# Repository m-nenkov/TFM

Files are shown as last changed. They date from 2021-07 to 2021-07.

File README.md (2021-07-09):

# TFM : Modelo y diseño de un sistema control de una estructura de dos grados de libertad

El repositorio presente corresponde al trabajo realizado para obetener el título de Máster Universitaro en Ingeniería de Sistemas Electrónicos en la UPM.

Este TFM se ha realizado en el laborratiro de Robótica y Control (Robolabo) de la ETSIT.

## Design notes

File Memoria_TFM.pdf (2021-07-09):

## UNIVERSIDAD POLITECNICA DE MADRID ´

ESCUELA TECNICA SUPERIOR ´
DE INGENIEROS DE TELECOMUNICACION´

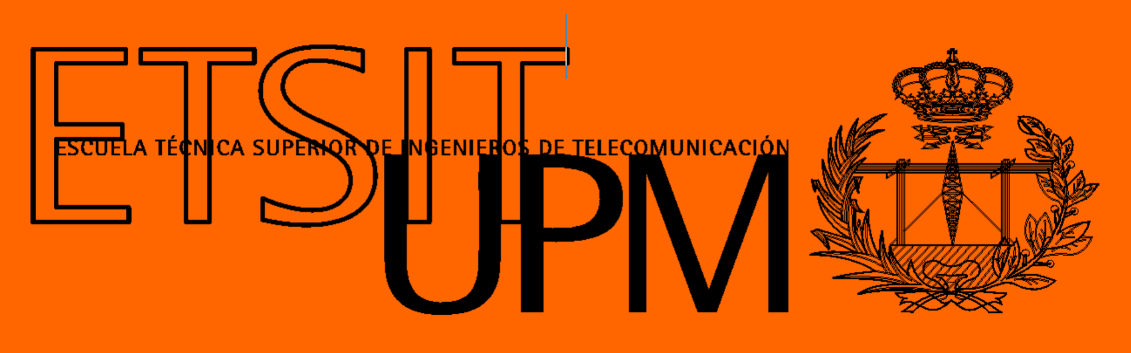
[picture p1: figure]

MASTER UNIVERSITARIO EN INGENIER ´ | ÍA DE

## SISTEMAS ELECTRONICOS ´

TRABAJO FIN DE MASTER ´

## MODELADO Y DISENO DE UN SISTEMA ˜

## CONTROL DE UNA ESTRUCTURA DE BALANCEO DE DOS GRADOS DE LIBERTAD

## MARTIN NENKOV GOROSTANOV

2021

## UNIVERSIDAD POLITECNICA DE MADRID ´

ESCUELA TECNICA SUPERIOR ´
DE INGENIEROS DE TELECOMUNICACION´

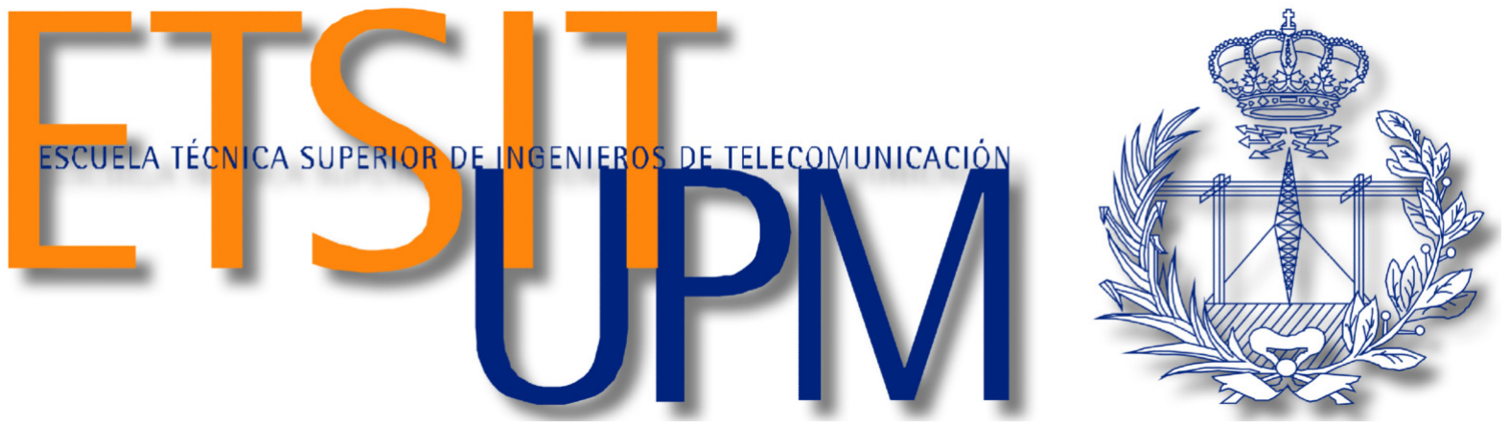
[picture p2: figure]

MASTER UNIVERSITARIO EN INGENIER ´ | ÍA DE

## SISTEMAS ELECTRONICOS ´

TRABAJO FIN DE MASTER ´

## MODELADO Y DISENO DE UN SISTEMA ˜

## CONTROL DE UNA ESTRUCTURA DE BALANCEO DE DOS GRADOS DE LIBERTAD

## Autor MARTIN NENKOV GOROSTANOV

## Tutor

ALVARO GUTI ´ | ERREZ MART ´ | ÍN

2021

Resumen

El control automatizado ha desempeñado un papel muy importante en el avance de la ingeniería en las últimas décadas. Es una parte fundamental de los sistemas robóticos, sistemas de vehículos autónomos y, en general, en cualquier proceso industrial en el que se requiera de un ajuste preciso de posición, temperatura, humedad, etc.

La ingeniería de control realiza un estudio de los sistemas físicos con el objetivo de desarrollar controladores capaces de dirigir estos sistemas hacia un estado objetivo. En la industria, la implementación de estos controladores se realiza por parte de los ingenieros electrónicos, mediante el uso de microcontroladores, que son los encargados de procesar la señal de entrada, calcular la acción de control y dar la orden a los actuadores.

Nuestra labor, como ingenieros electrónicos, está fuertemente ligada a este trabajo de implementación. Por lo tanto, es necesario conocer las distintas técnicas de control que existen, con el objetivo de realizar una implementación mas fluida e incluso para poder optimizar estos controladores o las arquitecturas en las que serán implementados.

En este Trabajo Fin de Máster se propone el control de una estructura de dos grados de libertad con el objetivo de analizar su respuesta real frente a la modelada y la viabilidad de la implementación del sistema. Para cumplir con el objetivo del proyecto, se ha decidido dividir el trabajo en varias etapas. Inicialmente, se propone realizar un análisis del modelado físico del sistema con el objetivo de conocer su respuesta temporal ante determinadas perturbaciones. A continuación, se realizará el diseño y simulación de los controladores con los que se propone realizar el control en posición de una esfera colocada en la estructura. Además, en este Trabajo Fin de Máster se propone el diseño de dos controladores, uno corresponde con la teoría de control clásica, que busca realizar un control temporal de los sistemas y un segundo controlador, basado en la teórica de control óptimo, en el que el objetivo es desarrollar un controlador que satisfaga una determinada función de coste. Por último, se realizará la implementación, ajuste y la validación del control en un microcontrolador.

vi

Abstract

Automated control has played a very important role in the advancement of engineering in recent decades. It is a fundamental part of robotics, autonomous vehicles and, in general, in any industrial process where precise control of position, temperature, humidity, etc. is required.

Control engineering studies physical systems with the aim of developing controllers capable of directing these systems towards a target state. In industry, the implementation of these controllers is carried out by electronic engineers, through the use of microcontrollers, which are responsible for processing the input signal, calculating the control signal and giving the order to the actuators.

Our work as electronic engineers is strongly related to this work. Therefore, it is necessary to know the different control techniques that exist, with the aim of making a smoother implementation and to be able to optimise these controllers or the architectures in which they will be implemented.

This Msc Thesis proposes the control of a structure with two degrees of freedom in order to analyse its real response compared to that modelled and the feasibility of the implemented solution. In order to fulfil the objective of the project, it is divided into several stages. Initially, it is proposed to carry out an analysis of the physical modelling of the system in order to determine its temporal response to certain disturbances. Next, the design and simulation of the controllers has to be done with which the control of the position of the sphere will be made. In addition, this Master’s Thesis proposes the design of two controllers, one corresponding to the classical control theory, which seeks to perform a temporal control of the systems and a second controller, based on the theory of optimal control, in which the objective is to develop a controller that satisfies a certain cost function. Finally, the control will be implemented in a microcontroller and its adjustment and validation will be carried out.

viii

´

# Indice general

Resumen | V
Abstract | VII
Índice General | IX
Índice de Figuras | XIII
Índice de Tablas | XV
Lista de Acrónimos | XVII
1. Introducción | 1
2. Modelado de un sistema Ball and Plate | 5
2.5.1.1. Sintonización del controlador mediante el LDR . . . . | 22
3. Descripción del hardware del sistema | 29

ix

x | ÍNDICE GENERAL
4. Diseño e implementación del sistema | 39
5. Resultados y validación del sistema completo | 59
6. Conclusiones | 67
Bibliografía | 72
A. Esquemáticos y circuito impreso de la tarjeta de expansión | 73
B. Diseño de las máquinas de estados finitas | 79
B.2. Cálculo de la acción de control y actuación sobre servo-motores . . . . | 80
C. Análisis del periodo de diferenciación | 83

ÍNDICE GENERAL | xi
D. Aspectos éticos, económicos, sociales y ambientales | 87
E. Presupuesto económico | 89

xii | ÍNDICE GENERAL

´

# Indice de figuras

2.1. Sistema de control en lazo cerrado | | 6
2.2. Representación de la estructura. Researchgate | | 7
2.3. Sistema realimentado en lazo cerrado. Dademuch | | 10
2.4. Representación del espacio de estados. Springer | | 12
2.5. Respuesta temporal de un sistema de segundo orden a una entrada
escalón. ELAI-UPM | | 14
2.6. Lugar de las raíces del sistema sin controlador | | 20
2.7. Sistema realimentado con controlador PID. Researchgate | | 21
2.8. Sistema realimentado con controlador LQR. Springer | | 24
3.1. Fotografía de la estructura mecánica del sistema | | 29
3.2. Relación entre ángulo del servo-motor y plataforma | | 30
3.3. Esquema del circuito resistivo de la pantalla táctil. Microchip | | 31
3.4. Fotografía de la cámara OpenMV Cam H7. OpenMV | | 32
3.5. Fotografía de un servo-motor. Bricogeek | | 34
3.6. Fotografía de la placa de desarrollo. STMicroelectronics | | 35
4.1. Diagrama de tiempos de la señal PWM para el control de los servo-
motores. PanamaHitek | | 44
4.2. Estructura del código implementado | | 45
4.3. Respuesta del sistema ante distintos periodos de muestro | | 47
4.4. Respuesta del sistema aplicando el controlador PD diseñado | | 48
4.5. Lugar de las raíces del sistema aplicando el controlador PD diseñado. . | 49
4.6. Respuesta del sistema aplicando el controlador PD diseñado | | 50
4.7. Angulo de la plataforma ante un escalón de 20 centímetros | ´ | 51
5.1. Respuesta del sistema ante el PD teórico | | 60
5.2. Acción de control del sistema ante el PD teórico | | 60
5.3. Respuesta del sistema ante el PD con ajuste de ganancia | | 61
5.4. Respuesta del sistema ante el PD con ajuste de cero | | 61
5.5. Respuesta del sistema ante el PD experimental | | 62
5.6. Respuesta del sistema formado por la cámara ante el PD teórico. . . . | 63
5.7. Respuesta del sistema formado por la cámara ante el PD experimental. 64
5.8. Respuesta del sistema con pantalla resistiva ante el LQR | | 64
5.9. Respuesta del sistema con cámara ante el LQR | | 65
A.1. Esquemático de la tarjeta de expansión | | 74

xiii

xiv | ÍNDICE DE FIGURAS

B.1. Diagrama de entradas y salidas de la máquina de toma de datos de los

B.2. Diagrama de estados de la máquina de toma de datos de los sensores. | 80
B.5. Diagrama de entradas y salidas de la máquina de envío de datos. . . . | 81

B.7. Diagrama de entradas y salidas de la máquina de recepción de comandos. 82 B.8. Diagrama de estados de la máquina de envío de recepción de comandos. 82

C.1. Señal de control del sistema ante diferentes periodos de muestreo. . . . 84 C.2. Respuesta del sistema ante el PD utilizado para el análisis del efecto

´

# Indice de tablas

4.1. Tiempos asociados a la ejecución de las tareas | | 54
4.2. Asignación de prioridades a las Tareas | | 55
4.3. Tiempos de respuesta de las Tareas | | 55
E.1. Costes de personal | | 89
E.2. Costes de recursos materiales | | 90
E.3. Costes totales | | 90

xv

xvi | ÍNDICE DE TABLAS

# Lista de Acrónimos

UPM : Universidad Politécnica de Madrid

ETSIT : Escuela Técnica Superior de Ingenieros de Telecomunicación

TFM : Trabajo Fin de Máster

LTI : Linear Time-Invariant

SISO : Single-Input Single-Output

MIMO : Multiple-Input Multiple-Output

PID : Proportional–Integral–Derivative

LQR : Linear–Quadratic Regulator

LDR : Lugar De las Raíces

I2C : Inter-Integrated Circuit

SPI : Serial Peripheral Interface

UART : Universal Asynchronous Receiver-Transmitter

USB : Universal Serial Bus

RAM : Random-Access Memory

PWM : Pulse-Width Modulation

RTOS : Real-Time Pperating System

FSM : Finite-State Machine

PCB : Printed Circuit Board

FIFO : First In First Out

HAL : Hardware Abstraction Layer

DMA : Direct Memory Access

GPIO : General Purpose Input/Output

SRAM : Static Random-Access Memory

xvii

xviii | LISTA DE ACRONIMOS ´

# Capítulo 1

# Introducción

## 1.1. Introducción a la ingeniería de control

El control automatizado ha desempeñado un papel muy importante en el avance de la ingeniería en las últimas décadas. Es una parte fundamental de los sistemas robóticos[1], sistemas de vehículos autónomos y, en general, en cualquier proceso industrial en el que se requiera de un ajuste preciso de posición, temperatura, humedad, etc.

Al comienzo del siglo pasado, se empiezan a desarrollar controladores para el guiado automático de embarcaciones[2][3], demostrando que es posible controlar de forma estable un sistema a partir de las ecuaciones diferenciales que describen su dinámica. A raíz de estos logros, surgieron teorías que analizaban la estabilidad del sistema en lazo cerrado con su respuesta en lazo abierto. Junto con esto, a mediados de siglo, se desarrollan métodos para observar y analizar la respuesta del sistema en frecuencia, dando la posibilidad de diseñar controladores lineales que satisfagan un amplio conjunto de especificaciones. Esta etapa inicial de la ingeniería de control se conoce como teoría de control clásica, en la que se hace uso de las técnicas comentadas anteriormente, junto con controladores PID realizar el control de sistemas lineales invariantes en el tiempo (LTI) con una entrada y una salida (SISO).

Con el avance de la industria, surgen máquinas más complejas, con respuesta variante en el tiempo y múltiples entradas (MIMO), que requieren de controladores más sofisticados. Debido a esto, surgen teorías de control modernas en las que se realiza un análisis en tiempo de los sistemas y se describe su comportamiento mediante variables de estado. Junto con el desarrollo de la industria, la ingeniería de control aumenta su complejidad desarrollando nuevas teorías, buscando controladores óptimos[4], intentando optimizar la respuesta según un criterio, robustos[5], con el objetivo de asegurar la respuesta del sistema real en un determinado punto de trabajo, o adaptativos[6], capaces de adaptar el controlador en función del estado del sistema.

1

2 1. Introducción

## 1.2. Motivación y objetivos del proyecto

Es fundamental que los ingenieros que realicen tareas de control estén familiariza-dos con las teorías de control que existen y los distintos tipos de controladores que se pueden implementar. Por este motivo, los alumnos de la asignatura de ingeniería de control deben disponer de sistemas reales en los que poder realizar la implementación y validación de estos controladores. La idea de diseñar e implementar un sistema en el que se puedan realizar estas laborares educativas resulta interesante desde el punto de vista pedagógico.

El sistema que se encuentra disponible en el Laboratorio de Control y Robótica de la ETSIT no dispone de información sobre los controladores que implementa o la forma en la que se realizado su ajuste. Por este motivo, para que este sistema permita su uso en el ámbito educativo es necesario realizar una documentación extensa de su diseño, implementación y validación.

En este Trabajo Fin de Máster se propone el control de una estructura de dos grados de libertad con el objetivo de analizar su respuesta real frente a la modelada y la viabilidad de la implementación del sistema. Para cumplir con los objetivo principal del proyecto, es necesario definir algunos objetivos secundarios, es necesario realizar el modelado físico del sistema, diseño y simulación de controladores, implementación del control y por último, el ajuste del sistema y la validación del mismo.

## 1.3. Estructura del documento

Este documento se divide en seis capítulos en los que se detallan todos los pasos que se han seguido, junto con los componentes necesarios para la realización de este Trabajo Fin de Máster.

En el Capítulo 1 se realiza una breve introducción al contexto del TFM y se exponen la motivación y los objetivos de este.

En el Capítulo 2 se detallan los conceptos teóricos en los que se fundamenta este TFM. En estos capítulos se realiza una introducción a las dos teorías de control aplicadas y se explican los conceptos básicos que son necesarios para comprender la implementación del sistema.

En el Capítulo 3 se exponen todos los componentes por los que se compone el proyecto, junto con las decisiones tomadas para su selección. Además, en este capítulo se detallan todos las decisiones relacionadas con el hardware diseñado.

En el Capítulo 4 se expone la metodología que se ha seguido en el proyecto, las principales líneas de trabajo y se desarrolla detalladamente cada una de las partes del sistema. En este capítulo se encuentra el diseño, modelado e implementación del

1.3. Estructura del documento | 3

sistema de control.

Por último, en los Capítulos 5 y 6 se exponen los resultados del proyecto junto con las conclusiones finales, además de incluir un apartado dedicado a posibles futuros trabajos.

4 1. Introducción

# Capítulo 2

# Modelado de un sistema Ball and Plate

Es necesario remontarse a la antigua Grecia para conocer los inicios de la ingeniaría de control. Los antiguos griegos, junto con los bizantinos y los romanos, emplearon sistemas de control para mantener los niveles de sus depósitos de agua, aceite y vino, respectivamente, estables. Para ello emplearon un sistema que, aunque antiguo, se sigue usando en la actualidad. Este sistema consistía en una esfera hueca que flotaba en el líquido y, que a su vez, controlaba el flujo de una válvula. De esta forma, cuando el líquido llegaba al nivel deseado, la válvula era cerrada de forma automática. Este sistema es idéntico al que se utiliza para el control de las cisternas de los inodoros en las casas. Desde entonces, la ingeniaría de control ha seguido desarrollando nuevos controladores, sobre todo gracias a la revolución industrial, capaces de controlar todo tipo de sistemas, desde el control de velocidad de máquinas de vapor hasta el aterrizaje autónomo de naves espaciales, pasando por sistemas de pilotaje automático, robots industriales, etc. En la actualidad existen métodos muy complejos de control capaces de predecir los cambios ambientales por medio de algoritmos de inteligencia artificial, de controlar sistemas no-lineales o, incluso, el desarrollo de los sistemas distribuidos permite un control descentralizado capaz de comunicar diferentes nodos con un objetivo único.

Como se ha comentado en el capítulo 1, existen diferentes estrategias para el control de un sistema. Este TFM se centra en la teoría de control clásica, basada en el análisis de la dinámica de los sistemas, y de control óptimo, centrada en el diseño de controladores que minimicen una determinada función de coste. Para ello se realizará el análisis del sistema siguiendo cada una de estas teorías y la implementación de un controlador de cada tipo.

5

6 2. Modelado de un sistema Ball and Plate

## 2.1. Introducción

El sistema que se pretende controlar es comúnmente conocido en la literatura anglosajona como Ball and Plate, en castellano, Bola y Plato. En este sistema, el objetivo es realizar el control en posición de una esfera maciza, normalmente de metal o de plástico, que se encuentra situada sobre un plato, o plataforma. Otra configuración similar es la que sólo dispone de un grado de libertad, llamada Ball and Beam, en castellano Bola y Viga. Ambas estructuras son comunes en el ámbito educativo, ya que permiten la implementación de una amplia variedad de controladores en una maqueta con un tamaño reducido. En la literatura se pueden encontrar diferentes métodos de adquisición de la posición de la esfera, como por ejemplo, el uso de pantallas resistivas, de cámaras con algoritmos de detección de objetos o, incluso, de sensores ultrasónicos. Por otro lado, para el control de la estructura se han desarrollado diferentes configuraciones mecánicas, como por ejemplo configuraciones en serie, en paralelo, etc.

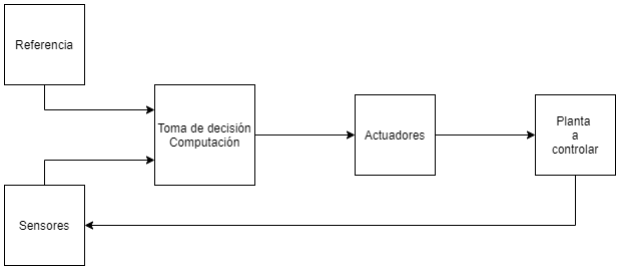
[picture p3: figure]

Figura 2.1: Sistema de control en lazo cerrado.

Generalmente los sistemas de control se componen de varios procesos. Inicialmente, es necesario la utilización de sensores que permiten conocer el estado actual del sistema. Posteriormente, se realiza un análisis de los datos tomados y, junto con la información que se dispone del sistema y del estado al que se desea llevar el sistema, se procesa la acción de control necesaria. Finalmente, ésta es comunicada al módulo encargado de controlar los actuadores, que perturban al sistema, modificando así su estado y comenzando de nuevo el ciclo. A este tipo de control se le conoce como control con realimentación en lazo cerrado ya que, como se observa en la Figura 2.1, se cierra el lazo de control gracias a los sensores, que realimentan el estado del sistema al controlador. Este tipo de configuración permite disminuir el efecto del ruido en el sistema y controlar sistemas originalmente inestables.

2.2. Modelado del sistema | 7

## 2.2. Modelado del sistema

El objetivo del modelado es describir el sistema mediante ecuaciones diferenciales que permitan conocer y controlar su comportamiento.

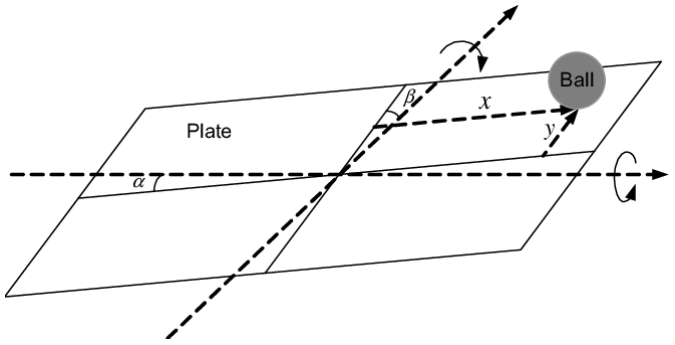
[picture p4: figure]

Figura 2.2: Representación de la estructura. Researchgate.

Antes de desarrollar las ecuaciones se necesario definir la estructura sobre la que se trabajará. Se observa en la Figura 2.2 un esquema de la plataforma con la que se desarrollará este TFM. En esta imagen se pueden observar algunas de las variables necesarias para realizar el control de la esfera. En este caso, las variables conocidas son el ángulo de la plataforma respecto al plano horizontal, definido como α, y la posición de la esfera en cada uno de los ejes, x e y.

Para realizar el análisis teórico de la estructura se aplica la primera ley de Newton, estos es, un cuerpo no puede cambiar por sí solo su estado inicial, ya sea en reposo o en movimiento rectilíneo uniforme, a menos que se aplique una fuerza o una serie de fuerzas. De forma simplificada, esta ley dice que un cuerpo se mantiene en reposo si la suma de las fuerzas que se le aplican es nula.

Para realizar un correcto análisis de la dinámica del sistema se ha realizado la suposición de que la esfera permanece en constante contacto con la plataforma sin que se produzca deslizamiento. De esta forma, toda la energía potencial que posee la esfera se transforma en energía cinética de traslación y rotación en torno al centro de masas. Es decir, las fuerzas que se ejercen sobre la esfera son aplicadas para modificar la velocidad de la esfera, sin pérdidas. Definida la estructura, los parámetros necesarios para su análisis y las leyes físicas con las que son consideradas en este caso, podemos obtener las ecuaciones que definen su mecánica:

XF = Ftras + Fin + Fg = 0 | (2.1)

Donde Ftras corresponde a la fuerza de traslación de la esfera, Fin, a la fuerza

8 2. Modelado de un sistema Ball and Plate

equivalente al momento de inercia que presenta la esfera en movimiento y Fg, la fuerza de la gravedad que es ejercida sobre la esfera.

La fuerza de traslación en un movimiento curvilíneo presenta dos componentes, una tangencial, definida por la aceleración lineal de la esfera, ẍ, y la masa de la esfera, m, y otra normal, definida por la masa de la esfera, la distancia de la esfera del centro de giro, x, y la velocidad angular de la estructura, ˙α, mediante la siguiente ecuación:

Ftras = F

t
tras + F

n
tras = m · x¨ − m · x · α˙

2
(2.2)

La fuerza de inercia queda definida mediante la siguiente ecuación por el momento de inercia de la esfera, Jb, el radio de la esfera, R, y su aceleración lineal, ẍ:

Fin =

Jb
R²
- x¨ | (2.3)

La fuerza de la gravedad, definida mediante la siguiente ecuación por la aceleración de la gravedad, g, la masa de la esfera, m, y el ángulo que forma el eje X de la estructura con la horizontal, α:

Fg = m · g · sen(α) | (2.4)

Desarrollando cada fuerza en su expresión física para uno de los ejes de la estructura y agrupando los términos, obtenemos:

m +

Jb
R²
x¨ − mxα˙
2 + mgsen(α) = 0 | (2.5)

En esta ecuación, se relaciona el ángulo de la plataforma, α, con la distancia de la esfera al centro, x, mediante su masa, m, su radio, R, su momento de inercia, Jb y la aceleración de la fuerza de la gravedad, g. Mediante la Ecuación 2.5 se puede definir completamente el comportamiento de la esfera ante las variaciones del ángulo de la plataforma. Desafortunadamente, esta ecuación no es lineal, por lo que para simplificar el modelado y su posterior control se necesario linealizar esta ecuación en un punto de trabajo. En este caso, el momento sobre el que se realiza este análisis corresponde al instante en el que la esfera se encuentra en una posición de reposo, es decir, cuando el ángulo de la plataforma es cero respecto de la horizontal.

Con este punto de trabajo, en el que sin(α) ≈ α, y ˙α = 0, se obtiene:

m +

Jb
R²
x¨ + mgα = 0 | (2.6)

2.2. Modelado del sistema | 9

Modificando el sistema de referencia, de tal forma que los ángulos positivos de la plataforma impliquen aceleraciones de la esfera hacia el exterior, se obtiene:

m +

Jb
R²
x¨ = mgα | (2.7)

Llegado a este punto se puede optar por dos caminos diferentes para la transformación de este modelo con el objetivo de prepararlo para el diseño de controladores. Por un lado, se realiza una transformación al dominio de Laplace con el objetivo de realizar un control clásico, mediante el análisis de la respuesta temporal del sistema. También es posible realizar un modelado en espacio de estados, para realizar un control enfocado a la optimización de algún factor del sistema. En las secciones posteriores se realizará el análisis en ambos métodos.

### 2.2.1. Representación en transformada de Laplace

Esta transformación forma parte de lo que se conoce como la teoría de control clásica, en la época en la que se pretendía analizar la estabilidad de los sistemas. Algunas técnicas mediante las que se conseguía este objetivo son el análisis del lazo abierto del sistema, el lugar de las raíces, el teorema de Nyquist de la estabilidad, etc.

A partir de la Ecuación 2.7 que describe el sistema mediante ecuaciones diferenciales, se realiza la transformada de Laplace con el objetivo de obtener una función con la que se pueda definir el comportamiento del sistema en el tiempo, e incluso en la frecuencia. Aplicando esta transformada se obtiene:

m +

Jb
R²
X(s)s
2 = mgA(s) | (2.8)

Reorganizando los términos con el objetivo de obtener una función de transferencia entre entrada, ángulo de la plataforma, y salida, distancia del centro a la esfera:

X(s)
A(s)

=

mg
(m +

Jb
R² )

1
s

2

(2.9)

Sabiendo que el momento de inercia de una esfera maciza se encuentra relacionada con su radio y su masa de la siguiente forma:

Jb =

2
5

mR²
(2.10)

Además, se sustituye la aceleración de la gravedad por su valor, con lo que

10 2. Modelado de un sistema Ball and Plate

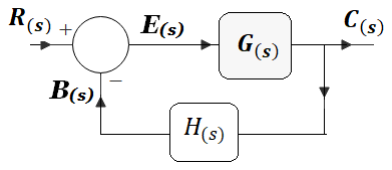
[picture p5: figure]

Figura 2.3: Sistema realimentado en lazo cerrado. Dademuch.

finalmente se obtiene:

X(s)
A(s)

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
(2.11)

Cabe resaltar el hecho de que la función de transferencia del sistema que se pretende controlar es totalmente independiente de la esfera que es colocada sobre la plataforma. Por otro lado, se observa que la función de transferencia presenta un polo doble en el origen, lo que hace al sistema críticamente estable. Dicho de otra forma, el sistema integra la señal de entrada, lo que hace imposible conseguir un control de la esfera con un control puramente proporcional.

Como se ha comentando anteriormente, la teoría clásica de control se basa en el análisis dinámico de los sistemas, por ello, una vez obtenida la función de transferencia del mismo, es necesario exponer algunas de los técnicas que se utilizan para realizar este análisis.

Antes de comenzar con este análisis es necesario definir una serie de conceptos. Como se ha visto al comienzo del capítulo, el control se realiza mediante la realimentación de la salida que, comparada con una referencia, es analizada por el controlador para obtener la acción de control. Como se puede observar en la Figura 2.3, la función de transferencia en el lazo directo es denominada G(s) y la función de transferencia del lazo de realimentación, H(s).

Siguiendo el esquema propuesto, se obtiene la función de transferencia que relaciona la salida del sistema, C(s), con la referencia, R(s):

C(s)
R(s)

=

E(s) · G(s)
E(s) + B(s)

=

E(s) · G(s)
E(s) + C(s) · H(s)

=

E(s) · G(s)
E(s) + E(s) · G(s) · H(s)

(2.12)

Y desarrollando la Ecuación 2.12 se obtiene la función final del sistema realimentado:

C(s)
R(s)

=

G(s)
1 + G(s) · H(s)

(2.13)

2.2. Modelado del sistema | 11

Por otro lado, es importante comentar que las raíces del numerador de la función de transferencia son los ceros y las raíces del denominador, los polos. Dadas las propiedades de la transformada de Laplace, los polos del sistema definen la naturaleza de la respuesta del régimen transitorio. Además, polos en el semieje positivo real suponen que el sistema presenta una respuesta inestable, es decir, ante cualquier señal de entrada, la salida del sistema crece indefinidamente. Teniendo esto en mente, es necesario realizar una análisis sobre la función 1+G(s)·H(s), ya que es el denominador de la función de transferencia y define el lugar de los polos del sistema.

### 2.2.2. Representación en modelo de variables de estado

La representación de los sistemas en el dominio de Laplace forma parte de la teoría de control clásica, en la que se pretende realizar el control de sistemas LTI y SISO. Con el avance de la industria, y sobre todo de los sector industrial, automoción, defensa y espacio, surgen máquinas con dinámicas muy complejas y que requieren del control de muchas variables para operar. Con la necesidad de controlar y analizar el comportamiento de estos sistemas surgen nuevas técnicas de representación de sistemas.

Una de las técnicas comúnmente utilizadas es el espacio de estados. Por medio de esta representación se definen variables de estado que presentan una determinada relación entre ellas y que, mediante su análisis temporal, permiten describir el comportamiento de sistemas complejos. Además, esta técnica permite el controlar y análisis de múltiples entradas y salidas en un mismo sistema.

Como el nombre de este modelo indica, es necesario definir una serie de estados. Para ello se puede observar la Ecuación 2.7 que describe el sistema. Para evitar confusiones más adelante, para este modelado se define a r como la distancia de la esfera al centro de la estructura. Desarrollando esta ecuación, se obtiene:

m +

Jb
R²
r¨(t) + 0 ṙ(t) + 0r(t) = mgα | (2.14)

Simplificando el momento de inercia a partir de la Ecuación 2.10, se obtiene:

7
5
r¨(t) + 0 ṙ(t) + 0r(t) = gα | (2.15)

A partir de la ecuación 2.15 se definen fácilmente los estados que son necesarios para este modelo, además de la relación que existe entre estos y la salida, r.

x1 = r x2 = ṙ | (2.16)

12 2. Modelado de un sistema Ball and Plate

Por lo tanto, se define la variación temporal de los estados de la siguiente forma:

x˙1 = ṙ x˙2 =

5g
7
α | (2.17)

Además, se puede representar la salida en función de los estados, de tal forma que:

y = x1 | (2.18)

Una vez definidos los estados, la relación entre ellos y su relación con la salida, se realiza una definición formal del sistema en el modelo de espacio de estados siguiendo el esquema de la Figura 2.4.

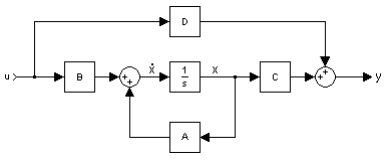
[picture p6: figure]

Figura 2.4: Representación del espacio de estados. Springer.

Por lo que las ecuaciones formales del modelo de espacio de estados son:

X˙ = AX + BU | Y = CX + DU | (2.19)

Como se puede observar en este modelo existe la posibilidad de realizar el control de un sistema con varias entradas y salidas, ya que todas las variables de este modelo son matriciales. Finalmente, se representa el sistema en el modelo de espacio de estados de la siguiente manera:
"
x˙ 1
x˙ 2
= X˙ = A · X + B · U =

"
0 1

0 0#
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
(2.20)

h
y

i
= Y = C · X + D · U =

h

1 0i
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
(2.21)

Sustituyendo los estados del modelo por las variables del sistema que son

2.3. Análisis de la respuesta de un sistema | 13

conocidas, se obtiene:
"
r˙
r¨
=

"
0 1

0 0#
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
(2.22)

h
r

i
=

h

1 0i
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
(2.23)

Cabe destacar que, por el modo en el que se ha definido el sistema en el espacio de estados, los estados son fácilmente observables. Esto es, los estados que seleccionados corresponden con la posición y la velocidad de la esfera y, por tanto, estas variables son conocidas.

## 2.3. Análisis de la respuesta de un sistema

Con carácter general los sistemas se analizan con tres tipos de respuesta temporal en función de la entrada del sistema. Son la respuesta al impulso, cuando la señal de entrada presenta la forma de la función delta de Dirac; la respuesta al escalón, cuando la señal de entrada presenta la forma de la función escalón de Heaviside, es decir, presenta un valor nulo en cualquier tiempo anterior a un instante t0 y un valor unitario para cualquier tiempo superior o igual a t0; y la respuesta a la rampa, de forma similar al escalón pero después del instante t0 la señal de entrada es creciente con pendiente constante. Estas son las señales de entrada más comunes debido a que con la primera, el impulso, se obtiene la respuesta del sistema ante una entrada puntual y muy energética y, la respuesta al escalón y a la rampa intentan representar el comportamiento del sistema ante una referencia en posición y velocidad respectivamente. Este TFM se centra en la respuesta al escalón, debido a que el objetivo es realizar un control de la esfera en posición. Por otro lado, para simplificar el desarrollo se realizará el análisis de un sistema de segundo orden, es decir, que posee dos polos. En general, la mayoría de sistema físicos permiten ser descritos mediante una función de segundo orden o inferior.

Representando un sistema de segundo orden con polos complejos conjugados con la transformada de Laplace, se obtiene la primera ecuación canónica:

G(s) = | kω² n

s

| 2 + 2ζωns + ω²
n

=

kω²
n
(s + σ)

2 + ω

2
d

(2.24)

En esta representación, los polos del sistema quedan definidos por ωn, la frecuencia natural del sistema y ζ, el coeficiente de amortiguamiento. Además, se puede observar que desarrollando esta ecuación se representan los polos por su componente real, σ, e imaginaria, ωd, en el dominio de Laplace.

14 2. Modelado de un sistema Ball and Plate

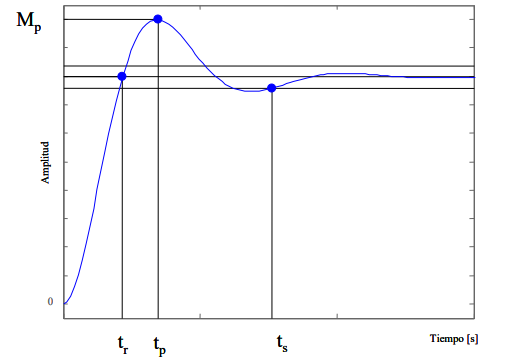
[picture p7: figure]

Figura 2.5: Respuesta temporal de un sistema de segundo orden a una entrada escalón. ELAI-UPM.

La Figura 2.5 representa la respuesta temporal de un sistema de segundo orden a una entrada escalón. Como se observa, ésta queda definida por varios parámetros. En primer lugar, el tiempo de subida, tr, correspondiente al tiempo en el que la salida del sistema alcanza por primera vez el valor final, Mp y tp, representando la sobreoscilación en tanto por ciento y el tiempo de pico en el que se alcanza respectivamente y el tiempo de establecimiento, ts, como el tiempo en el que la salida de sistema alcanza su valor final y se mantiene hasta el infinito.

Además, estos parámetros están directamente relacionados con los polos del sistema. Por lo tanto, si se consigue ajustar la posición de estos polos en el dominio de Laplace, se puede ajustar la respuesta del sistema según unas especificaciones dadas. Para obtener la relación que existe entre estos parámetros y la posición de los polos, es necesario realizar la transformada inversa de Laplace de la función de transferencia ante una entrada de tipo escalón.

La función en el dominio de Laplace que debe ser transformada se puede observar en la Ecuación 2.25.

Y (s) = G(s) · Fescalon(s) = | kω² n

s

| 2 + 2ζωns + ω²
n

·

1
s

=

kω²
n
(s + σ)

2 + ω

2
d

·

1
s

(2.25)

De esta forma, para realizar la transformada inversa de Laplace es necesario representar esta función en la suma de productos parciales de la siguiente forma:

Y (s) = A
s

+

Bs + C
(s + σ)

2 + ω

2
d

(2.26)

2.3. Análisis de la respuesta de un sistema | 15

Se obtiene el valor de A del siguiente modo:

A = Y (s) · s

s=0

=

k · ω

2
n
ω²
n
= k | (2.27)

Por otro lado, para obtener los valores de B y C, se sustituye el valor de A y se igualan las Ecuaciones 2.25 y 2.26:

Y (s) = kω² n (s + σ) 2 + ω

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
Bs + C
(s + σ)

2 + ω

2
d

(2.28)

De esta forma, igualando cada termino, se obtiene:

0 = k + B | (2.29)

en s

2
,
0 = 2kζωn + C | (2.30)

en s y

k · ω

2
n = k · ω

2
n

(2.31)

en s

0
. De las Ecuaciones 2.29 y 2.30 se obtiene los valores de B y C, respectivamente. Finalmente, en la Ecuación 2.32 se muestra la función descompuesta en una suma de productos parciales.

Y (s) = k
s

−

ks + 2kζωn
(s + σ)

2 + ω

2
d

(2.32)

Sabiendo que:

σ = ωn · ζ | (2.33)

y

ωd = ωn ·

p
1 − ζ
2 | (2.34)

16 2. Modelado de un sistema Ball and Plate

Se obtiene:

Y (s) = k
s

− k

s + 2σ
(s + σ)

2 + ω

2
d

(2.35)

Antes de realizar la transformación inversa de Laplace, es necesario modificar el segundo término de la ecuación. De esta forma, se obtiene:

Y (s) = k
s

− k

(s + σ) + √

ζ
1−ζ

2

- ωd

(s + σ)

2 + ω

2
d

= k

"
1
s

−

(s + σ) + √

ζ
1−ζ

2

- ωd

(s + σ)

2 + ω

2
d
(2.36)

Con todo esto, la función en el dominio del tiempo equivalente es:

y(t) = k

h
1 − e

−σt
·

cos(ωdt) + ζ
p
1 − ζ

2

- sen(ωdt)
i | (2.37)

Por otro lado, sabiendo que:

ζ = cos(φ) | (2.38)

y

p
1 − ζ
2 = sen(φ) | (2.39)

Se obtiene la siguiente ecuación:

y(t) = k

h
1 − e

−σt
·

cos(ωdt) + cos(φ)
sen(φ)
- sen(ωdt)
i | (2.40)

Sacando factor común sen(φ):

y(t) = k

h
1 −

e

−σt
sen(φ)

·

cos(ωdt) · sen(φ) + cos(φ) · sen(ωdt)
i | (2.41)

y sabiendo que

sen(ωdt + φ) = cos(ωdt) · sen(φ) ± cos(φ) · sen(ωdt) | (2.42)

2.3. Análisis de la respuesta de un sistema | 17

se obtiene la función en el dominio del tiempo que permite analizar la respuesta de un sistema de segundo orden:

y(t) = k

1 −

e

−σt
p
1 − ζ

2

sen(ωdt + φ)

(2.43)

Parar obtener el tiempo de establecimiento, es necesario comparar esta función con el valor en el régimen permanente. Suponiendo que se el objetivo es que la señal de salida se mantenga en un intervalo de ±5 % del valor final, se obtiene:

e

−σt
p
1 − ζ

2

≈ 0,05 = e

−π
(2.44)

Y, teniendo en cuenta que el factor de amortiguamiento, ζ, al cuadrado presenta valores muy inferiores a 1, se obtiene el valor de ts en función de la componente real del polo:

ζ

2 << 1 → ts ≈

π
σ

(2.45)

La sobreoscilación corresponde al valor máximo alcanzado en la respuesta temporal del sistema. Generalmente, se suele expresar como la relación entre el valor máximo frente al valor en el régimen permanente como un porcentaje. Por otro lado, el tiempo de pico es el instante en el que se produce este máximo. Para obtener el tiempo de pico, se debe obtener el máximo de la Ecuación 2.43 igualando su derivada a 0. Realizando el desarrollo de la derivada, reordenando, y resolviendo esta ecuación, se obtiene la relación del tiempo de pico con la parte imaginaria del polo:

dy(t)
dt = 0 → ωdtp = π → tp =

π
ωd

(2.46)

Sustituyendo este tiempo en la Ecuación 2.43 se obtiene la sobreoscilación:

Mp =

ymax − yinf

yinf

=

y(tp) − k
k

= e

−σπ
ωd = e

−π
tg(φ)
(2.47)

Cabe destacar que sólo habrá sobreoscilación si los polos del sistema son complejos conjugados sub-amortiguados. El límite en el que se produce la sobreoscilación se obtiene al comparar el tiempo en el que se produce el máximo de la respuesta(tp) con el momento en el que nuestra salida alcanza su valor en el régimen permanente(ts). Dicho de otra forma, si el tiempo de establecimiento es igual o inferior al tiempo de

18 2. Modelado de un sistema Ball and Plate

pico, no existe sobreoscilación. De esta forma, comparando la Ecuación 2.45 con la Ecuación 2.46, se obtiene:

ts < tp →

π
σ

<

π
ωd
→ ωd < σ | (2.48)

Se observa que el límite de la sobreoscilación se produce cuando la parte imaginaria del polo es igual a la real. De esta forma, se obtiene el valor del factor de amortiguamiento en el que se produce este fenómeno:

ζ = cos(φ) = σ
q
σ
| 2 + ω

2
d

=

σ
√
σ

2 + σ

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
(2.49)

Como se ha visto previamente, la sobreoscilación se produce cuando la parte imaginaria del polo presenta un valor superior a la real, es decir, sólo cuando 0 < ζ < √
2/2. De forma similar, si no hay sobreoscilación, no hay tiempo de pico.

El tiempo de subida corresponde al intervalo que tarda en pasar desde el 10 % hasta el 90 % del valor en régimen permanente del sistema. En este caso, para simplificar los cálculos, se obtiene el tiempo que se tarda en alcanzar el 100 % del régimen permanente desde la posición inicial:

e

−σt
p
1 − ζ

2

sen(ωdt + φ) = 0 → sen(ωdt + φ) = 0 | (2.50)

Por lo tanto, la relación entre el tiempo de subida y la posición del polo es:

ωdtr + φ = π → tr =

π − φ
ωd

(2.51)

## 2.4. Lugar de las raíces

El objetivo fundamental de la teoría de control clásica es analizar la estabilidad de los sistemas, por este motivo se han desarrollado métodos analíticos que permiten realizar este análisis. Una técnica muy utilizada es el lugar de las raíces (LDR). Este método permite obtener la respuesta del sistema en lazo cerrado mediante el análisis del mismo sistema en lazo abierto. Esta técnica presenta una gran ventaja frente a las demás, a parte de ser una técnica gráfica y por lo tanto tener una complejidad matemática reducida, permite observar el comportamiento del sistema cuando se produce una variación en un parámetro del mismo. Generalmente, este parámetro corresponde con una ganancia ajustable de la señal de error.

2.4. Lugar de las raíces | 19

Después de haber realizado una introducción sobre la respuesta temporal y haber obtenido el modelo del sistema, se realiza la descripción de la técnica del LDR, que permitirá colocar los polos del sistema en lazo cerrado en la posición deseada. Para realizar el LDR es necesario volver a la función de transferencia del sistema realimentado, que se puede observar en la Figura 2.3 y la Ecuación 2.13. A partir de esta ecuación, se puede observar que la respuesta temporal de este sistema queda definida por la ecuación 1 + G(s)H(s) = 0. De esta forma, se obtiene la respuesta temporal del sistema en lazo cerrado a partir de su función en lazo abierto, G(s)H(s).

Ambas funciones son complejas, por lo que se puede descomponer esta ecuación en dos, la primera correspondiente al argumento

|G(s) · H(s)| = 1 | (2.52)

y la segunda, al módulo

G(s) · H(s) = π(2n + 1) | n = 0, ±1, ±2, ±3, ... | (2.53)

Comprobando si estas dos ecuaciones se cumplen para cada uno de los puntos del plano se obtiene el lugar de las raíces del polinomio del denominador y, por lo tanto, el lugar de los polos del sistema y, posteriormente, su respuesta temporal. Realizar el cálculo para todos los puntos del plano pueden suponer un tiempo muy elevado, afortunadamente existen ciertas reglas que simplifican esta tarea significativamente:

1. Regla 1. Cada rama del LDR comienza en un polo del sistema en lazo abierto, con una ganancia nula, y termina en un cero cuando la ganancia es infinita. Por lo tanto, el número de ramas que existen en el LDR es igual al número de polos del lazo abierto, pero, además, si existen menos ceros que polos el un número de ramas es igual a la diferencia entre ceros y polo terminarán en el infinito.
2. Regla 2. Un punto del eje real pertenecerá al LDR si el número de polos y ceros a su izquierda, en el dominio de Laplace, es un número impar.
3. Regla 3. El LDR es simétrico.
4. Regla 4. La ramas del LDR que terminan en el infinito presentan un ángulo respecto del eje real

θ =

(2n + 1) · π
n − m
n = 0, ±1, ±2, ±3, ... | (2.54)

Con n el número de polos en el lazo abierto y m el número de ceros. Además, estas asíntotas cortan al eje real en el semieje negativo, en el punto:

σ =

Pparte real polos lazo abierto −

Pparte real ceros lazo abierto n − m | (2.55)

20 2. Modelado de un sistema Ball and Plate

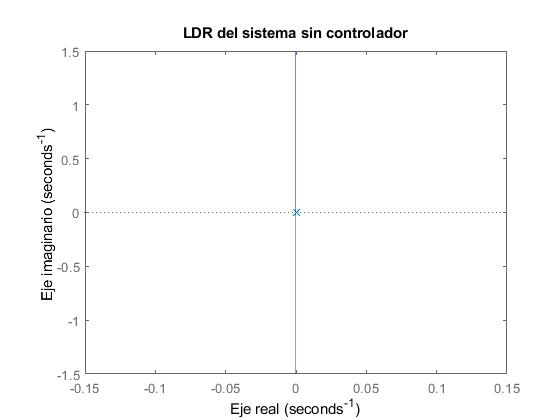
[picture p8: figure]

Figura 2.6: Lugar de las raíces del sistema sin controlador.

Finalmente, después de seguir todas las reglas y haber obtenido el lugar de las raíces de forma gráfica, se puede obtener el valor de k aplicando el criterio del módulo a un punto cualquiera:

1 + k|G(s) · H(s)| | => | k =

1
|G(s) · H(s)|

=

Q
|s + pi
Q
|s + zi

(2.56)

Una vez definida la forma en la que se realiza el LDR, se realizar el LDR del sistema a controlar, sin añadir ningún tipo de controlador externo. Para ello, siguiendo las reglas definidas anteriormente se observa el LDR obtenido en la Figura 2.6. En esta figura, se puede apreciar que el sistema es críticamente estable, es decir, que ante una entrada escalón oscilará de forma indefinida.

Teniendo en cuenta todo lo que se ha comentado sobre el LDR y su importancia para el control de los sistemas, en este sistema es necesario simplemente añadir un cero en lazo abierto de forma que se obtenga un sistema estable en lazo cerrado. Por lo tanto, el controlador más sencillo que se puede implementar deberá, al menos, tener un cero que permita realizar este ajuste.

## 2.5. Diseño de controladores

En este TFM se aplican dos teorías de control, por lo que va a ser necesario el uso de dos o más tipos de controladores. En esta sección se definirán los controladores que serán implementados en el sistema junto con las técnicas que son utilizadas para su obtención.

2.5. Diseño de controladores | 21

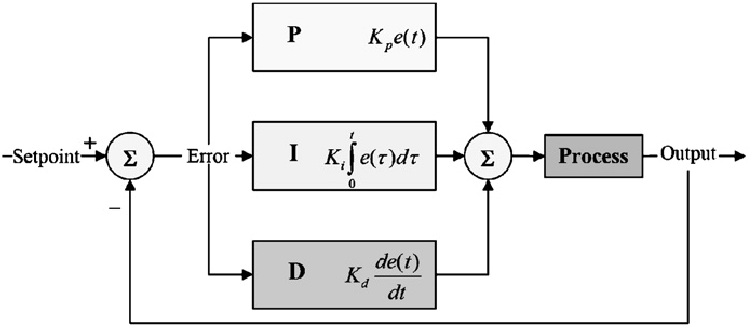
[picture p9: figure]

Figura 2.7: Sistema realimentado con controlador PID. Researchgate.

### 2.5.1. Controlador Proporcional-Derivativo-Integral

Como se comentó en el Capítulo 1 este tipo de controlador es descubierto en los inicios de la ingeniería de control, cuando el objetivo fundamental era el estudio y control de sistemas inestables LTI y SISO. Este controlador es el más utilizado en la industria, ya que existen métodos de sintonización automática sin necesidad de realizar un análisis analítico del sistema.

Un sistema controlado por PID basa su funcionamiento en la realimentación del error del sistema, esto es, la diferencia entre la salida actual del sistema y la consigna a la que se quiere llevar dicho sistema. Lo que realiza el controlador PID es proporcionar cierta ganancia a esta señal de error con el objetivo de modificar el comportamiento del sistema. Este controlador está formado por tres componentes: la componente proporcional, que es, como su nombre indica, una señal proporcional al error, la componente integral, que es proporcional a la integral del error, y la componente derivativa, que es proporcional a la derivada del error. Con la suma de estas tres componentes se obtiene la acción de control con la que se alimenta al sistema.

U(s) = [Kp + Kds + Ki

1
s
] · E(s) | (2.57)

En la Ecuación 2.58 se observa la forma que tiene este controlador en el dominio de Laplace. Desarrollando esta ecuación, se puede obtener la función con la que se realiza la sintonización analítica de este controlador por medio del LDR. En esta ecuación se observa que el controlador añade al sistema dos ceros ajustables y un polo en el origen.

Gc(s) = U(s)
E(s)

= Kp + Kds + Ki

1
s

=

Kds

2 + Kps + Ki

s

(2.58)

Este tipo de controlador proporciona dos ceros ajustables mediante las ganancias del controlador y un polo en el origen. Para realizar un ajuste exacto del controlador, habiendo definido previamente una serie de especificaciones que se desean cumplir,

22 2. Modelado de un sistema Ball and Plate

es necesario realizar un análisis extenso del LDR con el objetivo de hallar la posición en la que se deberían colocar los polos del sistema realimentado. Una vez realizada esta tarea, simplemente habría que definir la ecuación de segundo grado que satisface esas condiciones. A continuación, el paso para obtener las ganancias de los distintos componentes del controlador es inmediato. Normalmente este análisis se realiza con un programa de computación por ordenador como MATLAB, pero es importante que los ingenieros que realizan este tipo trabajos sean conscientes de como se realiza de forma analítica.

### 2.5.1.1. Sintonización del controlador mediante el LDR

Realizar un análisis del LDR y sintonizar las variables del controlador no es una tarea simple, sobre todo cuando se trabaja con un controlador PID completo. Por este motivo, para facilitar esta tarea y debido a que el sistema no requiere un controlador complejo para ser estable, se realizará la sintonización de un controlador PD, que aporta un cero ajustable. Este controlador tiene la siguiente función de transferencia:

Gc(s) = Kp + Kds = Kp(1 + Kd Kp

s) = Kd(s +

Kp
Kd
) | (2.59)

Obteniendo así un cero real, en Kp
Kd

, ajustable y una ganancia, Kd, también ajustable. En este caso, presenta dos parámetros que deben ser ajustado para conseguir las especificaciones deseadas.

Partiendo de dos de los parámetros más importantes para describir la respuesta temporal de un sistema, esto es, el tiempo de establecimiento y la sobreoscilación, se obtiene la posición del polo dominante del sistema realimentado.

ts =

π
σ

→ σ =

π
ts

(2.60)

Teniendo la posición en el eje real del polo, con la sobreoscilación se obtiene la posición del polo en el eje imaginario:

Mp = e

−σπ
ωd → ωd =

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
) · ts

(2.61)

Aplicando el criterio del ángulo, se obtiene la posición, a, en la que se debe colocar el cero para que el polo dominante se encuentre en el LDR.

X ceros−
X polos = tan⁻¹
(

ωd
σ − a

)−2tan⁻¹
(

ωd
σ
) = π(2n+1) | n = 0, ±1, ±2, ...
| (2.62)

2.5. Diseño de controladores | 23

Resolviendo, para despejar a, se obtiene:

a = [tan(π(2n + 1) + 2tan⁻¹ (

ωd
σ
)) · ωd] + σ | n = 0, ±1, ±2, ±3, ... | (2.63)

Una vez hallada la posición del polo, es necesario aplicar el criterio del módulo para obtener el valor de la ganancia necesaria:

|K| =

Q
(s + pi)
Q
(s + zj )

=

q
ω

2
d + σ

2 ·

q
ω

2
d + σ

2
q
ω

2
d + (σ − a)

2

(2.64)

Finalmente, habiendo obtenido la posición del polo, a, y la ganancia que debe tener el sistema en el lazo abierto, K, en función de la posición del polo que previamente se ha obtenido y a partir de las especificaciones deseadas, se calculan los dos parámetros del controlador:

Kd =

K
7

(2.65)

−

Kp
Kd

= a → Kp = −Kd · a = −

K · a
7

(2.66)

El factor 1
7

es a causa de la ganancia que presenta la función de transferencia del sistema. Hay que tener en cuenta que no se esta calculando la ganancia del controlador si no la ganancia del lazo abierto, que incluye las funciones de transferencia del controlador y del sistema. Por otro lado, hay que tener en cuenta que para sistemas con respuesta estable los polos se encuentran en el semieje negativo. Por este motivo, para obtener un valor de ganancia positiva se ha añadido el signo negativo en la Ecuación 2.66.

### 2.5.2. Regulador cuadrático-lineal (LQR)

A los ingenieros de control, después de controlar de forma exitosa sistemas que por su naturaleza eran inestables, les surge el deseo de optimizar estos controladores [7]. Inicialmente, la labor de investigación se centró en conseguir controladores que fuesen óptimos desde algún punto de vista, por ejemplo, el de minimizar las variaciones en la acción de control, de esta forma se puede reducir el consumo de los dispositivos o incluso abaratando su coste, ya que requerirían menor potencia para operar, por lo tanto se podrían fabricar con componentes de menor precio.

A esta rama de la ingeniería de control se le conoce como teoría de control óptimo, y el controlador más utilizado es el regulador lineal cuadrático, o linear–quadratic

24 2. Modelado de un sistema Ball and Plate

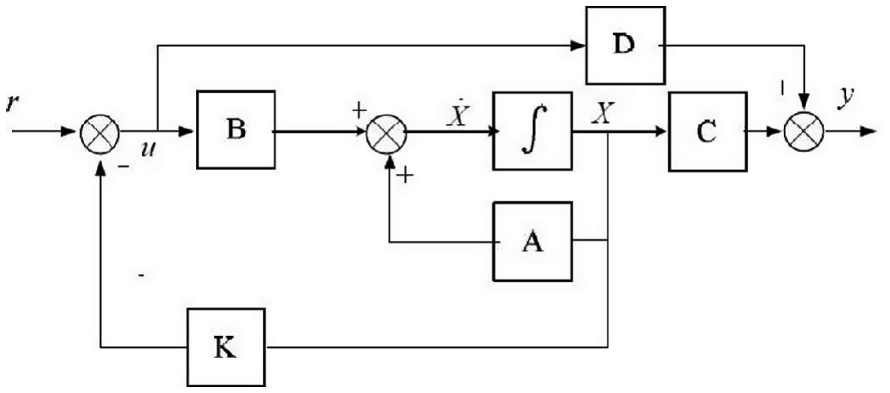
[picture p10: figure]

Figura 2.8: Sistema realimentado con controlador LQR. Springer.

regulator (LQR) en inglés. De forma similar al controlador PID, este controlador se basa en la realimentación, pero en este caso no del error, si no de las variables de estado.

Como se observa en la Figura 2.8 la realimentación se produce restando a la señal de consigna, t, el valor de las variables de estado, X, con una cierta ganancia, K. El ajuste de esta matriz de realimentación es la que permite realizar un control óptimo sobre la señal de salida, y, o la de control, u.

Como se ha comentado, esta rama de la ingeniería de control se basa en el diseño de controladores óptimos, en los que no sólo se realiza un control de la salida si no también de la entrada. Por este motivo, se define la función de coste que se desea optimizar:

J =

Z ∞

0

x

T
(t) · Q · x(t) + u(t)

T
- R · u(t) dt | (2.67)

En esta ecuación se observa que tanto la entrada, u(t), como los estados, x(t), están presentes. Las matrices R y Q corresponden con el coste de la acción de control y los estados respectivamente, de esta forma, modificando sus valores se pueden obtener diferentes comportamientos del sistema.

Para optimizar esta acción de control se realiza la realimentación de los estados. De esta forma, se obtiene la acción de control, en la que se omite la referencia(r ) del sistema. Esto es debido a que en régimen permanente éste presenta un error nulo, independiente de la señal de entrada. De no ser así, la función de coste tendería a infinito, lo cuál no sería una solución óptima.

u(t) = −Kx(t) | (2.68)

2.5. Diseño de controladores | 25

Por lo que se obtiene un nuevo modelo del sistema, definido por:

X˙ = AX − B · KX = (A − B · K)X | (2.69)

Además, sustituyendo la Ecuación 2.68 en la Ecuación 2.67, se obtiene la función de coste que se pretende optimizar:

J =

Z ∞

0

x

T
(t)Qx(t) + x

T

(t)KT RKx(t) dt =

Z ∞

0

x

T

- (Q + KT RK) · x dt (2.70)

Siendo P una matriz simétrica real o hermética definida positiva que cumple la siguiente igualdad para todos los valores de x, es decir, para cualquier estado del sistema:

J = x

TP x | (2.71)

Desarrollando esta integral, se obtiene la siguiente ecuación:

x

T

(Q + KT RK)x = −

d
dt(x
TP x) | (2.72)

Desarrollando esta ecuación, se obtiene:

x

T

(Q + KT RK)x = −x˙

TP x − x

TPx˙ = −x

T
[(A − BK)P + P(A − BK)]x (2.73)

Por tanto, se obtiene la ecuación que minimiza la función de coste:

(A − BK)

TP + P(A − BK) = −(Q + KT RK) | (2.74)

De esta forma, resolviendo la Ecuación 2.74 se obtiene un controlador que satisfaga el problema del control óptimo. Para obtener esta solución se define una matriz R simétrica real o hermética definida positiva, tal que:

R = T

T T | (2.75)

Tomando esto en cuenta, se reescribe la Ecuación 2.74 de la siguiente forma:

(A

T − KT B

T

)P + P(A − BK) + Q + KT T

T TK = 0 | (2.76)

26 2. Modelado de un sistema Ball and Plate

Desarrollando y reorganizando esta ecuación, se obtiene:

A

TP +P A+[TK−(T

T
)

−1B
TP

T
]

T
[TK−(T

T
)

−1B

TP]−P BR⁻¹B
TP +Q = 0 (2.77)

Si uno de los objetivos es la minimización de J respecto de K, es necesario realizar la minimización de

x

T
[TK − (T

T
)

−1B
TP

T
]

T
[TK − (T

T
)

−1B
TP]x | (2.78)

con respecto a K. Se observa que en esta ecuación se produce un mínimo en cero, cuando

K = T

−1
(T

T
)

−1B
TP = R

−1B
TP | (2.79)

En consecuencia, una vez obtenida la solución deseada, se sustituye en la Ecuación 2.68 para obtener la acción de control que requiere el sistema:

u(t) = −Kx(t) = −R

−1B
TP x(t) | (2.80)

Además, la matriz P debe satisfacer la Ecuación 2.76, con lo que sustituyendo en esta la Ecuación 2.79, se obtiene:

A

TP + P A − P BR⁻¹B
TP + Q = 0 | (2.81)

Esta ecuación recibe el nombre de ecuación reducida de Ricatti. Con esta ecuación, los pasos que hay que seguir para diseñar un controlador LQR son sencillos. Inicialmente es necesario resolver la ecuación de Ricatti para obtener le valor de P que satisfaga las especificaciones que se han definido a través de las matrices Q y R. Posteriormente, sustituyendo esta matriz en la Ecuación 2.80 se obtiene la matriz K con la que se realimenta el sistema para obtener la respuesta deseada.

### 2.5.2.1. Ajuste empírico del controlador LQR

En el apartado anterior se ha mencionado que las matrices Q y R son fundamenta-les para la selección de la matriz de realimentación de estados, K, que son necesarios para realizar el control del sistema. Sin embargo, no se ha definido cuales son las implicaciones de modificar estas matrices. Aunque resulta intuitivo observando la Ecuación 2.67, la función que desempeñan estas matrices es fundamental para diseñar el controlador LQR.

2.5. Diseño de controladores | 27

Estas matrices están directamente relacionadas con el peso que se le proporciona a cada uno de los estados y a la acción de control en la función de coste. Es decir, mediante un ajuste de esta matrices se modifica la acción del sistema. Por ejemplo, para reducir de forma considerable la acción de control, reduciendo así el coste energético o, incluso, dando la posibilidad de hacer uso de actuadores menos potentes.

Con este controlador se consigue adaptar la respuesta del sistema a las características físicas de éste. Por ejemplo, permite diseñar directamente un controlador que trabaje en la zona de lineal de los sistemas y, por lo tanto, que la respuesta no se vea afectada por la saturación de los actuadores o de los sensores, entre otros efectos. Esto es una gran ventaja, ya que permite modificar el controlador en función del estado de los dispositivos que conforman el sistema.

Una gran desventaja de este tipo de controladores es que no existe un método analítico con el que seleccionar las matrices Q y R. Existen técnicas comúnmente utilizadas para el ajuste de estas matrices, como por ejemplo, definir R como una matriz identidad y Q = C

T C. Pero el método más adecuado es el uso de herramientas de simulación como MATLAB, que permiten observar el comportamiento del sistema realimentado y el ajuste de estos valores de forma que la respuesta de este sea la deseada.

28 2. Modelado de un sistema Ball and Plate

# Capítulo 3

# Descripción del hardware del sistema

Este capítulo detalla los componentes por los que está formado el sistema, desde los sensores encargados de realizar la obtención de la posición de la esfera hasta el sistema encargado de realizar el movimiento de la estructura, pasando por el microcontrolador, encargado de realizar todos las operaciones asociadas al control del sistema.

## 3.1. Estructura mecánica

Como ya se ha comentado anteriormente, en este TFM se realiza el control de una estructura de dos grados de libertad.

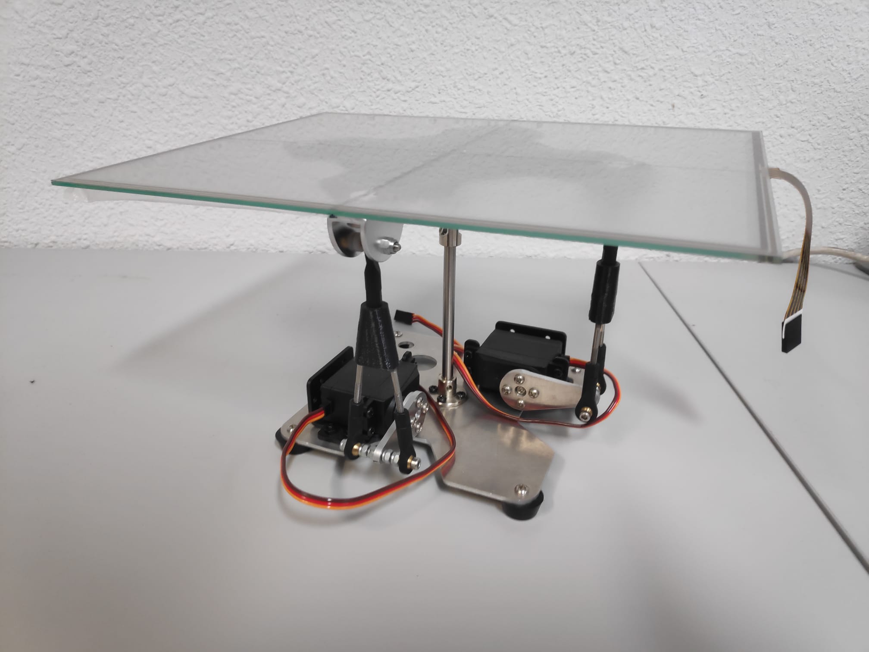
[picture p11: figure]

Figura 3.1: Fotografía de la estructura mecánica del sistema.

29

30 3. Descripción del hardware del sistema

Se observa en la Figura 3.1 que esta estructura está formada por una bandeja, en la que se posicionará la esfera, y cuyo ángulo respecto del plano horizontal es controlado por dos motores eléctricos, uno para cada eje. Como se ha visto en el Capítulo 2, el control se realiza sobre el ángulo de la plataforma, pero el ángulo sobre el que realmente se puede actuar, es el ángulo de los motores. Por este motivo, es necesario realizar un ajuste previo al control. Para analizar la relación entre estos dos ángulos se ha realizado un modelo mecánico utilizando el módulo Simscape de Simulink.

Esta herramienta permite definir la estructura del sistema en un entorno de simulación, y realizar un análisis detallado de la relación de ambos ángulos. En la Figura 3.2 se muestra la relación que existe entre estos dos ángulos, además de una estimación polinómica de esta.

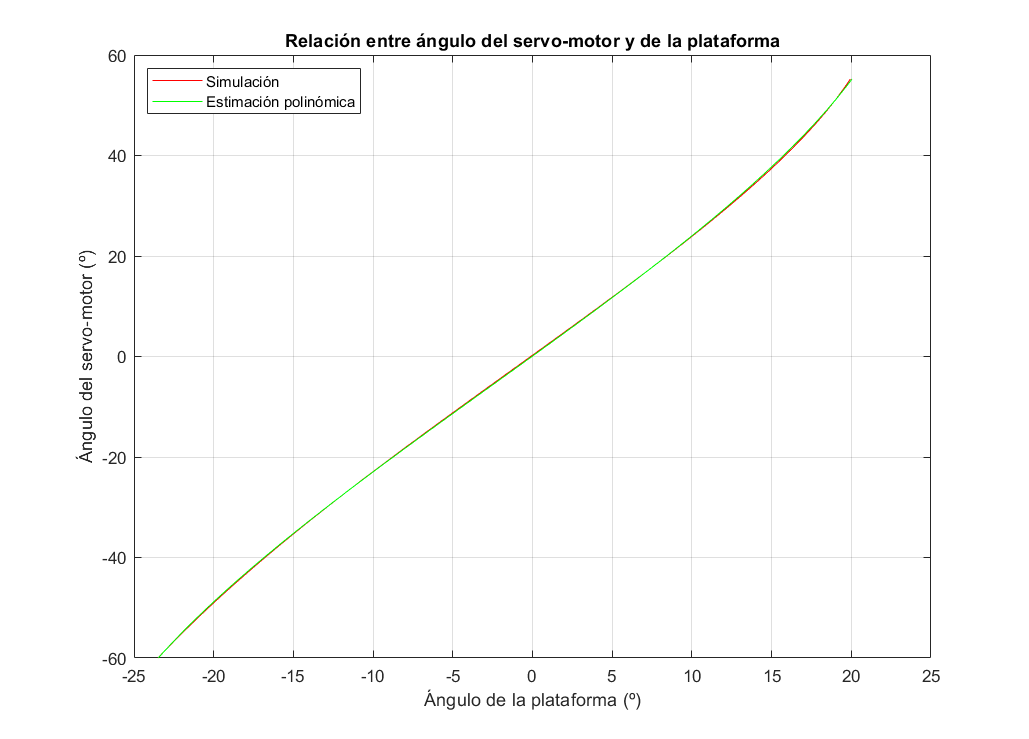
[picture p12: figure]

Figura 3.2: Relación entre ángulo del servo-motor y plataforma.

A partir de esta simulación, se ha realizado el análisis y control directamente sobre la plataforma, realizando un abstracción del mecanismo por el cuál se obtiene esta inclinación. De esta forma, permite realizar un modelado más sencillo, y por lo tanto, reducir la complejidad asociada al diseño del controlador.

## 3.2. Sensores

Una vez visto el sistema mecánico, es necesario realizar la selección de los componentes electrónicos del sistema. En este TFM es necesario realizar el control de la posición de una esfera. Por lo tanto, existe la necesidad de componentes capaces de proporcionar estos datos. Se ha decidido que para cumplir esta función se hará uso de dos sistemas, uno basado en una pantalla resistiva y otro en el uso de una cámara.

3.2. Sensores | 31

### 3.2.1. Pantalla resistiva

En este caso, este sistema de medida consiste un cristal en el que se encuentran integrados cuatro hilos conductores en los lados. Como se puede observar en la Figura 3.3, mediante la alimentación de los hilos superior e inferior se puede realizar la medida de la tensión en uno de los conductores laterales. De estado forma, obtiene la posición, en el eje vertical, del objeto que se encuentre en contacto con la pantalla. De forma análoga, se obtiene la posición en el eje horizontal, alimentando los hilos laterales y midiendo la tensión en uno de los dos hilos restantes.

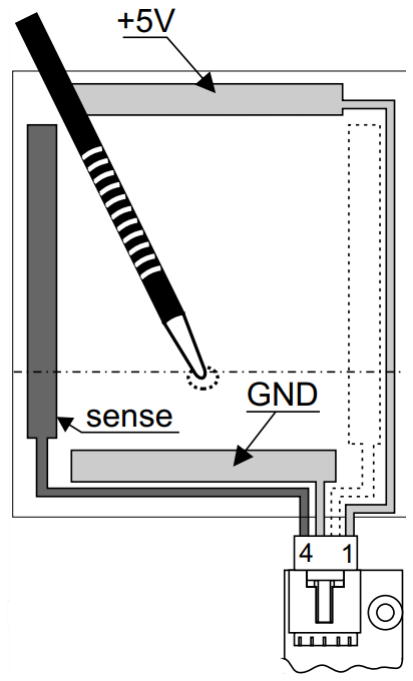
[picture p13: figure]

Figura 3.3: Esquema del circuito resistivo de la pantalla táctil. Microchip.

Este sistema presenta varias desventajas, la primera, es que es necesario disponer de un controlador que gestione la alimentación y medida en cada uno de los ejes, la segunda tiene relación con el periodo mínimo de muestro que se puede alcanzar, dependiente de las capacidades parásitas del sistema y, por último, sólo debe haber un objeto en contacto con el cristal, si no es así, la medida que se obtendría sería errónea.

En este caso, el único problema que provoca un efecto negativo es el primero, debido a que es necesario un sistema encargado de tomar las medidas del sensor. Para solucionar esto, existen dos alternativas, la primera es adquirir directamente un controlador para pantallas resistivas y la segunda consiste en realizar el circuito necesario para la alimentación del sensor y realizar el control directamente en el microcontrolador. La única ventaja que presenta la implementación propia del

32 3. Descripción del hardware del sistema

controlador, es que permitiría obtener un período de muestreo más reducido que con la primera, a costa de eliminar la comunicación entre los dos sistemas y aumentar la carga computacional del microcontrolador. Debido a la complejidad asociada a esta solución se ha decido adquirir directamente un controlador comercial para pantallas resistivas.

El sistema encargado de tomar las mediadas de la pantalla y trasmitirlas al microcontrolador será el controlador de pantallas resistivas de la serie AR1000 de Microchip. Este controlador permite el control de pantallas de hasta 8 hilos conductores con un tiempo de muestro típico de 7ms. Además, dispone de comunicación por I2C, SPI y/o UART.

### 3.2.2. Cámara

Se ha decidido implementar un segundo método para la detección de la posición de la esfera. Este método consiste en el uso de una cámara que se encuentra posicionada sobre la estructura. Para realizar la detección de la esfera, es necesario aplicar algoritmos de visión artificial. En este caso, al ser el objeto detectado una esfera, que en las imágenes obtenidas se muestra como un objeto en 2D, es necesario el uso de métodos para la detección de círculos.

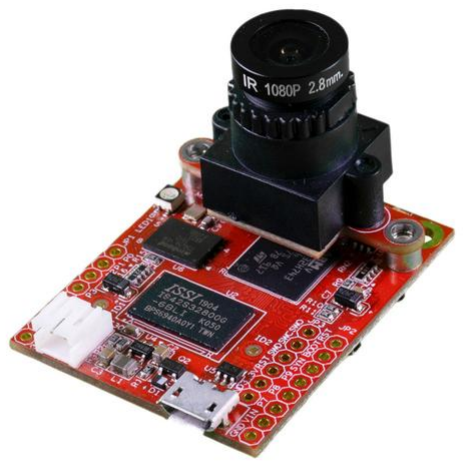
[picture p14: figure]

Figura 3.4: Fotografía de la cámara OpenMV Cam H7. OpenMV.

Este algoritmo se basa en la transformada de Hough para la detección de geometrías en imágenes. La identificación de los bordes, o de geometrías, en una imagen se puede describir como la variación de la intensidad en una orientación particular. Cuanto mayor sea esta variación, mayor será la posibilidad de que se

3.3. Actuadores | 33

corresponda con un borde de un objeto. Por lo tanto, matemáticamente, se puede definir esta variación como el gradiente de la intensidad en una dirección particular. Teniendo esto en consideración, y simplificando, se define que la transformada de Hough se basa en el análisis del gradiente de la intensidad en una dirección en particular. Por lo tanto, para facilitar la labor del algoritmo, es necesario que exista gran contraste entre los objetos a detectar y el fondo de la imagen, en este caso, entre el color de la esfera y de la plataforma.

De forma similar al caso anterior, existe dos posibles alternativas para la implementación de este sistema de medida, una en el que nuestro microcontrolador es el encargado de realizar la adquisición y procesado de la imágenes y, otra en la que un controlador auxiliar es el encargado exclusivamente de esta tarea. A diferencia del caso anterior, no cabe duda que de el método por el que se ha optado es el segundo. Esto se debe a que para realizar la implementación de la primera solución es necesario realizar un trabajo extenso que se sale de los objetivos y alcance de este TFM, que incluye el uso de controladores mucho más potentes y de algoritmos de visión artificial complejos. Con todo esto, se ha decidido que el controlador y cámara a utilizar se encuentran integrados en el sistema comercial OpenMV Cam H7.

Este sistema dispone de un microcontrolador ARM Cortex-M7 que funciona a una frecuencia de 408MHz con 1MB de RAM y 2MB de memoria flash. Este microcontrolador dispone de un bus USB, de hasta 12Mb/s, I2C, de hasta 1Mb/s, UART, de hasta 7.5Mb/s, y SPI, de hasta 80Mb/s. Este controlador es el encargado de obtener y procesar las imágenes obtenidas de un sensor óptico OV7725 capaz de proporcionar imágenes en escala de grises de hasta 640x480 píxeles con una velocidad de 75 fotogramas por segundo. Este sistema permite la ejecución de programas en el lenguaje de programación de alto nivel MicroPython, lo que facilita la implementación de algoritmos de detección de objetos.

## 3.3. Actuadores

Para realizar el control de un sistema es fundamental disponer de instrumentos de medida que permitan conocer el estado actual del sistema, pero es igual de importante el uso de dispositivos que sean capaces de alterar su estado de la forma en la que se desee en cada momento. Por este motivo, la selección de actuadores no es trivial y es necesario dedicar tanto o más tiempo que a la selección de sensores.

Por las características de este TFM, es necesario el uso de motores eléctricos, preferiblemente capaces de realizar un ajuste preciso del ángulo. Por este motivo, y como se ha podido apreciar anteriormente, para el control de la estructura se hará uso de motores de corriente continua que permiten un control directo sobre su ángulo de actuación. A este tipo de actuadores comúnmente se les conoce como servo-motores.

Este tipo de actuadores integran un controlador que permite realizar un control

34 3. Descripción del hardware del sistema

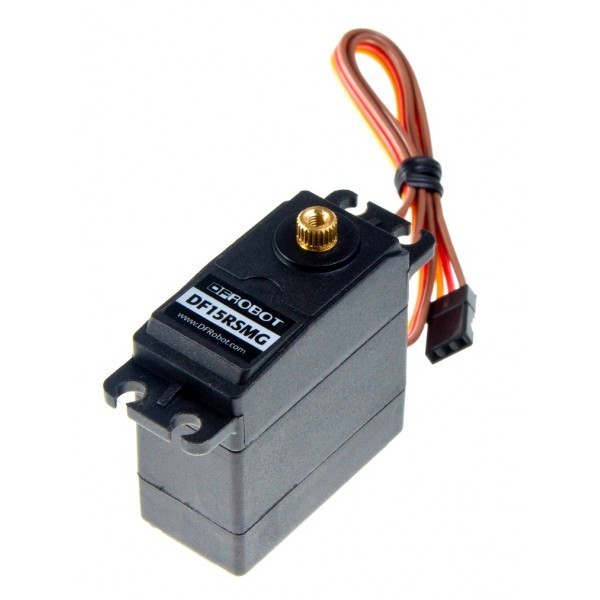
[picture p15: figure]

Figura 3.5: Fotografía de un servo-motor. Bricogeek.

preciso de su posición sin necesidad de lógica de control externa. Una característica, fundamental para este proyecto, es que presentan un par motor elevado, que, junto con un control preciso de su ángulo, los hacen especialmente útiles en tareas de control.

## 3.4. Microcontrolador

El microprocesador será el encargado de gestionar la comunicación con los sensores y actuadores, del procesado de las señales que le llegan de los sensores y del cálculo de la acción de control necesaria en cada momento. Teniendo en cuenta estas tareas, es necesario que el procesador disponga al menos de un periférico de comunicación (UART, I2C o SPI) junto dos temporizadores para la gestión de las señales de tipo PWM necesarias para el control de los actuadores. A parte de estos requisitos, es deseable que el microprocesador seleccionado disponga de unas prestaciones suficientes, de computo y de memoria, para poder ejecutar un sistema operativo en tiempo real, algo que facilita la integración de todos los componentes y permitirá la implementación de los controladores.

Por lo motivos comentados anteriormente se ha decido que el microprocesador que se utilizará en el desarrollo del proyecto es el ARM Cortex-M4, ya que proporciona una solución de bajo coste cumpliendo los requisitos del proyecto. Para ello, la implementación del sistema se realizará haciendo uso de la plataforma de desarrollo STM32L476RG que integra el microcontrolador seleccionado, y que se encuentra disponible para su uso en el Laboratorio de Robótica y Control.

Este microcontrolador funciona a una frecuencia máxima de 80MHz e incluye una unidad de coma flotante. Dispone de 128KB de RAM y 1MB de memoria flash, además, incluye periféricos de comunicación I2C, SPI, UART, junto con una interfaz de programación y depuración a través de USB.

Además de lo mencionado anteriormente, este microprocesador incluye un regula-

3.5. Desarrollo de la tarjeta electrónica | 35

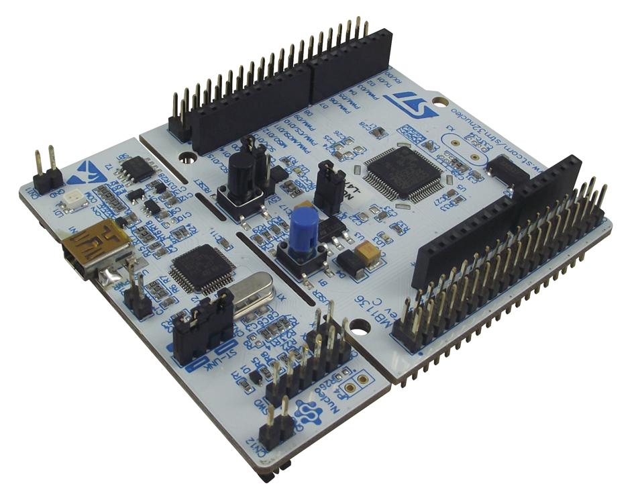
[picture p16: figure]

Figura 3.6: Fotografía de la placa de desarrollo. STMicroelectronics.

dor de voltaje que, junto con la posibilidad de regular la frecuencia de funcionamiento, permite el uso de siete modos de potencia. Esta funcionalidad lo hace idóneo para la implementación en tareas en las que el consumo es un factor clave en el diseño del sistema.

## 3.5. Desarrollo de la tarjeta electrónica

En las secciones anteriores se han descrito los componentes que se van a utilizar en la implementación del sistema. Para la integración de todos estos elementos en un sistema único se ha desarrollado una tarjeta de expansión, que además, debe ser compatible con la tarjeta de desarrollo utilizada. En esta tarjeta de expansión se encontrarán tanto los componentes electrónicos como los conectores a los dispositivos externos, como los servo-motores o la cámara.

Para el diseño de la tarjeta de expansión se ha utilizado el entorno Altium Desig-ner. Este programa permite el diseño de componentes, la captura de esquemáticos y diseño de circuitos impresos. Incorpora, en una sola aplicación, un sistema que permite la gestión del entorno de desarrollo y la comunicación del usuario con los servidores que contienen la información sobre los componentes electrónicos. Se ha decido utilizar este programa debido a que es uno de los programas más utilizados en la industria electrónica por su amplía funcionalidad y comodidad, además, se ha utilizado en una de las asignaturas del Máster con lo que se conoce el funcionamiento del programa.

### 3.5.1. Realización de esquemáticos

Antes de comenzar con el diseño del circuito impreso es necesario definir los elementos del sistema y la relación que existen entre ellos. Esto se realiza mediante el desarrollo de esquemáticos. Generalmente, se agrupan los componentes del sistema en bloques por su funcionalidad y se realiza un esquemático global en el que se definen

36 3. Descripción del hardware del sistema

las relaciones que existen entre los bloques. Este tipo de esquemáticos se les conoce como diseño jerárquico. En este caso, esto los bloque en los que se divide el sistema son tres: sensores, actuadores y controlador.

Dado que este sistema es sencillo, la utilización de esquemáticos jerárquicos no es necesaria. Por ello, se ha decidido que se todo el sistema se incluya en un sólo esquemático, con el objetivo de que se pueda observar de forma más clara y sencilla la relación entre los distintos componentes. El esquemático obtenido se muestra en el Anexo A.

A continuación, se detallan las decisiones de diseño y los motivos por los que se han tomado:

- Tamaño de los componentes pasivos: se ha decidido que el tamaño de los componentes pasivos que se van a utilizar en esta tarjeta sea de tipo 0805, equivalente a 1.3 mm x 2.1 mm. Dado que el circuito impreso que se realizará dispone de un tamaño suficiente, no es necesario el uso de componente de tamaños más reducidos. Además, este encapsulado permite la soldadura de los componentes a mano.
- Bloque de control de la pantalla resistiva: para el diseño de este bloque se ha seguido el esquema que proporciona el fabricante[8]. Este diagrama presenta todos los elementos que son necesarios para el correcto funcionamiento del componente.
- Selección de la estructura: con el objetivo de realizar una tarjeta de expansión que sea capaz de funcionar tanto con el sistema formado por la cámara como por el que dispone de la pantalla resistiva, se ha decidido incluir un conector que permite seleccionar con que sensor trabajar en cada momento.
- Configuración del modo de comunicación: dado que el controlador de la pantalla resistiva permite la comunicación por dos protocolos, I2C y SPI, se ha decidido añadir pines de configuración que permiten seleccionar el tipo de comunicación empleado.
- Control de servo-motores: para el control de los actuadores es necesario añadir un componente adicional que además de reducir el consumo, aporta seguridad al sistema. Con el objetivo de poder desactivar los servo-motores cuando no sea necesaria su actuación, se han añadido dos buffers que interrumpen la señal de control de los servo-motores.

### 3.5.2. Posicionamiento de los componentes

Una vez se han realizado los esquemáticos, es momento de posicionar los componentes en la placa de circuito impreso (Printed Circuit Board, PCB). Para ello hay que tener en cuenta varias consideraciones:

3.5. Desarrollo de la tarjeta electrónica | 37
- Longitud de las pistas: con el objetivo de reducir la impedancia de las pistas, es necesario realizar un posicionamiento de tal forma que los componentes con gran relación entre sí presenten una distancia reducida.
- Conectores externos e interfaz de usuario: hay que tener en cuenta como se produce la conexión de los conectores al realizar el posicionamiento. En este caso, esta conexión se realiza con conectores verticales, es decir, la parte superior de estos debe encontrarse en todo momento libre. Además, hay que tener en cuenta que la tarjeta de expansión diseñada debe ser compatible con el uso de tarjetas adicionales. Por lo tanto, es necesario realizar un posicionamiento de los conectores de tal forma que permita su conexión cuando se encuentran múltiples tarjetas de expansión conectadas a la placa de desarrollo . De forma similar, todos los elementos que permitan la comunicación del usuario con nuestro sistema deberán estar en un lugar de la PCB accesible.
- Condensadores en la alimentación: la función de los condensadores en la alimentación de los integrados es la de eliminar el ruido de la fuente de alimentación y de proporcional alimentación cuando se requieren pequeños picos de corriente. Por estos motivos, es importante que los condensadores se encuentren los más cerca posible de la alimentación.
- Componentes digitales y analógicos: con el objetivo de reducir el ruido en las pistas analógicas, es recomendable separar los componentes que trabajen con señales analógicas de los digitales. En este caso, estas señales analógicas provienen únicamente de la pantalla resistiva, por lo que se debe posicionar los componentes de tal forma que las pistas digitales se encuentren lo más lejos posible de estas.

### 3.5.3. Rutado del circuito impreso

Una vez realizado el posicionamiento de los competentes siguiendo las consideraciones comentadas anteriormente, es momento de realizar el rutado de las pistas de la PCB. De forma similar al posicionamiento, en esta tarea también hay que tener en cuenta varias cosas:

- Planos de masa: el uso de planos de masa permite reducir el ruido electromagnético además de un camino continuo y de baja impedancia de retorno de la corriente.
- Distribución de las pistas de potencia y separación de pistas digitales y analógicas: por los motivos comentados anteriormente, es recomendable realizar una distribución de las pistas de potencia de forma que se realice una separación entre la etapa de potencia de competentes analógicos y digitales. De forma similar, es muy recomendables realizar una separación entre las pistas de señal analógica y digital.

38 3. Descripción del hardware del sistema

- Via stitching: consiste en realizar agujeros en toda la superficie de la placa manteniendo una cierta distancia constante entre ellos. Esta técnica permite reducir el efecto de señales de alta frecuencia en los circuitos, pero, además, crea puntos de interconexión entre los planos de masa, en el caso de que la PCB disponga de varios planos distribuidos.
- Señales digitales de alta frecuencia: este tipo de señales, por su gran frecuencia de conmutación, generan mucho ruido electromagnético. Para reducir este efecto, que puede ser muy perjudicial para algunos componentes, es recomendable reducir lo máximo posible la longitud de estas pistas. Además, si es posible, existe la posibilidad de aislar estas pistas entre un plano de masa.

Después de haber realizado el posicionamiento de los componentes en la PCB y el rutado de las pistas, es necesario comprobar que el diseño cumple con todos los requisitos para la fabricación. Las especificaciones de la PCB quedan definidas por las resoluciones y tolerancias de las que disponen las máquinas de los fabricantes. Estos requisitos generalmente se encontrar en la página web de los fabricantes, por ejemplo, las tolerancias que permite la empresa JLCPB se encuentran en la sección de Capacidades de su página web[9]. En el diseño realizado, dado que se trata de un sistema sencillo, estas restricciones no suponen un problema importante, pero, en cualquier caso, hay que realizar un diseño que las satisfaga, ya que si no se arriesga a que la PCB no se pueda fabricar. Por tanto, para el diseño de esta PCB se han seguido las especificaciones del fabricante JLCPCB mencionadas anteriormente.

Con todos estos comentarios, recomendaciones y restricciones, se ha realizado el diseño del circuito impreso. Se puede apreciar la PCB obtenida en el Anexo A.

# Capítulo 4

# Diseño e implementación del sistema

En este Capítulo se describirá el software que se ha empleado en el TFM junto con las alternativas y decisiones tomadas para la implementación del sistema.

## 4.1. Descripción del software empleado

### 4.1.1. Sistema operativo en tiempo real: FreeRTOS

Un sistema operativo es un programa que permite al usuario gestionar operaciones básicas de un ordenador, además de proporcionar servicios a otros programas o aplicaciones que se encuentren ejecutando en la máquina. Estos servicios permiten la codificación de aplicaciones de forma más rápida, simple y fácil de mantener.

La mayoría de sistemas operativos permite una ejecución simultánea de tareas, a esto se le denomina multi-tarea. En realidad, un procesador sólo permite la ejecución de un hilo, pero esta idea de paralelismo es proporcionada por el planificador, que es el encargado de decir que tarea es ejecutada en cada momento. El tipo de sistema operativo queda definido por la forma en la que tiene el planificador de dividir el tiempo del microprocesador entre las tareas.

Los sistemas operativos en tiempo real (RTOS, Real Time Operative System) son los que presentan una traza de ecuación predecible, esto es, en este tipo de sistemas se puede asegurar que el programa responderá a un determinado evento en un tiempo determinado. Este tipo de sistemas operativos son comunes en los sistemas embebidos, ya que permiten realizar tareas que presenten restricciones temporales, pudiendo asegurar con certeza que se cumplen estas.

Generalmente, en estos sistemas operativos se consigue esta predictibilidad debido

39

40 4. Diseño e implementación del sistema

a que el planificador permite que el programador asigne prioridades a las tareas, con lo que la ejecución se realizará en orden de mayor a menor prioridad.

Uno de los sistemas operativos en tiempo real más usado es FreeRTOS. Este sistema operativo está especialmente diseñado para ser ejecutado en cualquier tipo de microprocesador, ya que proporciona un código fuente muy ligero, pero a su vez cumple con los requisitos necesarios de los sistemas operativos en tiempo real más sofisticados.

Algunas de las características relevantes para la realización de este TFM son: disponer de un planificador en tiempo real, siguiendo el modelo de planificación Round-Robin con prioridades, necesario para realizar un análisis de planificabilidad del sistema; permitir la comunicación entre Tareas, esto resulta muy útil debido a que permite dividir en tareas cada una de las funciones del sistema.

Realizar la implementación sobre un sistema operativo, independientemente de que sea en tiempo real o no, permite abstraer el código realizado de la arquitectura empleada, además de facilitar la escalabilidad y la portabilidad.

### 4.1.2. Entorno de desarrollo: STM32CubeIDE

Para la realización del TFM se va a utilizar una tarjeta de desarrollo de la empresa STMicroelectronics que incorpora un procesador ARM Cortex M4. Este microcontrolador fue seleccionado por sus características de velocidad, periféricos y memoria de los existentes en el Laboratorio de Robótica y Control de la ETSIT. Este fabricante proporciona un entorno de desarrollo con el que facilita la labor de los programadores en la configuración inicial del hardware.

El entorno que proporciona STMicroelectronics en una herramienta de desarrollo que integra todos los productos de la compañía y que permite la implementación de diferentes sistemas operativos. Esta herramienta permite configurar los periféricos, generar y compilar el código, junto con el depurado. En este TFM, estas herramientas permiten desarrollar un código portable a toda la familia de procesadores STM32, además de realizar un depurado avanzado con el objetivo de obtener información relevante sobre el estado del sistema y los requisitos de memoria.

## 4.2. Modelado del sistema

Antes de comenzar con la implementación es necesario realizar un diseño del sistema electrónico. En este primer paso es necesario definir todos los requisitos que debe cumplir el sistema. Posteriormente se realizará el diseño teniendo en cuenta estos requisitos y, finalmente, se analizará la solución propuesta para observar si los resultados obtenidos cumplen los requisitos definidos.

4.2. Modelado del sistema | 41

### 4.2.1. Análisis de requisitos

Inicialmente, es necesario definir las características del sistema. En este caso, gran parte de los requisitos ya están definidos en los Capítulos 2 y 3, por lo que se ha realizado una recopilación de ellos y se exponen a continuación:

1. Control de la esfera sobre la plataforma
a) Obtención de la posición de la esfera
b) Cálculo de la acción de control necesaria
c) Comunicación de la acción de control al actuador
2. Comunicación del estado del sistema al exterior

Estos requisitos no son características técnicas si no que corresponden con la funcionalidad de debe tener el mismo. Es fundamental realizar este análisis previo sin especificar tecnologías o características técnicas.

### 4.2.2. Máquinas de estado finitas

Después de haber definido los requisitos del sistema, se realiza el diseño, sin tener en cuenta la arquitectura del mismo, el lenguaje de programación u otros aspectos relacionados con la implementación. Esta metodología de trabajo permite realizar un análisis previo del comportamiento del sistema con el objetivo de facilitar la corrección de los errores que puedan surgir más adelante.

Una forma de realizar este modelado es mediante la división de las maquinas de estados en diferentes tareas del sistema operativo. El modelo de maquinas de estados es una forma de modelar el comportamiento de un sistema de forma discreta y determinista, es decir, que un sistema sólo puede responder de una única forma ante cada combinación posible de entradas. De esta forma, se modela un sistema que es totalmente predecible. Por otro lado, este tipo de modelados permite realizar una implementación semi-automática, además de una verificación formal del sistema para poder asegurar con certeza que se cumplen las especificaciones definidas.

La descripción en este tipo de modelos se realiza mediante la definición de una lista de estados, y de las posibles transiciones que se producen entre ellos. Con el objetivo de facilitar la implementación, se va a realizar una implementación mediante máquinas de Mealy, es decir, las acciones que realiza la máquina de estados se producen en las transiciones entre estados. Además, estas máquinas pueden ser activadas por eventos, es decir, se evalúan las posibles transiciones cuando se produce una variación en algunas de las entradas del sistema, o bien, por tiempo, es decir, existe un reloj virtual que indica el instante en el que se evalúan las transiciones.

42 4. Diseño e implementación del sistema

Teniendo en cuenta las especificaciones que debe cumplir el sistema diseñado, reflejadas en la Sección 4.2.1, se ha decidido que será necesario el diseño de cuatro máquinas de estados: una para la toma de datos de los sensores, una para el cálculo de la acción de control y la actuación sobre los servo-motores y, adicionalmente, dos máquinas de estados para la comunicación con el exterior. Si se desea profundizar en el diseño de las máquinas de estados implementadas y las decisiones tomadas a la hora de realizarlo, se aconseja revisar el Anexo B en el que se trata en mayor profundidad.

## 4.3. Desarrollo del firmware

### 4.3.1. Implementación del firmware de la cámara

Como se ha comentado en el Capítulo 3, la programación del sistema de posicionamiento de la esfera se realiza mediante el lenguaje MicroPython. El fabricante de la cámara, OpenMV, proporciona un entorno de desarrollo sencillo, que es el que se ha empleado para el desarrollo del firmware.

En este caso, se ha decidido que la comunicación que se realice con el microcontrolador sea a través del protocolo de comunicación UART. Este protocolo serie y asíncrono permite la comunicación entre dos dispositivos de forma sencilla, sin necesidad de transmitir la señal del reloj. Por otro lado, dado que el sistema de medida sólo tiene una función, se ha creído oportuno que esta comunicación sean unidireccional, es decir, que el sistema de medida transmita la información al microcontrolador sin necesidad de que éste dé ninguna orden.

Este entorno de desarrollo, junto con las herramientas disponibles en MicroPython, ha facilitado la implementación de los algoritmos de detección de círculos y los protocolos de comunicación necesarios para transmitir la posición de la esfera al microcontrolador.

### 4.3.2. Implementación del firmware del microcontrolador

Como se ha comentado en las secciones anteriores, para la implementación de las máquinas de estados se ha hecho uso de las Task(Tarea) que permite implementar FreeRTOS. Estas tareas son ejecutadas de forma pseudo-simultánea en el microcontrolador. Es el planificador el encargado de gestionar el orden de ejecución de las mismas. Por otro lado, estás tareas trabajan de forma conjunta para conseguir un único objetivo, el control de la esfera sobre la plataforma, con lo que va a ser necesario el uso de recursos compartidos.

Cuando dos tareas intentan acceder a una variable que se encuentra en memoria se pueden producir lo que se conoce como condiciones de carrera, por ejemplo, cuando dos o más tareas acceden a un registro de memoria sin ningún control. A

4.3. Desarrollo del firmware | 43

las zonas de código en las que se dan condiciones de carrera se les conoce como secciones críticas. Como es lógico, la existencia de secciones criticas en el código puede dar lugar a problemas indeseados que pueden ocasionar el fallo del sistema. Para conseguir neutralizar este problema, FreeRTOS permite el uso de Colas(Queue) y mutex (Mutual Exclution). Las colas son espacios de memoria de tipo FIFO, First In, First Out, es decir, que los elementos que hayan entrado primero son los que primero salen. De esta forma, una tarea puede colocar en la cola mensajes, que son recibidos por otra tareas manteniendo el orden de entrada. Por otro lado, los mutex equivalen a poseer la llave que abre un determinado espacio de memoria, si un tarea solicita un mutex se le entrega la llave, si esta está libre, y, después de realizar todas las modificaciones sobre esa variable, la tarea libera el mutex, dejándolo disponible para las demás. Si una tarea solicita un mutex y este no se encuentra disponible, generalmente queda bloqueada hasta que lo obtiene. Se suelen usar colas cuando el tamaño de la variable es relativamente bajo y mutex cuando se quieren compartir recursos hardware o variables de tamaños elevados. Estos son los métodos que están disponibles en FreeRTOS para la implementación de una comunicación segura entre tareas.

### 4.3.2.1. Comunicación con los sensores

Para realizar la comunicación con los sensores se van a emplear dos protocolos de comunicación. Para la pantalla resistiva se va utilizar le protocolo I2C y para la comunicación con la cámara, UART. Como se ha visto en el Capitulo 3, el microcontrolador seleccionado dispone de periféricos encargados de gestionar esta comunicación. Por medio de la capa de abstracción hardware (HAL) que proporciona STMicroelectronics en los archivos stm32l4xx hal i2c.c y stm32l4xx hal uart.c se realiza la implementación de esta comunicación de forma sencilla.

Con el objetivo de reducir el tiempo que el microprocesador se encuentra ejecutando instrucciones, se va a intentar aprovechar al máximo los periféricos que dispone el microcontrolador. Especialmente cuando se realiza la comunicación, existen periféricos que permiten optimizar estos procesos. Son varias las formas de utilizar los periféricos de conectividad. En el método más sencillo, denominado polling, el microcontrolador da la instrucción al periférico y espera hasta que este la haya completado. Por otro lado, se puede realizar la misma función por medio de interrupciones o por acceso directo a memoria (DMA), esto es, se da la instrucción al periférico y el procesador continúa ejecutando sin esperar a que el periférico termine. En el caso de las interrupciones, el procesador no espera a que termine el periférico, pero interviene en la configuración de este. En el acceso directo a memoria, es el propio controlador DMA el que se encarga de configurar al periférico sin necesidad de intervención del microprocesador. Por este motivo, en la implementación de este sistema, siempre que sea posible se ha evitado el método de polling y se utilizará DMA.

Por último, es necesario comentar el protocolo de comunicación que se ha definido

44 4. Diseño e implementación del sistema

para distinguir si la esfera se encuentra en la plataforma o no. En el sistema formado por la cámara, si no se ha detectado una esfera en la imagen, los valores que se transmiten al microcontrolador superan los límites de la imagen. Esto indica al microcontrolador que no se ha detectado una esfera en la plataforma, por lo que no es necesario realizar un control sobre la estructura. Por otro lado, en el sistema de la pantalla resistiva, el controlador seleccionado presenta una función de Pen-Up and Pen-Down, esto es, puede identificar si hay un objeto tocando la pantalla o no. De esta forma, en la trama que es enviada se encuentra esta información, que es recogida por el microcontrolador para saber si hay o no esfera sobre la plataforma.

### 4.3.2.2. Comunicación con los servo-motores

En el Capítulo 3 se ha mencionado el método que se va a utilizar para trasmitir el ángulo objetivo a los servo-motores, esto es, mediante el uso de señales PWM. Este tipo de señal corresponde a una modulación de ancho de pulso, es decir, se modula el ancho del pulso de una señal cuadrada con el objetivo de modificar el ángulo del servo-motor.

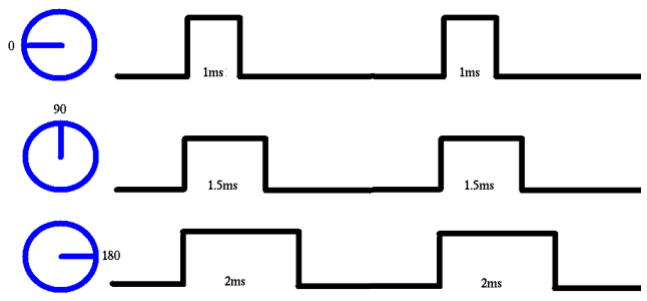
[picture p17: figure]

Figura 4.1: Diagrama de tiempos de la señal PWM para el control de los servo-motores. PanamaHitek.

Los servo-motores integran un controlador que permite un control preciso en posición. La comunicación del ángulo objetivo se consigue mediante la generación de una señal PWM con periodo de 20 milisegundos. Como se puede observar en la Figura 4.1, para que el servo se posicione en un ángulo de 0◦
se debe mantener la
señal a nivel alto durante 1 milisegundo y el resto del periodo a nivel bajo, lo que equivale a un 5 % del periodo a nivel alto. Por otro lado, para obtener un ángulo en el servo-motor de 180◦
, se debe mantener a nivel alto la señal durante 2 milisegundos, o lo que es lo mismo, un 10 % del periodo. Por lo tanto, el tiempo que se debe mantener

4.3. Desarrollo del firmware | 45

la señal a nivel alto para un determinado ángulo se muestra en la Ecuación 4.1.

talto(ms) = 1 + Angulo(

◦
)
180

= 1 +

Angulo(rad)
2π

(4.1)

Para la generación de esta señal el microcontrolador dispone de temporizadores, que pueden ser configurados en el modo Output Compare con un periodo de 20 milisegundos. En este modo, el contador del temporizador es comparado con un valor umbral y, si el contador es mayor que el umbral, la salida se encuentra a nivel alto, en cambio, si es inferior, la salida se encuentra a nivel bajo. Variando este umbral, se modifica el ancho del pulso y, por lo tanto, se puede modificar el ángulo objetivo del servo-motor.

### 4.3.2.3. Estructura del software del sistema

En el Figura 4.2 se muestra la estructura del código implementando en el microcontrolador. Se puede observar que el código de usuario, definido por el paquete Application, hace uso de las librerías HAL que proporciona el fabricante STMicroelectronics para el control de los periféricos del microprocesador, en este caso, estos son UART, I2C y temporizadores. También, este paquete utiliza la interfaz que proporciona FreeRTOS y que permite la gestión de las tareas y su comunicación. Además, dispone de las funciones encargadas de gestionar el controlador, PID o LQR, junto con el procesado de los datos de los sensores. Todas estas funciones se encuentran agrupadas en un mismo paquete denominado Drivers.

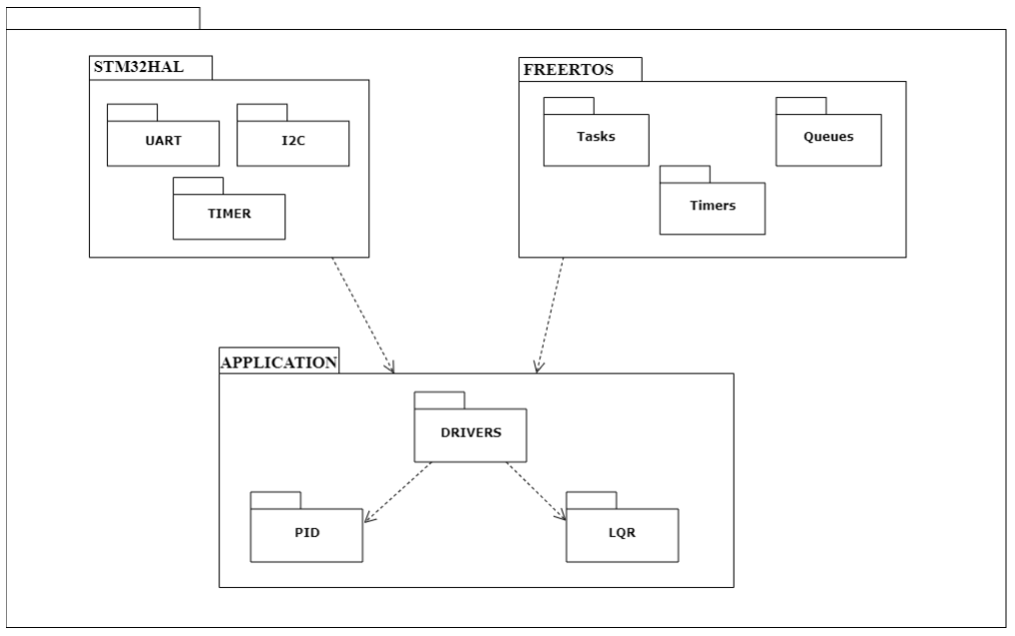
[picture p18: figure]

Figura 4.2: Estructura del código implementado.

46 4. Diseño e implementación del sistema

## 4.4. Desarrollo de controladores

Como se ha comentado en el Capítulo 2, en este TFM se va a realizar la implementación de dos tipos de controladores: PID y LQR. Al igual que en desarrollo del firmware, en este apartado también es necesario definir los requisitos de nuestro sistema. En este caso, se ha de definir la respuesta temporal que se desea obtener.

En capítulos anteriores se ha visto que la respuesta temporal de un sistema viene definida por varios parámetros. Entre todos ellos, los que son comúnmente usados son el tiempo de establecimiento y la sobreoscilación. Dado que en este caso estas restricciones no quedan definidas de antemano, queda a cargo del usuario definir estos dos parámetros.

Se ha decidido que el tiempo de establecimiento deberá ser aproximadamente unos 3 segundos, con una sobreoscilación de menos de un 20 %. Se han escogido estos valores, debido a qué se considera que tiempos de establecimiento menores requieren un control más agresivo y preciso del ángulo de inclinación de la plataforma del que se dispone. Por otro lado, una sobreoscilación del 20 % es un valor comúnmente utilizado para sistemas en los que este efecto no suponga un gran problema. Valores inferiores requerirían acciones de control más agresivas, o lo que es lo mismo, actuadores más potentes y valores superiores pueden causar efectos indeseados en el sistema.

Cuando se realiza la implementación de estos controladores en un dispositivos digital se produce una discretización. Esto se debe a que las señales de un microcontrolador no son continuas, por lo que el desarrollo teórico que se ha realizado con anterioridad no es completamente correcto. Dependiendo del periodo de muestreo de las señales, este efecto de descretización puede afectar significativamente la respuesta del sistema.

En la Figura 4.3 se observa el efecto de modificar el periodo de muestro de la señal en un sistema con un tiempo de establecimiento de 4 segundos y una sobreoscilación de 20 %. Se puede observar que si el sistema presenta un tiempo de muestreo suficientemente bajo comparado con el tiempo de establecimiento, la respuesta no se ve afectada por la discretización. Por otro lado, un periodo de muestro del mismo orden al tiempo de establecimiento puede causar inestabilidad en el sistema. Comparando las respuestas ante diferentes periodos de muestro, se observa que con un periodo de muestro dos ordenes de magnitud inferior al tiempo de establecimiento la respuesta que se obtiene no difiere significativamente del sistema continuo, por lo que siempre que se pueda se utilizará un tiempo de muestro de estas magnitudes.

### 4.4.1. Controlador PID

Una vez definidos los requisitos temporales de la respuesta del sistema, es momento de realizar el diseño de los controladores acorde a estos. En el Capítulo 2 se ha visto

4.4. Desarrollo de controladores | 47

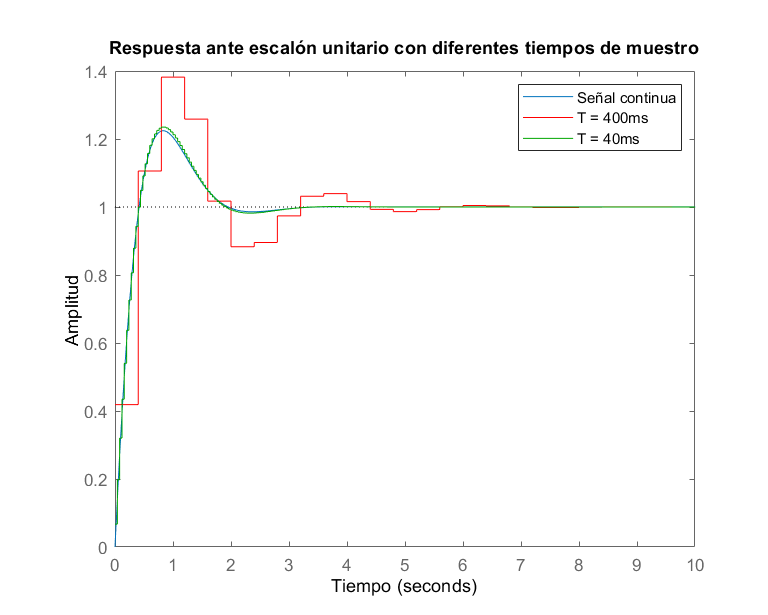
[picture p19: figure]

Figura 4.3: Respuesta del sistema ante distintos periodos de muestro.

que el sistema mecánico no requiere un controlador PID completo. Por este motivo, para realizar este control se implementará un controlador PD, es decir, formado por una parte proporcional y derivativa. A partir de las Ecuaciones 2.63 y 2.64 se obtiene la ganancia y la posición del cero que debe ser añadidos al sistema en lazo abierto. A partir de estos valores, con las Ecuaciones 2.65 y 2.66, se obtienen las ganancias necesarias para implementar el controlador PD.

A partir de los requisitos planteados y de las Ecuaciones 2.60 y 2.61 se obtiene la posición en la que se debe colocar el polo:

σ =

π
ts

=

π
3
= 1,0472 | (4.2)

ωd =

π

2

ln(

1
M p ) · ts
= 2,0441 | (4.3)

Con esto valores, aplicando la Ecuación 2.63, se obtiene la posición del cero que debe ser introducido en lazo abierto para que el polo se encuentre en el LDR:

a = tan(π + 2 · (tan⁻¹
(

ωd
σ
))) · ωd + σ = −1,7925 | (4.4)

Por otro lado, aplicando la Ecuación 2.64, se obtiene la ganancia del sistema en

48 4. Diseño e implementación del sistema

lazo abierto:

K =

q
ω

2
d + σ

2 ·

q
ω

2
d + σ

2
q
ω

2
d + (σ − a)

2

= 1,5076 | (4.5)

Por lo tanto, aplicando las Ecuaciones 2.65 y 2.66, se obtienen las ganancias de las componentes proporcional y derivativa del controlador:

KD =

K
7
= 0,2154 | (4.6)

KP = −KD · a = −

K
7
- a = 0,3860 | (4.7)

Una vez diseñado el controlador, es necesario realizar una simulación en MATLAB para observar si la respuesta del sistema cumple los requisitos propuestos.

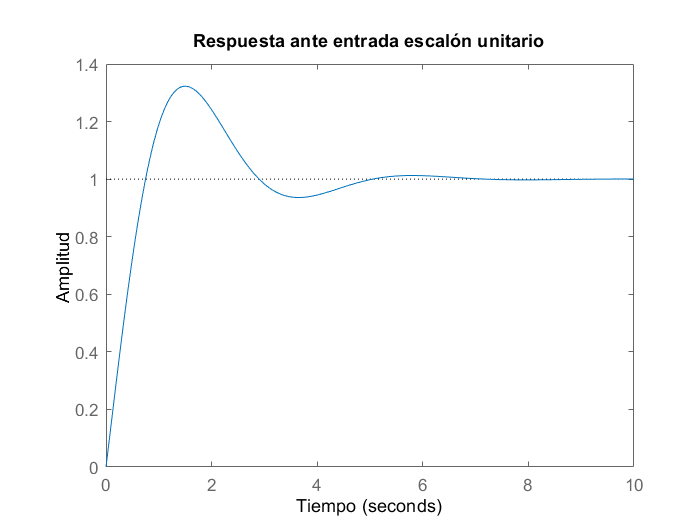
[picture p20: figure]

Figura 4.4: Respuesta del sistema aplicando el controlador PD diseñado.

Además, se puede observar la posición del polo y el LDR en la Figura 4.5.

Se observa claramente en la Figura 4.4 que la respuesta del sistema no satisface los requisitos que se han propuesto. Esto se debe a que las suposiciones que se han realizado para el cálculo de la posición del polo dominante no son correctas en este caso. Dado que en este sistema el factor de amortiguamiento es comparable a 1, la Ecuación 2.60 no es del todo correcta, lo que provoca que el comportamiento

4.4. Desarrollo de controladores | 49

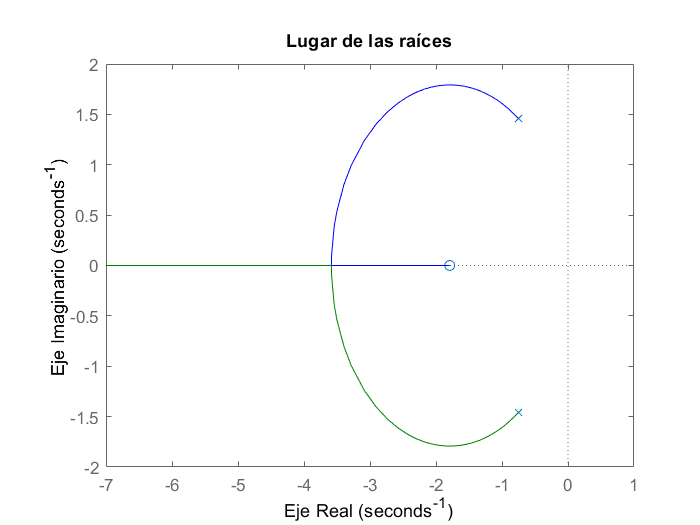
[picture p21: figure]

Figura 4.5: Lugar de las raíces del sistema aplicando el controlador PD diseñado.

del sistema no sea el deseado. Aunque este diseño no satisfaga los requisitos, esto no significa que sea inútil. Es un punto de partida a la hora de realizar el ajuste experimental del controlador, ya que proporciona una respuesta similar a la que se desea obtener.

Finalmente, para la implementación de este controlador es necesario calcular el error, y su derivada, de la posición de la esfera respecto de una determinada referencia y multiplicar estos valores por las ganancias obtenidas anteriormente.
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

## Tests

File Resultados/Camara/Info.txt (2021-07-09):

Tiempo de muestreo: 5 ms
PID derivativo: 8
LQR derivativo: 10

PID_1: P=0.4, D=0.2;
PID_2: P=0.8, D=0.4;
PID_3: P=1.6, D=0.6;
PID_4: P=2.6, D=0.4;

LQR_1: K = 1.0000    0.5345;
LQR_2: K = 1.0000    0.5345;
LQR_3: K = 1.0000    0.5345;
LQR_4: K = 1.0000    0.5345;

Finalmente, se ha dejado el PID con P=1.6 y D=0.6

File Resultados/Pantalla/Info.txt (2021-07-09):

Tiempo de muestreo: 5 ms
PID derivativo: 8
LQR derivativo: 10

PID_1: P=0.4, D=0.2;
PID_2: P=0.8, D=0.2;
PID_3: P=0.8, D=0.4;
PID_4: P=1.6, D=0.6;
PID_5: P=1.5, D=0.5;
PID_6: P=2.6, D=0.8;
PID_7: P=2.6, D=0.4;
PID_8: P=2.6, D=0.6;

LQR_1: K = 1.0000    0.5345;
LQR_2: K = 1.0000    0.5345;
LQR_3: K = 1.0000    0.5345;

PID_prueba: PID:2.0,0.6; TD=9; Cuadrado. Eje Y
PID_prueba2: PID:2.0,0.6; TD=9; Pseudo-Círculo. Eje Y
PID_prueba3: PID:2.0,0.6; TD=9; Pseudo-Círculo. Ejes XY

Finalmete el controlador que se ha dejado es PID con P=2.2 y D=0.6

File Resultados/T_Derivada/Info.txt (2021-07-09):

PID: P=2.6, D=0.8

TD_1: TD = 15;
TD_2: TD = 1;
TD_3: TD = 5;
TD_4: TD = 10;
TD_5: TD = 8;
TD_6: TD = 12;
TD_7: TD = 15;

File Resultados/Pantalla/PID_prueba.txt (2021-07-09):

E25A040BF05A010BF05A010BFD5AFF0AFD5AFF0AB35A0C0B985A110BCF5C110BAA5C170BAA5C170B8A5C1D0B8A5C1D0B925C1B0B825C1E0B825C1E0BA25C180B535D180B485D1A0B485D1A0B3E5D1C0B385D1D0B385D1D0B035D260B035D260BFB5C280BE05B280BDD5B280BDD5B280BDD5B280BDD5B280BED5B250BED5B250BED5B250BE85B260B665E260B605E270B605E270B605E270B385E2E0B385E2E0B605E270B605E270B7B5E230BD45E230BD45E230BFB5E1C0BCC5E240BCC5E240BB65E280BB65E280BB65E280BC15E260BB75D260BC75D230BCA5D230BCA5D230BDF5D1F0BE45D1E0BE45D1E0BF25D1C0BFF5D190B5960190B54601A0B5960190B5960190B6460170B7F60130B7F60130B5F60180B7C60130B845F130B7E5F140B6F5F170B6F5F170B995F100BA15F0E0BA15F0E0BA65F0D0BB45F0B0B0C600B0B1F60080B0C600B0B0C600B0B1760090B1760090B1760090B1760090B12600A0BF65E0A0BDB5E0F0B015F080B015F080B1E5F030B2E5F000B2E5F000B5B5FF80A1E5F030B0460030B0460030B1A60FF0A2260FE0A2260FE0A2260FE0A2260FE0A2260FE0A2260FE0A1860FD0A1860FD0AB05F0F0BB05F0F0BDD5F070BF35F030BF35F030B0A60FF0A2560FA0A865FFA0A935FF80A935FF80AA35FF50AA35FF50A705FFE0A985FF70A985FF70AED5FE80AE261EA0AE261EA0A1C62E00AD461ED0AD461ED0A9761F70AB261F30AB261F30AAF61F30A1660E70A1660E70A1660E70A1660E70A1660E70A1660E70A1660E70A3660E20A3660E20AAE5FE70AAE5FE70A315FFD0A315FFD0A315FFD0A315FFD0AAC5FE70AAC5FE70AAC5FE70ABC5EEC0AB55EED0AB55EED0AB55EED0AB55EED0AB55EED0AD25EE80AD25EE80A9A5EF20A9F5EF10A9F5EF10AB25EEE0AB25EEE0ACC5EE90ACC5EE90A495FD30A495FD30A495FD30A7A64D30A0D64E60A5264DA0A5264DA0A6264D70A8D64D00A8D64D00AE264C10AF464BE0AB663BE0AB663BE0AB663BE0AB663BE0AB663BE0AB663BE0AA663C10A8063C70A8063C70A035FC70A235FC10A235FC10A3E5FBD0A405FBC0A405FBC0A3E5FBD0A3E5FBD0A3E5FBD0A1462BD0A21638E0A5462B10A5462B10A4162B50A2A62B90A2A62B90AB261CE0AB261CE0ADA5DCC0ADA5DCC0ADA5DCC0ADA5DCC0AEC5DC90AEC5DC90AC75DD00AA25DD60AA25DD60A7D5FD00A875FCF0A875FCF0A875FCF0A875FCF0A875FCF0A875FCF0A975FCC0AF45FBC0AB163BC0AA163BE0A8C63C20A8C63C20A8C63C20A8163C40A8163C40A7963C50A7963C50AE85EC50AE85EC50AE85EC50AE05EC70ADB5EC80ADB5EC80ADB5EC80ADB5EC80ADB5EC80AF65FC80ABC5FD20AAE5FD40AAE5FD40AC15FD10AE65FCA0AE65FCA0AF35FC80AF35FC80AB560C50AB760C50AB760C50AA260C90A0461B70A0461B70A0C61B60A0C61B60A2C61B00AB463B20AB463B20AB463B20AB463B20AB463B20A9163B80A9163B80A3763C80A4463C50A745DC50A745DC50A285CFF0AAA5CE90AAA5CE90ADC5CE00ADC5CE00A5F5DC90A5F5DC90AB95FC90AB45FCA0AB45FCA0AC65FC70AB65FCA0AB65FCA0AA45FCD0A615FD80A615FD80AFA5BE20AC55BEB0AC55BEB0AA55BF10AA55BF10AA55BF10A555CD20A575CD20A575CD20A8062D20A2662E20A2662E20A2B62E10A2B62E10A2B62E10A2B62E10A2B62E10A2B62E10ADC5BEA0A8A5BF90A8A5BF90A8F5BF80A8F5BF80A8F5BF80A8F5BF80A8F5BF80A8F5BF80A3766C40AE765D10AE765D10AC765D70AC765D70AB265DB0A8D65E10A8D65E10A8565E30A115BE30A115BE30A115BE30A115BE30A115BE30A215BE00A215BE00AA25AF60AA25AF60AD45EE80ADC5EE60ADC5EE60AE45EE50AEF5EE30AEF5EE30AEA5EE40AFF5EE00AFF5EE00A8061DD0AAB61D50AAB61D50ABB61D20AC361D10AC361D10AD861CD0AD861CD0A9E61D70A715FDF0A715FDF0A4C5FE50A145FEF0A145FEF0A0F5FF00A075FF10A075FF10A075FF10A9B5CF10A9B5CF10A955CF20A955CF20A6E5CF90A535CFE0A535CFE0A285C050B0B5C0A0B135B0A0B015B0E0BF65A100BF65A100BEE5A110BD65A150BD65A150BCB5A170BC65A180B815C180B745C1A0B5F5C1E0B5F5C1E0B3F5C240B2F5C260B2F5C260B2F5C260B195C2A0B685B2A0B505B2E0B405B310B405B310B235B360B265B360B265B360B265B360B265B360B1E5C360B115C380B115C380BFE5B3B0BF35B3D0BD35B430BD35B430BE65B3F0BE65B3F0BF05B410BF05B410BF05B410BF05B410BEA5B420BEA5B420B005C3E0BD35B460BD35B460B875B4D0B925B4B0B925B4B0B7F5B4E0B975B4A0B975B4A0BBC5B440BBC5B440BE75B3C0B5A603B0B5A603B0B5A603B0B5A603B0B5A603B0B5A603B0B5A603B0B6560390B6560390B0A5E390B185E370B185E370B1D5E360B1D5E360B8B6B360B8B6B360B8B6B360B8B6B360BB46C310B8F6C370B8F6C370B956C360B9D6C350B9D6C350BAA6C320BAA6C320BAA6C320B9B68410B9D68400B9D68400BC868390B00692F0B00692F0B3F69240B8F69160B8F69160B5972160B5972160B5972160B5972160B5972160B5472170B5772170B5772170B2C721E0B076B1C0B076B1C0B216B170B216B170B2C6B150B2C6B150B2C6B150B566B0E0B246B170BBC6C170BB16C180BAC6C190BAC6C190BAC6C190BAC6C190BAC6C190BAC6C190B946C1D0BBE69240BBE69240B8E692C0B5969350B5969350B39693B0BE4684A0BE4684A0BDF684A0BFF644A0BFF644A0BFF644A0BFF644A0BDF64500B6A64640B6A64640B9C645C0B6264660B1D66660BCD65740BB265780BB265780B3B658D0B3B658D0B3B658D0B3B658D0B2164BE0BFE5ABE0BBC5ACA0B9F5ACF0B9F5ACF0B7C5AD50B3C5AE00B3C5AE00B025AEB0BC259F60BBE5EF60B835E000C835E000C245E110CD45D1E0CD45D1E0C875D2C0C875D2C0C875D2C0C5D526E0C8A52660C8A52660C8A52660C8A52660C6F526B0C5052700C5052700C08527D0CBE617D0C7B61880C2661970C2661970CAF60AC0C4F60BD0C4F60BD0CDA5FD10C7A5FE20C9B52E20C5652EE0C5652EE0CF351FF0CF351FF0C96510F0D39511F0D39511F0D39511F0D1B571F0D10557B0D10557B0D2D55760D2D55760D2255780D2255780D10557B0DCB54870D904E870D404E950DEE4DA30DEE4DA30D9E4DB10D864DB50D864DB50D414DC10D414DC10D9D52C90D6052D40D6052D40D1B52E00DE951E90DE951E90DA151F50DA151F50DA151F50DF354F50DF354F50D4F54120E4F54120E4954130E3954160E3954160E2C54180E07541F0E71541F0E4154270E4154270E17542E0EE453370EE453370EC7533C0EC7533C0EA753420E2854440E2854440E1A54460E0A54490E0A54490EFB534C0EDB53520EDB53520EB853580E25555F0E1255620E1255620E1255620E1255620E1255620E0555650EFB54660EFB54660E2B576B0E2B576B0E21576D0E21576D0E21576D0E21576D0E21576D0E21576D0E26576C0EE6586B0EE6586B0EF958670EFE58660EFE58660E0459660E0459660E0E59640E0E59640EA75A600EA75A600EF15A530EF15A530EEE5A540EF95A520EF95A520E015B510E015B510ED65B510ED65B510ED65B510EE65B4E0EE65B4E0E185C450E435C3E0E435C3E0E435C3E0E225F300E225F300E375F2C0E3F5F2B0E3F5F2B0E4C5F280E5C5F260E5C5F260E6F5F220EA45D1C0EA45D1C0EC95D150EC95D150EE95D100E145E080E145E080E2E5E040E435E000E715F000E915FFA0D915FFA0DA65FF70DC05FF20DC05FF20DC05FF20D0E60E50D0E60E50D6260E20D5F60E30D6460E20D6460E20D6F60E00D6F60E00D6F60E00D6F60E00D6F60E00D5A5CE00D5A5CE00D045DC20D045DC20D045DC20D095DC10D095DC10D095DC10D095DC10D4261C10D4461C10D4461C10D5F61BC0D5F61BC0D6F61B90D8A61B50D8A61B50D8A61B50DD75EB50DD75EB50D535F9F0D535F9F0D5B5F9E0D5B5F9E0D5B5F9E0D5B5F9E0D5B5F9E0DCA609F0DCA609F0DDA609C0DDA609C0DE5609A0DE5609A0DE5609A0D1561920D27618E0D41608E0D41608E0D5B608A0D6360880D6360880D7660850D9E607E0D9E607E0D9B607F0D8A607F0D8A607F0D8A607F0D8A607F0D8A607F0D8C607E0DA1607A0DA1607A0D8F607E0D585E7E0D855E760D9A5E720D9A5E720DA25E710DA25E710DA25E710DA25E710DA25E710D7A5F760D7A5F760D7A5F760D925F720D925F720D985F710DA05F700DA05F700DB25F6C0D0B606C0D00606E0D00606E0D00606E0D00606E0D00606E0D00606E0D00606E0DF05F710DCB5D710DDE5D6E0DD65D6F0DD65D6F0DD85D6F0DD85D6F0DD35D700DD35D700DF05D6B0D995F6B0DA15F690DA45F690DA45F690DA45F690DA45F690DA45F690D915F6C0D915F6C0DDF5E690DD45E6B0DD45E6B0DC95E6D0DC95E6D0DC95E6D0DC95E6D0DC95E6D0DC95E6D0D065E6D0D065E6D0D3E5E630D295E670D295E670D245E680D245E680D245E680D245E680D745F680D745F680D7A5F670D6C5F690D6C5F690D675F6A0D675F6A0D625F6B0D625F6B0DD15D6D0DCC5D6E0DCC5D6E0DCC5D6E0DCC5D6E0DCC5D6E0DCC5D6E0DD15D6D0DD15D6D0D945E6D0D945E6D0D945E6D0D945E6D0D945E6D0D8C5E6E0D7F5E710D7F5E710D775E720DB45D720DBF5D700DC15D700DC15D700DC45D6F0DB75D720DB75D720DB75D720D915D780D6E5D780D695D790D695D790D635D7A0D635D7A0D635D7A0D635D7A0D635D7A0D595D7C0D4B5D7E0D4B5D7E0D3E5D800D3E5D800D3B5D810D3E5D800D3E5D800D535D7D0D535D7D0D6F5E7D0D6F5E7D0D6F5E7D0D6F5E7D0D6F5E7D0D675E7E0D575E810D575E810D3A5E860DA25C860D985C880D885C8B0D885C8B0D805C8C0D805C8C0D805C8C0D805C8C0D805C8C0DFC5C8C0DE95C8F0DE95C8F0DE95C8F0DE95C8F0DEC5C8F0DEC5C8F0DEC5C8F0DEC5C8F0D685D8F0D685D8F0D3B5D970D405D960D405D960D3B5D970D3B5D970D3B5D970D3B5D970D785C970D755C970D755C970D755C970D755C970D755C970D725C980D725C980D725C980D7C5D980D7C5D980D7C5D980D7C5D980D7C5D980D7C5D980D7C5D980D795D980D795D980D8B5D980D8B5D980D8B5D980D895D990D895D990D895D990D895D990D865D990D865D990D235D9B0D235D9B0D235D9B0D205D9B0D255D9A0D255D9A0D235D9B0D235D9B0D235D9B0D8D5D9B0D8D5D9B0D8D5D9B0D8D5D9B0D8D5D9B0D8D5D9B0D8D5D9B0D8D5D9B0D8D5D9B0D8D5D9B0D8D5D9B0D8D5D9B0D8D5D9B0D8D5D9B0D8D5D9B0D8D5D9B0D8D5D9B0D8D5D9B0DA15D9A0DA15D9A0DA75D990DA95D990DA95D990DAF5D980DAF5D980DAF5D980DB45D970D1E5E970D215E970D245E960D245E960D2C5E950D2C5E950D295E950D295E950D295E950DF45D950DF45D950DF95D940DF95D940D015E930D065E920D065E920D045E920D045E920D275E920D2A5E920D2A5E920D2C5E920D375E900D375E900D225E930D225E930D225E930D945D930DEE5D840DDE5D860DDE5D860DDC5D870DCC5D8A0DCC5D8A0DC75D8B0DC95D8A0D4F5F8A0D4F5F8A0D4F5F8A0D5F5F870D5F5F870D5F5F870D5F5F870D5F5F870D5F5F870D7B5E870D7B5E870D835E860D865E850D865E850D995E820D995E820D9E5E810DA65E7F0D455F7F0D4D5F7E0D4D5F7E0D505F7E0D505F7E0D6A5F790D705F780D705F780D755F770D995F770D9E5F760D9E5F760D8E5F790D8E5F790D965F780D9E5F760D9E5F760DA15F760D975E760D9F5E740D9F5E740D9F5E740D9F5E740D945E760D895E780D895E780D8C5E780D105E780D1B5E760D1B5E760D2B5E730D2B5E730D455E6E0D455E6E0D455E6E0D455E6E0DDA5F6F0DDD5F6E0DDD5F6E0DCF5F710DCF5F710DDA5F6F0DDA5F6F0DE25F6D0DE25F6D0DEF5E6C0DEF5E6C0D025F690D025F690DFF5E6A0DFF5E6A0DE75E6E0DE75E6E0DF25E6C0DAB5E6C0DA85E6C0DA85E6C0DAE5E6C0DAE5E6C0DB85E6A0DB85E6A0DB05E6B0DB05E6B0DAE5E6C0DAE5E6C0DB05E6B0DB05E6B0DB85E6A0DB85E6A0DB65E6A0DB65E6A0DB85E6A0DEE5E6A0DEB5E6A0DEB5E6A0DEB5E6A0DEB5E6A0DF05E690DF05E690DE65E6B0DE65E6B0D7E5E6B0D7E5E6B0D7E5E6B0D715E6D0D715E6D0D735E6C0D735E6C0D735E6C0D735E6C0D505E6C0D505E6C0D505E6C0D4D5E6D0D4D5E6D0D4D5E6D0D4D5E6D0D4D5E6D0D4D5E6D0D825E6D0D825E6D0D655E720D655E720D5B5E740D5B5E740D5B5E740D4D5E760D4D5E760DD45C770DD45C770DD45C770DD45C770DD45C770DD45C770DC45C7A0DC45C7A0DBF5C7B0DB75D7B0DA15D7F0DA15D7F0D995D800D995D800D8C5D820D8C5D820D745D860D745D860D0A5C880D0A5C880DF25B8C0DF25B8C0DEF5B8C0DEF5B8C0DF55B8C0DF55B8C0DE75B8E0DF15C8E0DE65C900DE65C900DD15C930DD15C930DB95C980DB95C980DA95C9A0DA95C9A0D375B9D0D375B9D0D2F5B9F0D2F5B9F0D2A5B9F0D2A5B9F0D2F5B9F0D2F5B9F0D225BA10DDD5CA10DDA5CA10DDA5CA10DD25CA30DD25CA30DC25CA60DC25CA60DBF5CA60DBF5CA60D105CA90D105CA90D055CAB0D055CAB0DFD5BAC0DFD5BAC0DF85BAD0DF85BAD0DF55BAD0D715CAD0D6F5CAE0D6F5CAE0D675CAF0D675CAF0D625CB00D625CB00D645CB00D645CB00DBD5CB00DBD5CB00DBF5CAF0DBF5CAF0DBF5CAF0DBF5CAF0DBA5CB00DBA5CB00DB55CB10DD85CB10DD85CB10DD85CB10DDB5CB10DDB5CB10DDE5CB00DDE5CB00DE05CB00DE05CB00D4B5DB00D485DB00D485DB00D485DB00D485DB00D485DB00D485DB00D485DB00D485DB00D015DB00D015DB00D045DB00D045DB00D0C5DAE0D0C5DAE0D145DAD0D145DAD0D195DAC0DCA5DAC0DD75DAA0DD75DAA0DDF5DA80DDF5DA80DDD5DA90DDD5DA90DDD5DA90DDD5DA90DB95DA90DB95DA90DBC5DA80DBC5DA80DBC5DA80DBC5DA80DBC5DA80DBC5DA80DC45DA70D8F5DA70D8F5DA70D8F5DA70D8F5DA70D8F5DA70D975DA60D975DA60D975DA60D975DA60D855DA60D855DA60D925DA30D925DA30DCF5D990DCF5D990DE55D950DE55D950DF55D920DA860920DB060910DB060910DB060910DB060910DB060910DB060910DB260900DB260900D115E900D115E900D115E900D115E900D115E900D1E5E8E0D1E5E8E0D265E8C0D265E8C0D6D5E8C0D6D5E8C0D6D5E8C0D6D5E8C0D785E8B0D785E8B0D785E8B0D985E850D985E850D635F840D635F840D635F840D635F840D635F840D635F840D6D5F820D6D5F820D6D5F820D635E820D635E820D635E820D635E820D6B5E800D6B5E800D6B5E800D6B5E800D6B5E800D5A5E800D5F5E7F0D5F5E7F0D5F5E7F0D5F5E7F0D5F5E7F0D5F5E7F0D5F5E7F0D645E7F0D765E7F0D765E7F0D765E7F0D765E7F0D765E7F0D8B5E7B0D8B5E7B0DA35E770DA35E770D245F790D245F790D215F790D215F790D345F760D345F760D215F790D215F790D045F7F0D5A5D7F0D7A5D790D7A5D790D685D7C0D685D7C0D685D7C0D685D7C0D725D7A0D725D7A0DE65E7A0DE65E7A0DE65E7A0DE65E7A0DE65E7A0DE65E7A0DE65E7A0DE65E7A0DE65E7A0D475E7A0D3F5E7C0D3F5E7C0D245E800D245E800D1F5E810D1F5E810D0F5E840D0F5E840D5E5C860D5E5C860D595C860D595C860D595C860D595C860D595C860D595C860D595C860DDE5D860DB15D8E0DB15D8E0DA15D910DA15D910DA15D910DA15D910DA95D900DA95D900D6A5C900D6A5C900D6A5C900D6A5C900D685C900D685C900D685C900D685C900D685C900DB85D900DB35D910DB35D910DB35D910DB35D910DB35D910DB35D910DAB5D920DAB5D920D645D920D645D920D645D920D645D920D5F5D930D5F5D930D5F5D930D5F5D930D5F5D930D945D930D945D930D8C5D950D6C5D9A0D6C5D9A0D6C5D9A0D6C5D9A0D6C5D9A0D6C5D9A0D865C9A0D865C9A0D865C9A0D865C9A0D865C9A0D865C9A0D865C9A0D865C9A0D835C9B0D7B5D9B0D0E509B0D0E509B0D0E509B0D0E509B0D0E509B0D0B509B0D0B509B0D0B509B0D0B509B0D0B509B0D0B509B0D08509C0D08509C0D08509C0D08509C0D08509C0D08509C0DA24F9E0DA24F9E0D6D4FA70D6D4FA70D434FAF0D434FAF0D204FB50D204FB50D0B4FB90D834BB90D764BBB0D764BBB0D714BBC0D714BBC0D714BBC0D714BBC0D714BBC0D714BBC0DE74EBC0DE74EBC0DE94EBB0DE94EBB0DE94EBB0DE94EBB0DE94EBB0DE94EBB0DE94EBB0DF14FB90DF14FB90D2650AF0D6950A40D6950A40DB350970DB350970DF0508C0DF0508C0D7458840D7458840D9E587D0D9E587D0DCB58750DCB58750D08596A0D08596A0D60595B0DB7575B0D01584E0D01584E0D69583C0D69583C0DD358290DD358290D3B59170D3B59170D9960030D9960030D0361F10C0361F10C5661E20C5661E20CB061D20CB061D20C0D62C20CC461B00CC461B00C39629C0C39629C0CA662890CA662890C1863750C1863750C8063630CAB62630C1563500C1563500C7A633E0CE2632C0CE2632C0C4C641A0C4C641A0CC164050C1C67050C8867F20B8867F20BDE67E40BDE67E40B4368D20B4368D20BA068C20BF768B20B7167B20BD667A10BD667A10B2668930B2668930B7168860B7168860BCE68760BCE68760B4468650B4468650B9C68560B9C68560BE968490B3B693A0B3B693A0B8B692C0B8B692C0BB768200BB768200B0269130B0269130B4769070B8769FC0A8769FC0AC169F10AC169F10AF767E80AF767E80A1F68E10A1F68E10A4C68D90A4C68D90A7C68D00AB968C60AB968C60AFE66BD0AFE66BD0A3167B40A3167B40A6967AA0A6967AA0A8867A40A8867A40ABB679C0A3E67960A3E67960A5967910A5967910A81678A0A81678A0A9867860AB067820AB067820A91657D0A91657D0AA1657B0AA1657B0AAC65790AAC65790ACC65730AE4656F0AE4656F0A50656A0A50656A0A6865660A6865660A7265640A7265640A7265640A7265640A7265640A7063640A7063640A7063640A7063640A7063640A7063640A7063640A7063640A7063640A8A62640A8A62640A8A62640A8A62640A8762640A8762640A8762640A8762640A8762640A7662640A7662640A7662640A7662640A7662640A7662640A7662640A7062650A7062650A56616B0A3E61700A3E61700A1661770A1661770A0B61780A0B61780AEE607D0AEE607D0A8E5E820A885E830A885E830A885E830A885E830A885E830A885E830A865E830A865E830AA361830AA361830AA361830AA361830A9361860A9361860A60618F0A60618F0A5661900A895F900A395F9E0A395F9E0A1F5FA30A0A5FA70A0A5FA70ADC5EAF0ADC5EAF0A1A5FA40A335EA40A2B5EA50A2B5EA50A2E5EA50A2E5EA50A2E5EA50A2E5EA50A2E5EA50A2E5EA50A7860A80A7860A80A3660B30A2360B70A2360B70A1960B80A1960B80A1960B80A1960B80A295EB80A295EB80A165EBC0AF35DC20AF35DC20ACE5DC80ACE5DC80A9E5DD00A9E5DD00AF45BD40AF45BD40AE45BD70AE45BD70ADC5BD80ADC5BD80ADC5BD80ADC5BD80ADC5BD80A295FD90A295FD90A295FD90A295FD90A295FD90A295FD90A295FD90A175FDC0AD45EE80A605DE80A2E5DF10A2E5DF10A0B5DF70A0B5DF70AFB5CF90AFB5CF90A015DF80A015DF80A915CF90A915CF90A915CF90A915CF90A915CF90A895CFB0A895CFB0A895CFB0A895CFB0AF55EFB0AF55EFB0AED5EFC0AED5EFC0AED5EFC0AED5EFC0AED5EFC0AED5EFC0AE35EFE0A9C5EFE0A9C5EFE0A9C5EFE0A9C5EFE0A9C5EFE0A915E000B915E000B915E000B915E000BC65E000BC65E000BB45E030BB45E030B715E0F0B715E0F0B5F5E120B5F5E120B575E130BB55B130BB55B130BB55B130BB55B130BB35B140BB35B140BB35B140BB35B140BB35B140B895E140B945E120B945E120B945E120B945E120B945E120B945E120B995E110B995E110BB85F0D0BB85F0D0BB35F0E0BB35F0E0BA05F110BA05F110B8B5F150B835F170B835F170B295D170B295D170B295D170B295D170B2E5D160B2E5D160B2E5D160B2E5D160B2E5D160BB45E160BB95E150BB95E150BB95E150BB95E150BB95E150BB95E150BB95E150BBE5E140B855F100B855F100B8D5F0F0B8D5F0F0B9D5F0C0B9D5F0C0BAA5F0A0BAA5F0A0BAA5F0A0BCD5F0A0BCD5F0A0BCD5F0A0BCD5F0A0BCD5F0A0BD55F080BD55F080BD55F080BD55F080B125F080B185F070B185F070B185F070B185F070B185F070B185F070B225F050B225F050BC660FD0AC660FD0ACE60FC0ACE60FC0ACE60FC0ACE60FC0ACE60FC0ACE60FC0AD160FB0A6F5FFB0A6F5FFB0A6F5FFB0A6F5FFB0A6F5FFB0A775FFA0A775FFA0A775FFA0A775FFA0A655FFA0A725FF70A725FF70A9D5FF00A9D5FF00ABD5FEA0ABD5FEA0AD25FE70AD25FE70A9C62E60A9C62E60A9C62E60A9C62E60A9C62E60AA462E40AA462E40AA462E40AA462E40ADF5FE40ADF5FE40AE45FE40AE45FE40AE45FE40AE45FE40AE45FE40AE45FE40AEA5FE30AFB5FE30AFB5FE30AFB5FE30AFB5FE30AFB5FE30A0360E10A0360E10A0360E10A0360E10AF25FE10AF25FE10A0260DE0A0260DE0A1260DC0A1260DC0A0460DE0AF75FE00AF75FE00A6060DD0A6060DD0A6760DC0A6760DC0A6760DC0A6760DC0A6760DC0A6760DC0A5A60DE0AA95FDE0AC65FD90AC65FD90AAC5FDE0AAC5FDE0AAE5FDD0AAE5FDD0ABC5FDB0AB15FDD0A0A60DD0A0260DE0A0260DE0A0460DE0A0460DE0A0460DE0A0460DE0A0460DE0A0460DE0A975FDE0A975FDE0A975FDE0A975FDE0A975FDE0A975FDE0A955FDF0A955FDF0A955FDF0AB85FDF0AB85FDF0AB85FDF0AB55FDF0AB55FDF0AB55FDF0AB55FDF0AB55FDF0AB35FE00AA15FE00AA15FE00AA15FE00AA15FE00AA15FE00A9C5FE10A9C5FE10A8E5FE30A8E5FE30A365FE30A365FE30A335FE40A335FE40A335FE40A295FE50A295FE50A265FE60A265FE60A0F5FE70AFF5EEA0AFF5EEA0A075FE80A075FE80A075FE80A075FE80A075FE80A075FE80A5F5FE80A5F5FE80A5F5FE80A5F5FE80A5F5FE80A5F5FE80A5F5FE80A655FE70A655FE70A805FE90A805FE90A565FF00A565FF00A405FF40A235FF90A235FF90A315FF70A315FF70A465B020B465B020B485B010B485B010B405B030B405B030B305B050B4B5B010B4B5B010B025F020B025F020B025F020B025F020BE05E080BE05E080B125FFF0A055F010B055F010B9D5E040B9D5E040B955E050B955E050B6F5E0C0B6F5E0C0B5F5E0F0B525E110B525E110BE35C100BE35C100BE15C110BE15C110BDB5C110BD15C130BD15C130BD35C130BD35C130B365E130B365E130B435E110B4B5E0F0B4B5E0F0B465E100B465E100B485E100B385E120BB55E120BB55E120BB55E120BB75E120BAF5E130BAF5E130BB25E130BB25E130BB75E120BB75E120BB75E120BB55E120B6F5E1E0B6F5E1E0B425E260B425E260B225E2C0B305E2A0B965A2A0BE35A1C0B165B130B165B130B335B0E0B305B0F0B305B0F0B385B0D0B385B0D0B0264070BEA630B0BEA630B0BE5630C0BD7630F0BD7630F0BCD63110BF2630A0BF2630A0B345F050B3F5F040B3F5F040B295F070B295F070B2C5F070B2C5F070B2C5F070B2C5F070BCA5A1D0BCA5A1D0BCF5A1D0BCF5A1D0BCF5A1D0BDA5A1B0BDA5A1B0BF25A170B195B100BC660100BE9600A0B1161030B1161030B3161FD0A3361FD0A3361FD0A3E61FB0A4161FA0A5C62FA0A5962FB0A8962F20A8962F20AA662ED0AEE62E10AEE62E10AE662E20AE662E20A5163E20A5163E20A9063D70AAE63D20AAE63D20ABB63D00ACD63CC0ACD63CC0AF363C60A4A65C20A4A65C20A5265C00A5265C00A5265C00AF465A40AF465A40A0166A20A0166A20A1866A10A1566A10A1566A10A1566A10A1566A10A1566A10A20669F0A20669F0A28669E0A37629B0A37629B0A37629B0A8264340A1E63720A1E63720A7F628E0A7F628E0AE9627C0AE862910AE862910A2563870A2563870A2563870A1C645C0A1C645C0AFF63610AFF63610A0F66770AEA657D0AEA657D0AAD65880A95658C0A95658C0AD765810AD765810AD265820A4860820A4660820A3B60840A3B60840A2960870A3360850A3360850A3360850A3360850AC55E940A005F8A0A005F8A0AF05E8C0AFD5E8A0AFD5E8A0A055F890A055F890AF85E8B0A24638A0A24638A0A27638A0A27638A0A1F638B0A14638D0A14638D0AB7629D0A6862AB0A095CAB0AEF5BB00AEF5BB00ACF5BB50AF45BAF0AF45BAF0A015CAC0AD25BB50AD25BB50AD65FB10AD65FB10A2E60A20A2E60A20AFE5FAA0AFE5FAA0AFE5FAA0AC65FB40AB95FB70AEE5FB70AE35FB80AE35FB80AE35FB80AE35FB80AE35FB80AE35FB80AE35FB80A0360B30ADA60B60ADA60B60ADC60B50ADC60B50ADC60B50ADC60B50ADC60B50AD760B60AD760B60AA260B60AA260B60A9760B80A9760B80A9D60B70A9D60B70A9D60B70A9D60B70A9D60B70A4E60B80A4360BA0A4360BA0A4860B90A4860B90A4860B90A4860B90A3E60BB0A3E60BB0A385FC10A405FBF0A405FBF0A2D5FC30A455FBE0A455FBE0A355FC10A105FC80A105FC80A455FC80A455FC80A455FC80A455FC80A455FC80A455FC80A455FC80A455FC80A455FC80A1260C90A1260C90A1260C90A1260C90A1260C90A0A60CA0A0A60CA0A0A60CA0A0A60CA0AE15FCB0AE15FCB0AE15FCB0AE15FCB0AE15FCB0AC95FD00AC95FD00AB95FD20AB65FD30AF35ED30AEE5ED40AEE5ED40AEE5ED40AEE5ED40AEB5ED40AEB5ED40AEB5ED40AEB5ED40AD25FD40AC75FD60AC75FD60AC75FD60AC75FD60AC75FD60AC25FD70AA25FDD0AA25FDD0A325EDF0A2D5EE00A2D5EE00A255EE10A255EE10A255EE10A255EE10A255EE10A1A5EE30A125FE30A125FE30A125FE30A125FE30A0A5FE40A0A5FE40A0A5FE40A0A5FE40A025FE60A385FE60A085FEE0AFD5EF00AFD5EF00AED5EF30AE35EF50AE35EF50ADD5EF60ADD5EF60AED5CF60AED5CF60AED5CF60AED5CF60AED5CF60AED5CF60AED5CF60ADD5CF80ADD5CF80AE25EF80AE25EF80AE25EF80AE25EF80AE25EF80ACF5EFB0A975E050B975E050B975E050BBC59180BD259140BD259140BDA59130BF7590E0BF7590E0BF7590E0BF7590E0BEF590F0B06600F0B06600F0B23600A0B2B60090B2B60090B2B60090B2B60090B2B60090B3160080BFB5F080BFB5F080BFB5F080BFB5F080BF15F0A0BF15F0A0BE15F0C0BA95F160BA95F160BE35C130BF55C100BF55C100B185D0A0B485D020B485D020B1D5D090B1D5D090B155D0A0B8760080B8760080B8760080B8760080B8760080B8760080B8760080B8760080B8760080B835D100B835D100B005EFA0A485EEE0A485EEE0A555EEB0A955EE00A955EE00A975EE00A7D66E30A7D66E30A8866E10A8866E10A8266E20A8266E20A9266DF0AB266D90AB266D90A0362D50A1962D10A1962D10A4362CA0A4362CA0A5662C70A6062C50A6062C50A5B62C60A0863C40A0863C40AF362C70AF362C70A0563C40AC563A30AC563A30AC563A30AC563A30A0D66A30A8865BA0AAE65B30AAE65B30A0866A30A6066940A6066940A6266940A88668D0A3A728D0A2A72900A2A72900ADB719E0A0D72950A0D72950A2A72900A42728C0A42728C0AB770830ADF707D0ADF707D0AFC70770A0C71750A0C71750A2F716F0A2971700A2971700A7B736B0AA373640AA373640AA373640AF373560AF373560AE073590ADD735A0ADD735A0AF473530AD173590AD173590ACC735A0ACC735A0ACC735A0ACC735A0ACC735A0AC4735B0AF76D610AF76D610AEF6D620AE26D640AE26D640ACC6D680ABA6D6B0ABA6D6B0A5A6D7C0A6D6B7C0A6D6B7C0A6D6B7C0A6D6B7C0A6D6B7C0A4A6B820A4A6B820AB56A9C0A8B6AA30AAC68A30A2268BB0ABD67CD0ABD67CD0A8867D60A8867D60A4067E30AC366F80A6E66070B5D5D070BF55C190BF55C190B965C2A0B965C2A0B965C2A0B965C2A0B965C2A0B5F5B600B085D600BBE5C6D0B815C780B815C780B495C820BD45B960BD45B960B695BA90B2C5BB30B135CB30B0B5CB50B0B5CB50BA35BC70B465BD70B465BD70BB95AF00BE559150CE559150CA554270CA554270C4254380CF053460CF053460C8353590C3353670C3353670CC9527A0CEC548A0CEC548A0CBA54920C5554A40C5554A40C0D54B10C0D54B10CB053C10CB053C10C9157D00C3C57DF0C3C57DF0CD756F10C7556020D7556020D1356130DC355210DC355210DC5512F0DC5512F0D88513A0D4351460D4351460D0951500DB9505E0DB9505E0D8650670D22556E0D22556E0DD5547C0DD5547C0DB354820DB354820DDA52D40DDA52D40D4453C20D3850C20D3850C20D3850C20D3850C20D3850C20D0350CB0DD94FD30DD94FD30DAC4FDA0DBE57DF0DBE57DF0D9957E50D9957E50D7957EB0D4C57F30D4C57F30D3257F70DFF56000E4E56000E1E56080E1B56090E1B56090EF155100EE655120EE655120EE655120E0B560C0ED2580E0ED2580E0EBF58120EAD58150EAD58150E85581C0E85581C0E85581C0E6558210E7757230E7757230E6957250E6957250E37572E0E37572E0E37572E0E37572E0E3A572D0E0B58310E0B58310EFD57330EFD57330EF057360EDB57390EDB57390ECB573C0EE557380E1359380E3259320E3859310E3859310E3559320E3559320E3559320E3559320E3559320E145B320ED15A3D0ED15A3D0EBF5A400EBF5A400EB45A420EB45A420EB15A430EB15A430E8456470E8C56460E8C56460E9456440E9456440E9456440E9456440E9456440E9956430E565A430E6B5A400E6B5A400E6B5A400E6B5A400E6B5A400E6B5A400E6B5A400E6B5A400EEC5D2B0EEC5D2B0EC75D320EC75D320ECF5D300ECF5D300ECF5D300ECC5D310EE15D2D0E015A2D0E215A270E3E5A220E3E5A220E595A1E0E5E5A1D0E5E5A1D0E4B5A200E4B5A200EBF5C1F0ECF5C1C0ECF5C1C0EF55C150EF55C150E0A5D120E425D080E425D080E5A5D040EB25F010EB25F010ED75FFA0DC55FFE0DC55FFE0DD75FFA0DD75FFA0DE25FF90DE25FF90DB35CF90DCB5CF40DE85CEF0DE85CEF0D155DE70D155DE70D455DDF0D655DD90D655DD90D2F61D70D3561D60D3561D60D3A61D50D4A61D30D4A61D30D6461CE0D8261C90D8261C90D8B5FC40DA35FBF0DA35FBF0DB85FBC0DD05FB80DD05FB80DEE5FB30D0060AF0D0060AF0DC760AC0DB960AE0DB960AE0DBF60AD0DBF60AD0DBF60AD0DBF60AD0DBF60AD0DCF60AA0D365EA60D365EA60D635E9E0D835E980D835E980DA65E920DB05E900DB05E900DBB5E8E0D88618D0D88618D0D88618D0D88618D0D88618D0D88618D0DD261800DD261800DEA617C0D5D61790D5D61790D5D61790D6561770D6561770D6361780D6861770D6861770D6D61760DCC5E760DCC5E760DCC5E760DCC5E760DD45E740DD45E740DD45E740DD45E740DD45E740DC75E730DC75E730DC75E730DC75E730DC75E730DD55E710DF75E6B0DF75E6B0D055F690DE760650DE760650DEC60640DEC60640DEC60640DEC60640DEC60640DF160630DF160630D645F610D6A5F600D6A5F600D6A5F600D6A5F600D6A5F600D6A5F600D6A5F600D6A5F600DFF5E600DFF5E600DFD5E610DFD5E610DFD5E610DFD5E610DFD5E610DFD5E610DFD5E610DC75E610DC75E610DC75E610DC75E610DC75E610DC75E610DC75E610DC75E610DC75E610DB05E620DB05E620DAE5E620DAE5E620DAE5E620DAE5E620DAE5E620DAE5E620DAE5E620DC05E620DC05E620DC05E620DBD5E630DBD5E630DBD5E630DBD5E630DBD5E630DB85E640D945E640D945E640D945E640D945E640D915E640D915E640D915E640D915E640D915E640D8C5E650D8C5E650D8C5E650D8C5E650D8C5E650D815E670D815E670D815E670D815E670D705E670D655E690D655E690D655E690D655E690D655E690D585E6B0D585E6B0D285E730D905C730D835C760D735C790D735C790D695C7A0D535C7E0D535C7E0D515C7F0D515C7F0D9A5C7E0D905C800D905C800D925C7F0D805C830D805C830D6A5C860D655C870D655C870D715C880D715C880D6C5C890D675C8A0D675C8A0D545C8D0D525C8E0D525C8E0D4A5C8F0DC65C8F0DC65C8F0DC65C8F0DC65C8F0DC35C900DC35C900DC35C900DC35C900DC35C900D7E5D910D7E5D910D7E5D910D7E5D910D7E5D910D795D920D795D920D795D920D795D920D9C5D920D975D930D975D930D975D930D975D930D975D930D8C5D950D8C5D950D6A5D9B0DFF5B9C0DFF5B9C0DFF5B9C0DFF5B9C0DFF5B9C0DFA5B9D0DFA5B9D0DFA5B9D0DFA5B9D0D5C5D9D0D5A5D9E0D5A5D9E0D5A5D9E0D5A5D9E0D5A5D9E0D545D9F0D325DA50D325DA50DFD5BA60DF55BA70DF55BA70DF55BA70DF55BA70DF55BA70DF55BA70DF55BA70DF55BA70D105DA70D155DA60D155DA60D1D5DA50D1B5DA60D1B5DA60D1B5DA60D1B5DA60D1B5DA60D975DA60D975DA60D975DA60D975DA60D975DA60D975DA60D995DA50D995DA50D995DA50D645DA50D645DA50D6A5DA40D7C5DA10D7C5DA10D875D9F0D875D9F0D995D9C0D9F5D9B0D135F9B0D185F9A0D185F9A0D185F9A0D185F9A0D185F9A0D185F9A0D205F990D205F990DF35D990DF35D990DF35D990DF35D990DF85D980D105E930D105E930D185E920D185E920D8F5E930D995E910D995E910D9F5E900DAF5E8D0DAF5E8D0DA95E8E0DA95E8E0DA95E8E0D4462790DF461860DF461860DF761860DF761860DEC61880DD7618C0DD7618C0DEC61880DB15B880DB15B880DC15B850DC15B850DC45B850D
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

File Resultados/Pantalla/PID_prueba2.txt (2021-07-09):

475CF10D475CF10D395CF30D6F5CF30D675CF40D5C5CF60D5C5CF60D4F5CF90D4F5CF90D495CF90D495CF90D3C5CFC0D4E5CFC0D415CFE0D395C000E395C000E335C000E335C000E2E5C010E2E5C010E295C020E815C020E7C5C030E745C050E745C050E715C050E715C050E6F5C060E6F5C060E6C5C060ED65C060ED45C060ECC5C080ECC5C080EC15C0A0ECD530A0EC8530B0EC8530B0EC3530C0E7C530C0E71530D0E71530D0E66530F0E6C530E0E6C530E0E66530F0E66530F0E6453100E9953100E9E530F0E9E530F0E8953130E8953130E6E53170E6E53170E54531C0E54531C0E1E51220E1E51220E0E51250E0E51250E0051270E0051270EFE50270EFE50270E0051270EF152270EF652260EF652260EFE52250EFE52250EFE52250EFE52250E5053160E5053160E6856170E6856170E6856170E6E56160E6E56160E7856140E7856140E7856140E7856140E8854140E8854140E8854140E8854140E8854140E8255E90D8255E90D8255E90D8255E90D995BE90DA65BE60DA65BE60DEE5BDA0DEE5BDA0DE65BDB0DE65BDB0D195CD30D195CD30DC75BC20DC75BC20DFA5BB90DFA5BB90D375CAE0D375CAE0D375CAE0D365D820D365D820DAA617E0DAA617E0DCD61780DCD61780DF561710DF561710D4C62610D4C62610D9462550D7F5E550DC65E480DC65E480DF45E400DF45E400D195F3A0D195F3A0D5B5F2E0D5B5F2E0DE0611E0D38620E0D38620E0D8562010D8562010DDF62F10CDF62F10C1463E80C1463E80CDD64DC0CDD64DC0C1A65D20C1A65D20C4465CA0C7765C10C7765C10CB465B70CB465B70C0564A80C0564A80C3F649E0C3F649E0C7A64940C7A64940CA9648B0CA9648B0CC764860C1462860C49627D0C49627D0C7E62740CB6626A0CB6626A0CB6626A0CB6626A0C1B63580CE764580CED64580C0765530C0765530C1F654F0C1F654F0C4465480C4465480C7F653E0C97623E0CC762360CC762360CE662300C09632A0C09632A0C3463230C3463230C63631A0CC6641A0CE864140CE864140C06650F0C06650F0C0D650E0C0D650E0C0B650E0C0B650E0CA062080CA062080CC362020CC362020CEB62FB0BEB62FB0BEB62FB0B0B63F50B0B63F50B9963F20B9963F20BA463F00BA463F00BD463E80BD463E80BD163E80BD163E80BD463E80B1962E80B2462E60B2962E50B2962E50B2962E50B2962E50B3B62E20B3B62E20B3962E20B8861E20B8561E30B8561E30B8A61E20B8A61E20B8061E40B8061E40B8861E20B8861E20BC760E20BC760E20BBD60E40BBD60E40BBD60E40BBD60E40BBF60E30BBF60E30BC260E30B8D60E30B8D60E30B8D60E30B8A60E30B8A60E30B7A60E60B7A60E60B6860E90B6860E90B565FEB0B565FEB0B315FF10B315FF10B165FF60B165FF60B495FED0B495FED0B3B5FEF0BB75FEF0BBF5FEE0BBF5FEE0BB75FEF0BB75FEF0B655FFE0B655FFE0B4D5F020C4D5F020CE85C040CE85C040CFB5C000CFB5C000CF05C020CF05C020CB85C0C0CB85C0C0C865C150C025D150CE75C190CE75C190CD75C1C0CD75C1C0CEF5C180CEF5C180CF45C170CF45C170CFA5D1E0CFA5D1E0CEC5D200CEC5D200C075E1C0C075E1C0C0F5E1A0C0F5E1A0C0C5E1B0CEB5F1B0CDD5F1D0CDD5F1D0CB05F250CB05F250C8E5F2B0C8E5F2B0C765F2F0C765F2F0C4B5B330C4B5B330C4B5B330C415B350C415B350C415B350C465B340C465B340C495B330CD05E330CCE5E340CCE5E340CCE5E340CC65E350CC65E350CB35E380CB35E380CA05E3C0CE45C3F0CE45C3F0CDF5C400CDF5C400CD25C420CEC5C3E0CEC5C3E0CDF5C400CDF5C400C255E420C205E430C205E430C035E480C035E480C0D5E460C155E450C155E450C2155450CD955400CD955400CB955460CB955460CA655490C9E554B0C9E554B0C9E554B0C99554B0CBB534B0C8053560C8053560C8053560C8053560C8053560C8053560C7053580C50535E0C35525E0C2F525F0C1A52630C1A52630C4D525A0C4D525A0C35525E0C3F525C0C3F525C0C5F555C0C5F555C0C5F555C0C5F555C0C5F555C0C5F555C0C57555D0C57555D0C57555D0CCA545D0CCA545D0CC2545E0CC4545E0CC4545E0CDF54590CF754550CF754550C4455480CA858480CC058440CE5583D0CE5583D0C1A59340C1859340C1859340C1059360C1059360C545A2B0C6C5A270C6C5A270CA45A1E0CEE5A110CEE5A110C065B0C0C065B0C0C415B020CB45EF90BB45EF90BE65EF10B1E5FE70B1E5FE70B4E5FDE0B4E5FDE0BB65FCC0BB65FCC0BFC5FC60B3960BC0B3960BC0B7960B10B7960B10B8360AF0BC360A40BC360A40B8160AF0B975CAE0B975CAE0BC95CA50B2B5D940B2B5D940BF85D700BF85D700B5A5E5F0BAA5E510BD768510B0969480B1C69450B1C69450B51693C0B51693C0B6169390B9B692F0B9B692F0B3265230B7465170B7465170BC965080BC965080BFC65FF0A3E66F40A3E66F40A7166EB0A8167ED0A8167ED0AB167E40AB167E40AE667DB0A3968CD0A3968CD0A9868BC0AE668AF0A246AAF0A5A6AA50A8C6A9D0A8C6A9D0AC96A920AC96A920AC96A920ADF6A8E0ADF6A8E0A71668E0A7867600A4A67680A4A67680A1367720A1367720A6D67620A92675C0A92675C0ACB695E0A156A510A156A510AE6695A0AD6695D0AD6695D0A056A540A056A540A686A430A5C67430A5C67430A8F673A0AB767330AB767330AA967360AC767300AC767300AE9672A0ABC67290ABC67290AF167200AF167200AF167200AF167200A9F672E0A9F672E0AD167250AA764240AA764240A88642A0A7D642C0A7D642C0A5864320A5864320A3D64370A5064340A5661340A70612F0A86612B0A86612B0A8B612A0A76612E0A76612E0A8B612A0A8B612A0A36652A0A36652A0AD1643C0AD1643C0AC1643F0A9764460A9764460A9764460A81644A0A6A5E4A0A105E5A0A1A5E580A1A5E580A2A5E550A2A5E550A305E540A7A5E470A7A5E470A1F634A0ABE694E0ABE694E0A9669550A9669550A5E695F0A5169610A5169610A2969680A4F63700A4F63700A2F63760A2F63760A15637A0A15637A0A1F63780A17637A0A17637A0A84667E0A84667E0A6A66830A44668A0A44668A0A5266870A5266870A5266870AD2659D0A54639D0A57639D0A57639D0A3C63A20A3A63A20A3A63A20A1A63A80A1A63A80A1A63A80A3766A80A2F66A90A2F66A90A1F66AC0A2766AA0A2766AA0A2766AA0A2766AA0A2766AA0A4367AA0A4367AA0A4367AA0A1B67B10A1B67B10A3867AC0A2367B00A2367B00A1867B20A6766B20A8C66AB0A9466AA0A9466AA0AC966A10AC966A10A1167940A1167940A1167940A4F7F270A857E4A0A857E4A0A857E4A0A037E610ACE7D6A0ACE7D6A0A437D830A437D830AFB59880A355A7E0A355A7E0A455A7B0A455A7B0A505A790A505A790A5A5A770A5A5A770A4F6B770A4F6B770A4F6B770A476B790A476B790A476B790A476B790A476B790A476B790A57687A0A57687A0A3A687F0A3A687F0A0F68870AEF678C0AEF678C0AD867900AD867900A9E64920A9E64920A0D6B9F0AD86AA80AD86AA80A8D6AB50A8D6AB50A2B6AC60A2B6AC60A6165CA0A1965D70A1965D70AC964E40AC964E40AAF64E90AAF64E90A1D64030B1D64030BDF60150BDF60150B54602D0B54602D0B755F540B755F540BF65E6A0BF65E6A0B395E8B0BB7578B0B0D57A90B0D57A90B5B56C80B5B56C80BA655E70BA655E70BFC54050CFC54050C394E290C394E290C7A4D4B0C7A4D4B0CBD4C6B0CBD4C6B0CFE4B8D0CFE4B8D0C594BAA0CC74FAA0C254FC60C254FC60C754EE50C754EE50C754EE50CC04B5E0DC04B5E0DB84B5F0DD4435F0DA443670DA443670D6F43710D6F43710D1D42AC0D1D42AC0DD841B80DD841B80DC74DC30D944DCC0D944DCC0D944DCC0D184DE10D184DE10D9B4CF70D3B4C080E3B4C080E894D1B0E894D1B0E244D2D0ECC4C3C0ECC4C3C0E5D4C4F0E5D4C4F0E004C600E004C600E994C6D0E994C6D0E4C4C7A0E0C4C860E0C4C860EDF4B8D0EDF4B8D0E9C4B990E574BA50E384FA50EF84EB00EF84EB00EA34EBF0E704EC80E704EC80E504ECD0E504ECD0E304ED30E994EDA0E994EDA0E6E4EE10EAB50E10E7650EA0E4150F40E4150F40E2650F80E2650F80E5E52FE0E4152030F4152030F2752080F2752080F07520D0F07520D0F07520D0F07520D0F36550D0F36550D0F36550D0F36550D0F36550D0F36550D0F3B550D0F3B550D0F33550E0F6A570E0F6A570E0F6A570E0F6A570E0F6F570D0F6F570D0F6F570D0F6F570D0F6F570D0FA4570D0FAF570B0FD457050FD457050FF257000FF257000F0C58FB0E0C58FB0E2958F60E5C5CF10E5C5CF10E795CEC0E795CEC0E945CE70EAC5CE30EAC5CE30EBC5CE00EBC5CE00E7B5BDD0E7B5BDD0E905BDA0EB35BD30EB35BD30EDB5BCD0EDB5BCD0E035CC60E2A5CBF0ED45DBF0EF45DB90EF45DB90E115EB40E365EAD0E365EAD0E565EA80E565EA80E7B5EA10E465EA10E565E9F0E735E9A0E735E9A0E9B5E930E9B5E930EC55E8B0EC55E8B0EF85E820E5C607C0E5C607C0E7960770E7960770E8F60730E8F60730EC1606A0EF160620EF160620EB960590EB960590EEC60500EEC60500E1461490E1461490E3B61420E3B61420E61613C0E9561360E9561360EAF61310EAF61310ED6582D0ED6582D0EF158280EF158280E0B59230E8D56230EA8561F0EC0561A0EC0561A0EE356140EE356140E02570F0E02570F0E15570C0ED8570C0EEB57080EEB57080EE857090EE857090EE857090EE857090E1A58000E1A58000ED355030ED355030EEE55FE0DEE55FE0DF155FE0DF155FE0DF955FC0DF955FC0D1156F80D5756F80D5F56F70D5F56F70D7556F30D7556F30D7556F30D9756ED0D9756ED0DC756E50D1858E50D3058E00D3058E00D5058DB0D5058DB0D6D58D60D6D58D60D6D58D60D8A58D10D9C58D10DCE58C80DCE58C80D0959BE0D0959BE0D4659B30D4659B30D7659AB0D7659AB0D125E9F0D125E9F0D3A5E990D3A5E990D795E8D0D795E8D0DC95E7F0DC95E7F0DFE5E760DD15D760D195E6A0D565E5F0D565E5F0D885E560D885E560DB85E4E0DB85E4E0DE05E470DC65F470D0C603B0D0C603B0D51602F0D51602F0DB0601E0D1B610C0D1B610C0D6061FF0CF964FF0C3465F50C3465F50C7965E90C7965E90CA965E10CA965E10CE065D70CE065D70C8C63CA0C8C63CA0CC963BF0CC963BF0C0164B50C0164B50C4664A90C4664A90C91649C0C52639C0C9163910CDE63840CDE63840C1E64780C1E64780C4364720C4364720C7B64680C7365680C9965620C9965620CC0655B0CC0655B0CEE65530CEE65530C13664C0C13664C0C1164430C1164430C36643D0C36643D0C5664370C5664370C96642C0CB864260CB864260CE6641E0CE6641E0C0665180C0665180C1B65150C1B65150C3365110C3365110C4D650C0C5763070C5763070C5C63060C5C63060C7963010C7963010C8163FF0B8163FF0BB163F70B9662F70BA662F40BA662F40BC862EE0BC862EE0BD862EB0BD862EB0BC662EF0BC862EE0BBF61EE0BA961F20BA961F20BB461F00BB461F00BAF61F10BAF61F10BAF61F10BAF61F10B6E60EE0B6E60EE0B7160EE0B7160EE0B7B60EC0B8060EB0B8060EB0B7E60EB0B7E60EB0BBF60EC0BBF60EC0BC560EB0BC560EB0BCA60EB0BCA60EB0BB760EE0BB760EE0BB260EF0B1360EF0B0560F10B0560F10B0B60F00B0B60F00B0860F10B0860F10B1360EF0B1360EF0B4260F00B4260F00B2B60F40B2B60F40B2B60F40B1860F70B1860F70BF35FFE0BF35FFE0B605D010C605D010C4D5D050C4D5D050C525D040C525D040C625D010C625D010C555D030CAF5F030CA55F050CA55F050CA75F050CA75F050C7D5F0C0C7D5F0C0C585F120C585F120C765C180C765C180C6B5C190C6E5C190C6E5C190C735C180C735C180C605C1B0C605C1B0C845D230C845D230C775D250C775D250C6F5D270C6F5D270C6C5D270C6C5D270C595D2B0CF95D2B0CE45D2E0CE45D2E0CD65D310CD65D310CDE5D2F0CDE5D2F0CCE5D320CCE5D320C685D340C685D340C665D350C735D320C735D320C735D320C6E5D330C495D3A0C495D3A0CCB5C400CCB5C400CA85C460CA85C460CB35C450CB35C450CC05C420CC05C420CD85C3E0CFD5E3E0CED5E410CD35E450CD35E450CD05E460CD05E460C085F3C0C085F3C0CFD5E3E0CA55E3E0C9F5E3F0C9F5E3F0C9F5E3F0C605E4A0C605E4A0C655E490C655E490C655E490CBC5C490CBC5C490CB45C4B0CB45C4B0CB15C4B0CB45C4B0CB45C4B0CCE5C460CC45C480CA25E480CB75E440CB75E440CBF5E430C9A5E490C9A5E490CA25E480CAE55480C99554B0C33544F0C33544F0C3054500C2654520C2654520C1654540C1654540CF953590CFB53590CA353590CA353590C98535B0C98535B0CA053590C8B535D0C8B535D0C7853600C6653640C4253640C4253640C3753650C2253690C2253690C10536C0CFD52700CFD52700C1A536B0CBC536A0CBC536A0CA7536E0CC253690CC253690CA4536E0CA4536E0CD253660CD253660C18575C0C18575C0C18575C0C3A57560C4557540C4557540C5257520C5257520C3057580CB056520CB056520CC5564F0CC5564F0CE0564A0C38573B0C38573B0C5857350C87572D0CAE5B2D0CDE5B250CDE5B250CFC5B1F0C295C180C295C180C515C110C965C050C965C050CE95EF90BE95EF90B195FF10B565FE60B565FE60B795FE00B9E5FDA0B9E5FDA0BD65FD00B505ED00B7D5EC80BB55EBE0BB55EBE0BF25EB40BF25EB40B045FB10B045FB10B4F5FA40B0562970B0562970B3D628D0B3D628D0BCF62730B1763670B1763670B07636A0B1D63660BCC61660BDE61630B1462590B1462590BA8623F0BFB62310BFB62310B2863290B6565290B8C68210BB1681B0BB1681B0BEE68100B3969030B3969030B6B69FA0AC369EB0AC369EB0A7567EC0ABA67E00ABA67E00AF767D50AF767D50A1A68CF0A5468C50A5468C50A7468BF0A8769B10A2D6B680A2D6B680AC06A7B0AC66A7A0AC66A7A0AE36A750AE36A750A0B6B6E0A9C6F5B0A9C6F5B0AC96F530AC96F530AF46F4C0A0970480A0970480A44703E0A7670350A4369350A5169330A6369300A6369300A5B69310A5B69310A5B69310A5B69310A5B69310A2B67200A2667210A2667210A1167250AF1662A0AF1662A0AF1662A0AEE662B0AEE662B0A5961300A8961280A8961280AA161230A9161260A9161260A9661250A7F612A0A7F612A0AD1642A0ACF63560A6F643B0A6F643B0A8F64350A8F64350AB6642E0AD464290AD464290A4D61380A45613A0A45613A0A1261430A1261430A0361450A1D61410A1D61410AFB60470A0C61470A0461480A0C61470A0C61470A0A61470A0A61470A0261490AEA604D0AEA604D0AC3614F0A9661570A9661570A9361570A4A68570A4468580A32685C0A32685C0A37685B0ABB675B0A9667610AA6675E0AA6675E0A9B67600A9B67600AB1675D0A4C676E0A4C676E0AED64750AED64750ADA64780ADA64780AA864810AD2647A0AD2647A0AEA64760AEA64760A47677E0A47677E0A2D67830A2767840A2767840A2767840A2767840ADE65BD0ADE65BD0AB460AD0AB460AD0AC460AA0AAC60AE0AAC60AE0ABF60AB0ABF60AB0A8760B50A8760B50A2865BB0A0B65C00A0B65C00AD364CA0AD364CA0AA864D10AA864D10A7E64D90A5E64DE0A4161DE0A1E61E40A1E61E40AF160EC0AF160EC0AD160F20A9460FD0A9460FD0A7760020B7760020B3C600C0B3C600C0BD25F1E0BD25F1E0B8D5F2A0B8D5F2A0B505F350B505F350BC65B3C0BC65B3C0B9C5B430B9C5B430B495B510B495B510BD45A660BD45A660BD45A660B2F5D660BC55C780BC55C780B505C8D0B505C8D0B105C980B105C980BDD5BA10BDD5BA10BDF55B50BDF55B50B8755C40B8755C40B5255CE0B5255CE0BE854E00BE854E00BB854E90BDF58E90BAD58F10BAD58F10B6558FE0B6558FE0BD95E0A0CD95E0A0C7A5E1A0C7A5E1A0C715C280C715C280C245C350C245C350CD55B430CD55B430C985B4E0C985B4E0C585B590C6B5D590C3E5D610C3E5D610C565D5D0C565D5D0C415D600C415D600C1C5D670C1C5D670CB260710CB260710C7A607A0C7A607A0C5060820C5060820C3360870C3360870C2860890C1660890CEC5F900CEC5F900CCC5F960CCC5F960CB75F990CB75F990C915FA00C915FA00CFE5EA40CFE5EA40CE05EA90CE05EA90CB35EB10CB35EB10C8B5EB80C8B5EB80C665EBF0C895EBF0C645EC50C645EC50C4A5ECA0C4A5ECA0C175ED20CF55DD80CF55DD80CF55DD80C325CE30C325CE30C025CEC0C025CEC0CDA5BF20CDA5BF20CA25BFC0CA25BFC0C855B010D0E5B0A0D0E5B0A0DE15A120DE15A120DB95A190DB95A190D8C5A200D8C5A200D615A280DA05B280D715B300D715B300D435B380D145B400D145B400DE65A480DE65A480DC15A4F0D71594F0D4B59550D4B59550D23595C0DFE58630DFE58630DE158680DE158680DBE586E0DEC596E0DC659740DA7597A0DA7597A0D7959820D7959820D965B870D965B870D775B8D0D775B8D0D575B920D3C5B970D3C5B970D3C5B970D1F5B9C0D075BA00D075BA00DE25AA70DA55BA70D925BAA0D925BAA0D775BAF0D775BAF0D5A5BB40D585BB40D585BB40D325BBB0D195CBB0D095CBE0D095CBE0D0B5CBD0DF65BC10DF65BC10DF15BC20DF15BC20DF15BC20DE15DC20DE15DC20DE15DC20DD15DC50DD15DC50DA95DCC0DA95DCC0D945DCF0D815DD30D0D5CD30DF85BD60DF85BD60DEB5BD90DD85BDC0DD85BDC0DCD5BDE0DCD5BDE0DD05BDD0DB65CDD0DB45CDE0DA65CE00DA65CE00DA95CE00DA95CE00D945CE30D945CE30D7F5CE70D285CEA0D285CEA0D155CED0D155CED0D085CEF0DFD5BF10DFD5BF10DF85BF20DF85BF20D465CF40D465CF40D435CF40D435CF40D2E5CF80D215CFA0D215CFA0D165CFC0D165CFC0DE35BFF0DE35BFF0DE55BFF0DE55BFF0DEB5BFE0DEB5BFE0DEB5BFE0DEB5BFE0DE85BFE0D635D000E635D000E495D050E495D050E3B5D070E3B5D070E395D070E395D070E395D070E415C070E3E5C080E3E5C080E365C090E2B5C0B0E2B5C0B0E215C0D0E2D530D0E22530F0E22530F0E1553110E1553110E1553110E1553110E1253120E1053120E1053120E25530E0E52540E0E3A54130E3A54130E2D54150E2D54150E1554190E1554190EF2531F0EF2531F0E63511F0E63511F0E63511F0EDB50370EDB50370EEE50330EEE50330EFB50310EFE50310EDA50310EDA50310EDA50310EDA50310EDA50310EDA50310EDA50310EDA50310EDA50310EA453300EA453300EBA532C0EBA532C0EBA532C0ECF53280ECF53280EF453220EF453220EED561C0EED561C0EED561C0EF2561B0EF2561B0E0A57170E0A57170E0A57170E2557120E9F55120ED755080ED755080ED755080E1F56FC0D1F56FC0D6956EF0D6956EF0DA456E50DF85BE50D2D5CDB0D2D5CDB0D625CD20D625CD20D625CD20D975CC90D975CC90DC25CC10D3C5BC10D895BB40D895BB40DD65BA60DD65BA60D1E5C9A0D1E5C9A0D785C8A0D785C8A0D3361800D7061750D7061750DB761690DB761690DF2615F0DF2615F0D2F62540D2F62540D1261480D1261480D5A613B0D5A613B0DAF612C0DAF612C0D0C621C0D0C621C0D63620D0DCE620D0D2563FE0C2563FE0C7563F00C7563F00CB863E40CB863E40CF263DA0CF263DA0C9964CF0CD764C50CD764C50C1465BA0C1465BA0C4B65B00C4B65B00C6E65AA0C6E65AA0C6F63A00C6F63A00CA963960CA963960CF463890CF463890C3E647C0C3E647C0C7E64710C2766680C2766680C4A66620C4A66620C72665B0C72665B0C8A66570C8A66570CA966510C9C61510CD461470CD461470C06623E0C06623E0C3662360C5962300C5962300C5B62300CF363300C15642A0C15642A0C3564240C3564240C2864260C2864260C5B641E0C60641D0C3B621D0C3B621D0C5862180C5862180CB062080CB062080CC762040CEA62FE0BEA62FE0BCE64FD0BCE64FD0BCB64FE0BCB64FE0BDB64FB0BDB64FB0BEE64F80BEE64F80BEE64F80BF662EC0BF662EC0B3663E10B3663E10B2463E40B2463E40B3963E10B3963E10B4163DF0BB362DF0B9062E50B9062E50BA062E30BA062E30B9B62E40B9B62E40BA662E20BA662E20BA65FE60BA65FE60BA05FE70BA05FE70BA35FE60BA35FE60BA05FE70BA05FE70BCB5FDF0BBB61DF0BB061E10BB061E10BAE61E20BAE61E20BA661E30BA661E30BC861DD0BC861DD0B7A61DB0B7A61DB0B6561DF0B6561DF0B5A61E10B5A61E10B3D61E60B3D61E60B3061E80BA05EE80BB05EE50BB05EE50BD55EDF0BD55EDF0BE85EDC0BE85EDC0B0B5FD60B0B5FD60B8263D70B8263D70B5D63DE0B5D63DE0B0363ED0B0363ED0BF062F10BF062F10BBB62FA0BFB5AFA0BEB5AFD0BEB5AFD0B0D5BF70B0D5BF70BEB5AFD0BEB5AFD0BEB5AFD0BEB5AFD0BAB5C0E0CAB5C
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

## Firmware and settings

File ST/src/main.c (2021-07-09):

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
/* Includes ------------------------------------------------------------------*/
#include "main.h"
#include "cmsis_os.h"

/* USER CODE BEGIN Includes */
#include "aplicacion.h"
/* USER CODE END Includes */

I2C_HandleTypeDef hi2c1;

TIM_HandleTypeDef htim1;
TIM_HandleTypeDef htim2;
TIM_HandleTypeDef htim4;
TIM_HandleTypeDef htim5;
TIM_HandleTypeDef htim8;

UART_HandleTypeDef huart4;
UART_HandleTypeDef huart2;
DMA_HandleTypeDef hdma_uart4_rx;
DMA_HandleTypeDef hdma_usart2_tx;

/* Definitions for led_estadoTask */
osThreadId_t led_estadoTaskHandle;
const osThreadAttr_t led_estadoTask_attributes = {
  .name = "led_estadoTask",
  .priority = (osPriority_t) osPriorityLow,
  .stack_size = 128 * 4
};
/* Definitions for controlTask */
osThreadId_t controlTaskHandle;
const osThreadAttr_t controlTask_attributes = {
  .name = "controlTask",
  .priority = (osPriority_t) osPriorityRealtime,
  .stack_size = 512 * 4
};
/* Definitions for toma_datosTask */
osThreadId_t toma_datosTaskHandle;
const osThreadAttr_t toma_datosTask_attributes = {
  .name = "toma_datosTask",
  .priority = (osPriority_t) osPriorityHigh,
  .stack_size = 128 * 4
};
/* Definitions for envio_datosTask */
osThreadId_t envio_datosTaskHandle;
const osThreadAttr_t envio_datosTask_attributes = {
  .name = "envio_datosTask",
  .priority = (osPriority_t) osPriorityLow1,
  .stack_size = 128 * 4
};
/* Definitions for recpecion_datos */
osThreadId_t recpecion_datosHandle;
const osThreadAttr_t recpecion_datos_attributes = {
  .name = "recpecion_datos",
  .priority = (osPriority_t) osPriorityLow1,
  .stack_size = 128 * 4
};
/* Definitions for accion_controlXQueue */
osMessageQueueId_t accion_controlXQueueHandle;
const osMessageQueueAttr_t accion_controlXQueue_attributes = {
  .name = "accion_controlXQueue"
};
/* Definitions for distXQueue */
osMessageQueueId_t distXQueueHandle;
const osMessageQueueAttr_t distXQueue_attributes = {
  .name = "distXQueue"
};
/* Definitions for TimerLedEstado */
osTimerId_t TimerLedEstadoHandle;
const osTimerAttr_t TimerLedEstado_attributes = {
  .name = "TimerLedEstado"
};
/* Definitions for TimerControl */
osTimerId_t TimerControlHandle;
const osTimerAttr_t TimerControl_attributes = {
  .name = "TimerControl"
};
/* Definitions for TimerTomaDatos */
osTimerId_t TimerTomaDatosHandle;
const osTimerAttr_t TimerTomaDatos_attributes = {
  .name = "TimerTomaDatos"
};
/* Definitions for TimerEnvioDatos */
osTimerId_t TimerEnvioDatosHandle;
const osTimerAttr_t TimerEnvioDatos_attributes = {
  .name = "TimerEnvioDatos"
};
/* Definitions for TimerRecepcionDatos */
osTimerId_t TimerRecepcionDatosHandle;
const osTimerAttr_t TimerRecepcionDatos_attributes = {
  .name = "TimerRecepcionDatos"
};
/* Definitions for salidaMutex */
osMutexId_t salidaMutexHandle;
const osMutexAttr_t salidaMutex_attributes = {
  .name = "salidaMutex"
};
/* Definitions for estado_controlMutex */
osMutexId_t estado_controlMutexHandle;
const osMutexAttr_t estado_controlMutex_attributes = {
  .name = "estado_controlMutex"
};
/* Definitions for consignaMutex */
osMutexId_t consignaMutexHandle;
const osMutexAttr_t consignaMutex_attributes = {
  .name = "consignaMutex"
};
void SystemClock_Config(void);
static void MX_GPIO_Init(void);
static void MX_DMA_Init(void);
static void MX_TIM1_Init(void);
static void MX_TIM2_Init(void);
static void MX_TIM4_Init(void);
static void MX_I2C1_Init(void);
static void MX_TIM5_Init(void);
static void MX_USART2_UART_Init(void);
static void MX_UART4_Init(void);
static void MX_TIM8_Init(void);
void Led_EstadoTask(void *argument);
void ControlTask(void *argument);
void Toma_DatosTask(void *argument);
void Envio_DatosTask(void *argument);
void Recepcion_DatosTask(void *argument);
void CallbackTimerLedEstado(void *argument);
void CallbackTimerControl(void *argument);
void CallbackTimerTomaDatos(void *argument);
void CallbackTimerEnvioDatos(void *argument);
void TimerRecepcionDatosCallback(void *argument);

/**
  * @brief  The application entry point.
  * @retval int
  */
int main(void)
{
  /* MCU Configuration--------------------------------------------------------*/

  /* Reset of all peripherals, Initializes the Flash interface and the Systick. */
  HAL_Init();

  /* Configure the system clock */
  SystemClock_Config();

  /* Initialize all configured peripherals */
  MX_GPIO_Init();
  MX_DMA_Init();
  MX_TIM1_Init();
  MX_TIM2_Init();
  MX_TIM4_Init();
  MX_I2C1_Init();
  MX_TIM5_Init();
  MX_USART2_UART_Init();
  MX_UART4_Init();
  MX_TIM8_Init();
  /* USER CODE BEGIN 2 */

  // Inicialización de periféricos
  HAL_I2C_Init(&hi2c1);
  HAL_TIM_PWM_Start(&htim1, TIM_CHANNEL_1);
  HAL_TIM_PWM_Start(&htim2, TIM_CHANNEL_1);
  HAL_TIM_OC_Start_IT(&htim4, TIM_CHANNEL_1);
  HAL_UART_Init(&huart2);
  HAL_UART_Init(&huart4);

  /* USER CODE END 2 */

  /* Init scheduler */
  osKernelInitialize();
  /* Create the mutex(es) */
  /* creation of salidaMutex */
  salidaMutexHandle = osMutexNew(&salidaMutex_attributes);

  /* creation of estado_controlMutex */
  estado_controlMutexHandle = osMutexNew(&estado_controlMutex_attributes);

  /* creation of consignaMutex */
  consignaMutexHandle = osMutexNew(&consignaMutex_attributes);

  /* USER CODE BEGIN RTOS_MUTEX */
  /* add mutexes, ... */
  /* USER CODE END RTOS_MUTEX */

  /* USER CODE BEGIN RTOS_SEMAPHORES */
  /* add semaphores, ... */
  /* USER CODE END RTOS_SEMAPHORES */

  /* Create the timer(s) */
  /* creation of TimerLedEstado */
  TimerLedEstadoHandle = osTimerNew(CallbackTimerLedEstado, osTimerPeriodic, NULL, &TimerLedEstado_attributes);

  /* creation of TimerControl */
  TimerControlHandle = osTimerNew(CallbackTimerControl, osTimerPeriodic, NULL, &TimerControl_attributes);

  /* creation of TimerTomaDatos */
  TimerTomaDatosHandle = osTimerNew(CallbackTimerTomaDatos, osTimerPeriodic, NULL, &TimerTomaDatos_attributes);

  /* creation of TimerEnvioDatos */
  TimerEnvioDatosHandle = osTimerNew(CallbackTimerEnvioDatos, osTimerPeriodic, NULL, &TimerEnvioDatos_attributes);

  /* creation of TimerRecepcionDatos */
  TimerRecepcionDatosHandle = osTimerNew(TimerRecepcionDatosCallback, osTimerPeriodic, NULL, &TimerRecepcionDatos_attributes);

  /* USER CODE BEGIN RTOS_TIMERS */
  // osTimerStart(TimerLedEstadoHandle, TICKS_TAREA_LED);
  osTimerStart(TimerControlHandle, TICKS_TAREA_CONTROL);
  osTimerStart(TimerTomaDatosHandle, TICKS_TAREA_TOMA_DATOS);
#ifdef ENVIO_DATOS
  osTimerStart(TimerEnvioDatosHandle, TICKS_TAREA_ENVIO_DATOS);
#endif
#ifndef RECEPCION_DATOS
  osTimerStart(TimerRecepcionDatosHandle, TICKS_TAREA_RECEPCION_DATOS);
#endif
  /* USER CODE END RTOS_TIMERS */

  /* Create the queue(s) */
  /* creation of accion_controlXQueue */
  accion_controlXQueueHandle = osMessageQueueNew (5, sizeof(float), &accion_controlXQueue_attributes);

  /* creation of distXQueue */
  distXQueueHandle = osMessageQueueNew (5, sizeof(float), &distXQueue_attributes);

  /* USER CODE BEGIN RTOS_QUEUES */
  /* add queues, ... */
  /* USER CODE END RTOS_QUEUES */

  /* Create the thread(s) */
  /* creation of led_estadoTask */
  led_estadoTaskHandle = osThreadNew(Led_EstadoTask, NULL, &led_estadoTask_attributes);

  /* creation of controlTask */
  controlTaskHandle = osThreadNew(ControlTask, NULL, &controlTask_attributes);

  /* creation of toma_datosTask */
  toma_datosTaskHandle = osThreadNew(Toma_DatosTask, NULL, &toma_datosTask_attributes);

  /* creation of envio_datosTask */
  envio_datosTaskHandle = osThreadNew(Envio_DatosTask, NULL, &envio_datosTask_attributes);

  /* creation of recpecion_datos */
  recpecion_datosHandle = osThreadNew(Recepcion_DatosTask, NULL, &recpecion_datos_attributes);

  /* USER CODE BEGIN RTOS_THREADS */
  /* add threads, ... */
  /* USER CODE END RTOS_THREADS */

  /* USER CODE BEGIN RTOS_EVENTS */
  /* add events, ... */
  /* USER CODE END RTOS_EVENTS */

  /* Start scheduler */
  osKernelStart();

  /* We should never get here as control is now taken by the scheduler */
  /* Infinite loop */
  /* USER CODE BEGIN WHILE */
  while (1)
  {
    /* USER CODE END WHILE */

    /* USER CODE BEGIN 3 */
  }
  /* USER CODE END 3 */
}

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
/* USER CODE BEGIN Header_Led_EstadoTask */
/**
  * @brief  Function implementing the led_estadoTask thread.
  * @param  argument: Not used
  * @retval None
  */
/* USER CODE END Header_Led_EstadoTask */
__weak void Led_EstadoTask(void *argument)
{
  /* USER CODE BEGIN 5 */
  /* Infinite loop */
  for(;;)
  {}
  /* USER CODE END 5 */
}

/* USER CODE BEGIN Header_ControlTask */
/**
* @brief Function implementing the controlTask thread.
* @param argument: Not used
* @retval None
*/
/* USER CODE END Header_ControlTask */
__weak void ControlTask(void *argument)
{
  /* USER CODE BEGIN ControlTask */
  /* Infinite loop */
  for(;;)
  {
  }
  /* USER CODE END ControlTask */
}

/* USER CODE BEGIN Header_Toma_DatosTask */
/**
* @brief Function implementing the toma_datosTask thread.
* @param argument: Not used
* @retval None
*/
/* USER CODE END Header_Toma_DatosTask */
__weak void Toma_DatosTask(void *argument)
{
  /* USER CODE BEGIN Toma_DatosTask */
  /* Infinite loop */
  for(;;)
  {}
  /* USER CODE END Toma_DatosTask */
}

/* USER CODE BEGIN Header_Envio_DatosTask */
/**
* @brief Function implementing the envio_datosTask thread.
* @param argument: Not used
* @retval None
*/
/* USER CODE END Header_Envio_DatosTask */
__weak void Envio_DatosTask(void *argument)
{
  /* USER CODE BEGIN Envio_DatosTask */
  /* Infinite loop */
  for(;;)
  {}
  /* USER CODE END Envio_DatosTask */
}

/* USER CODE BEGIN Header_Recepcion_DatosTask */
/**
* @brief Function implementing the recpecion_datos thread.
* @param argument: Not used
* @retval None
*/
/* USER CODE END Header_Recepcion_DatosTask */
__weak void Recepcion_DatosTask(void *argument)
{
  /* USER CODE BEGIN Recepcion_DatosTask */
  /* Infinite loop */
  for(;;)
  {}
  /* USER CODE END Recepcion_DatosTask */
}

/* CallbackTimerLedEstado function */
void CallbackTimerLedEstado(void *argument)
{
  /* USER CODE BEGIN CallbackTimerLedEstado */
	osThreadFlagsSet(led_estadoTaskHandle, FLAG_ID);
  /* USER CODE END CallbackTimerLedEstado */
}

/* CallbackTimerControl function */
void CallbackTimerControl(void *argument)
{
  /* USER CODE BEGIN CallbackTimerControl */
	osThreadFlagsSet(controlTaskHandle, FLAG_ID);
  /* USER CODE END CallbackTimerControl */
}

/* CallbackTimerTomaDatos function */
void CallbackTimerTomaDatos(void *argument)
{
  /* USER CODE BEGIN CallbackTimerTomaDatos */
	osThreadFlagsSet(toma_datosTaskHandle, FLAG_ID);
  /* USER CODE END CallbackTimerTomaDatos */
}

/* CallbackTimerEnvioDatos function */
void CallbackTimerEnvioDatos(void *argument)
{
  /* USER CODE BEGIN CallbackTimerEnvioDatos */
	osThreadFlagsSet(envio_datosTaskHandle, FLAG_ID);
  /* USER CODE END CallbackTimerEnvioDatos */
}

/* TimerRecepcionDatosCallback function */
void TimerRecepcionDatosCallback(void *argument)
{
  /* USER CODE BEGIN TimerRecepcionDatosCallback */
#ifndef RECEPCION_DATOS
	osThreadFlagsSet(recpecion_datosHandle, FLAG_ID);
#endif
  /* USER CODE END TimerRecepcionDatosCallback */
}

 /**
  * @brief  Period elapsed callback in non blocking mode
  * @note   This function is called  when TIM3 interrupt took place, inside
  * HAL_TIM_IRQHandler(). It makes a direct call to HAL_IncTick() to increment
  * a global variable "uwTick" used as application time base.
  * @param  htim : TIM handle
  * @retval None
  */
void HAL_TIM_PeriodElapsedCallback(TIM_HandleTypeDef *htim)
{
  if (htim->Instance == TIM3) {
    HAL_IncTick();
  }
}

/**
  * @brief  This function is executed in case of error occurrence.
  * @retval None
  */
void Error_Handler(void)
{
  /* USER CODE BEGIN Error_Handler_Debug */
  /* User can add his own implementation to report the HAL error return state */

  /* USER CODE END Error_Handler_Debug */
}

#ifdef  USE_FULL_ASSERT
/**
  * @brief  Reports the name of the source file and the source line number
  *         where the assert_param error has occurred.
  * @param  file: pointer to the source file name
  * @param  line: assert_param error line source number
  * @retval None
  */
void assert_failed(uint8_t *file, uint32_t line)
{
  /* USER CODE BEGIN 6 */
  /* User can add his own implementation to report the file name and line number,
     tex: printf("Wrong parameters value: file %s on line %d\r\n", file, line) */
  /* USER CODE END 6 */
}
#endif /* USE_FULL_ASSERT */

/************************ (C) COPYRIGHT STMicroelectronics *****END OF FILE****/

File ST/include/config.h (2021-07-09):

#ifndef CONFIG_H
#define CONFIG_H

// CONFIGURACIÓN DE PROGRAMA

// Selección de sensor
// #define DATOS_TFT
#define DATOS_CAM

// Selección de controlador
#define CONTROL_PID
// #define CONTROL_LQR

// Configuración del envío y recepción de datos
// #define RECEPCION_DATOS

#define ENVIO_DATOS
#ifdef ENVIO_DATOS
	#define ENVIO_UART
	
	#define ENVIO_X
	// #define ENVIO_Y
	// #define ENVIO_XY
#endif


// Modo de calibración de los ángulos de la estructura
// #define CALIBRACION_ESTRUCTURA

// Unidades angulares
#define VC_DEG 360.0
#define VC_RAD (2.0*3.1415926)
#define VUELTA_COMPLETA VC_RAD // VC_DEG

// Controlador TFT
#define ADDR_READ_TFT 0x9B
#define ADDR_WRITE_TFT 0x9A
#define GPIO_RTS_TFT GPIOC
#define PIN_RTS_TFT GPIO_PIN_0

// Controlador Cámara
#define GPIO_RTS_CAM GPIOC
#define PIN_RTS_CAM GPIO_PIN_0

// Tiempo de muestreo
#define SAMPLE_TIME_S (float)(5.0/1000.0) // Periodo de ejecución de la tarea de control (y de muestreo de la cámara)

// PID 
#define PID_LIM_MAX (float) VUELTA_COMPLETA/12 // VUELTA_COMPLETA/12 // Aprox. 20º - 30º
#define PID_LIM_MIN (float) -PID_LIM_MAX
#define PID_LIM_MIN_INT PID_LIM_MIN/2
#define PID_LIM_MAX_INT PID_LIM_MAX/2

// Parámetros PID
#define PID_KP (float)(1.6)  // PID4-8: (138.0) 8-12: (250.0663) 12-17: (193) 18:(270.0663) 21-22: (0.64) Para cam: 160.0663 0.4
#define PID_KI (float)(0.0)
#define PID_KD (float) (0.6)// (58.0)  // PID4-8: (40.0) 8-12: (57.9335) 12-17: (41) 18:(57.9335) 21-22:(0.15) Para cam: 57.0 2.2
#define PID_TAU (float)(0.0) // (0.00159) 		// Cte de tiempo del filto paso bajo de la componente derivativa

// LQR
#define DIM_C1 2
#define DIM_C2 4
#define DIM_C {DIM_C1, DIM_C2}
#define MAT_C {0.0,7.0,0.0,0.0, 0.0,0.0,0.0,7.0}

#define DIM_X1 4
#define DIM_X2 1
#define DIM_X {DIM_X1, DIM_X2}
#define MAT_X {0,0,0,0}

#define DIM_K1 2
#define DIM_K2 4
#define DIM_K {DIM_K1, DIM_K2}
#define MAT_K {1,0.5354,0.0,0.0, 0.0,0.0,1,0.5345}

#define DIM_R1 2
#define DIM_R2 1
#define DIM_R {DIM_R1, DIM_R2}
#define MAT_R {1,1}

#define Kr 1

// Servo-motores
#define MAX_ANG PID_LIM_MAX // VUELTA_COMPLETA/12
#define MIN_ANG -MAX_ANG
#define SERVO_TIMER_PERIOD (uint16_t)(16000 - 1)

// Otros parámetros
#define ADC_RES 12 // bits
#define MAX_ADC_VAL_TFT 4096.0

// Tamaó de la imágen de la cámara
#define PIXELS_Y 120.0 //  160.0 También puede ser superior pero la velocidad del muestro disminuye
#define PIXELS_X 80.0 //  120.0


// Tamaño de la estructura
// Para TFT
#ifdef DATOS_TFT
#define LONG_Y  (19.0 / 100.0)
#define LONG_X  (25.0 / 100.0)
#endif
// Para cámara
#ifdef DATOS_CAM
#define LONG_Y  (21.0 / 100.0)
#define LONG_X  (16.0 / 100.0)
#endif

// Correcciones del ángulo de la estructura
//Para TFT
#ifdef DATOS_TFT
#define ERROR_ANG_X -VUELTA_COMPLETA/142
#define ERROR_ANG_Y VUELTA_COMPLETA/70
#endif
// Para cámara
#ifdef DATOS_CAM
#define ERROR_ANG_X VUELTA_COMPLETA/393
#define ERROR_ANG_Y VUELTA_COMPLETA/50
#endif

// Tamaño del buffer para envio de datos
#define SIZE_SEND_DATA 10

// Relación ang servo con estrcutura
#define GRADO_TF_ANG_PLATF_SERVO 3
#define TF_ANG_PLATF_SERVO {0.0009, 0.0072, 2.2486, -0.0953}; // En rad: {-0.0588, -0.0184, 0.4360, -0.0006}; 

//  Señal de consigna
#ifdef RECEPCION_DATOS
	#define TIME_SETPOINT_S 1
#else
	#define MAX_SIZE_BUFFER_SETPOINT 8
    #define MAX_SETPOINT_MODES 3

	#define TIME_SETPOINT_ZERO_S 3 // segundos
	#define SIZE_BUFFER_ZERO_SETPOINT 1

	#define TIME_SETPOINT_INFINITO_S 0.5 // segundos
	#define SIZE_BUFFER_INFINITO_SETPOINT 8

#define TIME_SETPOINT_RECTANGULO_S 2.5 // segundos
	#define SIZE_BUFFER_RECTANGULO_SETPOINT 4
#endif

// Recorido de la de la esfera en los modos de demostración
#ifdef DATOS_TFT
	#define MAX_DISTX 5.0 // (cm) La máxima distancia a la que se lleva la bola al hacer las figuras
	#define MAX_DISTY 3.5
#else 
	#ifdef DATOS_CAM // Para la cámara es más pequeña debido al tamaño de su plataforma
		#define MAX_DISTX 3.0
		#define MAX_DISTY 3.0
	#endif
#endif

#define BUFFER_ZERO {{0.0,0.0}}
#define BUFFER_INFINITO {{0,0}, {-MAX_DISTX,0}, {-MAX_DISTX*1.3,-MAX_DISTY*1.3}, {0,-MAX_DISTY}, {0,0}, {0,MAX_DISTY}, {MAX_DISTX*1.3, MAX_DISTY*1.3}, {MAX_DISTX,0}}
#define BUFFER_RECTANGULO {{MAX_DISTX,MAX_DISTY},{MAX_DISTX,-MAX_DISTY},{-MAX_DISTX,-MAX_DISTY},{-MAX_DISTX,MAX_DISTY}}


// SISTEMA OPERATIVO
#define SYS_FREQ_HZ configTICK_RATE_HZ

// Definición de los tiempo de ejecución de las tareas
#define MS_TAREA_LED 200 // ms
#define MS_TAREA_CONTROL SAMPLE_TIME_S*1000 // ms = s * 1000
#define MS_TAREA_TOMA_DATOS MS_TAREA_CONTROL // ms
#define MS_TAREA_ENVIO_DATOS MS_TAREA_CONTROL*3 // ms

#define TICKS_TAREA_LED (uint32_t)( MS_TAREA_LED * SYS_FREQ_HZ / 1000 )
#define TICKS_TAREA_CONTROL (uint32_t)( MS_TAREA_CONTROL * SYS_FREQ_HZ / 1000 )
#define TICKS_TAREA_TOMA_DATOS (uint32_t)( MS_TAREA_TOMA_DATOS * SYS_FREQ_HZ / 1000 )
#define TICKS_TAREA_ENVIO_DATOS (uint32_t)( MS_TAREA_ENVIO_DATOS * SYS_FREQ_HZ / 1000 )
#define TICKS_TAREA_RECEPCION_DATOS (uint32_t)( TIME_SETPOINT_ZERO_S * SYS_FREQ_HZ )
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

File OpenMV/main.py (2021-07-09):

# Open_MV_CAM - By: Martin - feb. 10 2021

# Valores para la detección de la esfera
RADIO_MAX = 7
RADIO_MIN = 2

import sensor, image, time
from pyb import Pin, SPI, UART, I2C
import utime

# cs  = Pin("P3", Pin.OUT_OD)
# rst = Pin("P7", Pin.OUT_PP)
# rs  = Pin("P8", Pin.OUT_PP)


# Variable circulo "falso"
class circulo_falso_t:
    def __init__(self, posX, posY):
        self.posx = posX
        self.posy = posY
    def x(self):
        return self.posx
    def y(self):
        return self.posy

circulo_falso = circulo_falso_t(180,150)

# Inicialización de la cámara
sensor.reset()
sensor.set_pixformat(sensor.RGB565)
sensor.set_framesize(sensor.HQQVGA)
sensor.skip_frames(time = 2000)

# Inicialización de la comunicación
# spi = SPI(2, SPI.SLAVE,  polarity=0, phase=0)
# i2c = I2C(2, I2C.SLAVE, addr=0x42)
uart = UART(1, 115200);
# rs = Pin("P8", Pin.OUT_PP)
# rs.high()

def send_data(c):
    # Se envía la posción del círculo
    bytx = c.x().to_bytes(1,'little')
    byty = c.y().to_bytes(1,'little')
    # print(c.x())
    byt = bytearray(2)
    byt = byty + bytx
    # Se activa (a nivel bajo) la señal ReadyToSend
    # rs.low()
    try:
        # print(byt)
        # spi.send(byt, timeout=10)
        # i2c.send(byt, timeout=10)
        uart.write(byt);
    except:
        utime.sleep_us(500)
        # print("com fallida")
    # Se desactiva la señal ReadyToSend
    # rs.high()

def en_rango(radio):
    if ((radio>=RADIO_MIN) and (radio<=RADIO_MAX)):
        return True
    return False


while(True):
    # Se toma una imagen
    img = sensor.snapshot().lens_corr(1.8)

    # Se obtienen los círculos
    list_c = img.find_circles(threshold = 2000, x_margin = 10, y_margin = 10, r_margin = 10,    # Se ajustan los parámetros para que sólo detecte el cículo
                                         r_min = 1, r_max = 20, r_step = 2)                     # correspondiente a la esfera
    # Si no se han detectado círculos
    if not list_c:
        send_data(circulo_falso)
    else:
        for c in list_c:
            img.draw_circle(c.x(), c.y(), c.r(), color = (255, 0, 0))
            # Se comprueba que el tamaño del círculo es el deseado
            if(en_rango(c.r())):
                img.draw_circle(c.x(), c.y(), c.r(), color = (0, 255, 0))
                # Se envía el círculo detectado, o no, al microncontrolador
                send_data(c)
                break
            else:
                send_data(circulo_falso)

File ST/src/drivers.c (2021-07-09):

#include "drivers.h"
#include "math.h"

// Variables globales
float tf_ang_platf_serv[GRADO_TF_ANG_PLATF_SERVO + 1] = TF_ANG_PLATF_SERVO;

// Controlador del PWM
void PWM_controller_init(PWM_Controller_t *this, TIM_HandleTypeDef *tim, uint32_t tim_channel, uint32_t timer_period, float ang_max, float ang_min){
	// Inicialización de  varibales
	this->timer = tim;
	this->timer_channel = tim_channel;
	this->servo_timer_period = timer_period;
	this->max_ang = ang_max;
	this->min_ang = ang_min;
}

// Función que modifica la señal PWM en función del ángulo obtjetivo de un servo-motor  
void set_PWM(PWM_Controller_t *this, float ang){
	// Normalización del ángulo a menos de una revolución
	while (ang > VUELTA_COMPLETA){
		ang = ang - VUELTA_COMPLETA;
	}
	while (ang < 0){
		ang = ang + VUELTA_COMPLETA;
	}

	// Normalizar el ángulo a +- 90º
	if ((ang > VUELTA_COMPLETA/4) && (ang < VUELTA_COMPLETA*(3.0/4.0))){ // Ángulo en el segundo o tercer cuadrante cuadrante
		ang = ang - VUELTA_COMPLETA/2;
	}
	else if (ang > VUELTA_COMPLETA/4){ // Ángulo en el cuarto cuadrante
		ang = ang - VUELTA_COMPLETA;
	}

	// Se limita al ángulo que permite girar el servomotor
	if (ang > this->max_ang){
		ang = this->max_ang;
	}
	else if (ang <  this->min_ang){
		ang = this->min_ang;
	}

	// Cálculo del ciclo de trabajo
	float ang_norm_ms = (((ang > VUELTA_COMPLETA/2)? ang - VUELTA_COMPLETA:ang) / (VUELTA_COMPLETA/3));
	float DutyCicle =  (1.5 + ang_norm_ms) / 20 * 100;

	// Setup del timer que gestiona el PWM
	float PulseValue = ((float)(this->servo_timer_period + 1) * DutyCicle) / 100 - 1;
	__HAL_TIM_SET_COMPARE(this->timer, this->timer_channel, PulseValue);
}

// Controlador del ADC
void ADC_Conv_init(ADC_Converter_t *this, uint32_t adc_max_val, float max_range){
	// Inicialización de la escrutura
	this->ADC_MAX_Val = adc_max_val;
	this->range = max_range;
}

// Función que trasnforma el valor obtenido de un ADC a un rango determinado
void convADC2dist(ADC_Converter_t *this, float *dist, uint16_t adc_value){
	// Distancia al eje X
	float norm_dist = ((float)adc_value / this->ADC_MAX_Val) * this->range;
	*dist = norm_dist - (float)(this->range/2); // Distancia al eje X

}

// Función que obtiene el ángulo del servo-motor necesario para una determinada inclinación de la plataforma
void calculo_ang_servo(const float *ang_platf, float *ang_servo){
	int i;
	
	// Se obtiene el ángulo en grados sexagesimales
	float ang_aux = *ang_platf * ((VUELTA_COMPLETA == VC_DEG)? 1: VC_DEG/VC_RAD);
	
	// Realizamos la operación de trasnformación
	*ang_servo = tf_ang_platf_serv[GRADO_TF_ANG_PLATF_SERVO];
	for (i=0; i<GRADO_TF_ANG_PLATF_SERVO; i++){
		*ang_servo += tf_ang_platf_serv[i] * pow(ang_aux, GRADO_TF_ANG_PLATF_SERVO-i);
	}
	
	// Transformamos el ángulo obtenido al sistema en el que estemos trabajando
	*ang_servo *= ((VUELTA_COMPLETA == VC_DEG)? 1: VC_RAD/VC_DEG);
}

// Función que corrige la posición de la esfera en función del ángulo de inclinación de la plataforma (Sólo usado en la cámara)
void ajuste_pos_bola(const float *ang, float *dist){
	
	float ang_aux;
	
	ang_aux = (VUELTA_COMPLETA == VC_RAD)? *ang:(*ang / VC_DEG * VC_RAD);
	*dist /= cos(ang_aux); // se ha cambiado

}

// Función que transfroma la trama obtenida por el controlador de la platalla resistiva a un valor ADC de 12 bits 
void procesado_datos_TFT(uint16_t *DatosX, uint16_t *DatosY, const uint8_t* pData){
	// Los datos se reciben en paquetes de 1 byte
	// Parma más información leer datasheet de AR1000 Series Resistive Touch Screen Controller
	// Datos en eje X
	uint16_t Datos_High =  pData[2] << 7;	// Primer byte de datos
	uint16_t Datos_Low = pData[1];			// Segundo byte de datos
	*DatosX = Datos_High | Datos_Low;		// Unión de ambos datos

	// Datos en eje X
	Datos_High =  pData[4] << 7;
	Datos_Low = pData[3];
	*DatosY = Datos_High | Datos_Low;
}

// Función que transfroma la trama obtenida por la cámara a un valor entero
void procesado_datos_CAM(uint8_t *DatosX, uint8_t *DatosY, const uint8_t *pData){
	// Se reciben dos bytes, el primer byte es el pixel Y
	// Para más información observar el protocolo de comunicación del fichero main de la cámara
	//	y el segundo es el pixel X
	// Datos de X
	*DatosX = pData[1]; // DatosX corresponde con el segundo byte de la trama(2 bytes)
	// Datos de Y
	*DatosY = pData[0]; // DatosY corresponde con el primer byte de la trama(2 bytes)
}

// Función privada para gestión de la incicialización Hardware del LED_Controller_t
void _init_LED(LED_Controller_t *this){
	GPIO_InitTypeDef GPIO_InitStruct = {0};

	/* GPIO Ports Clock Enable */
	__HAL_RCC_GPIOA_CLK_ENABLE();
	__HAL_RCC_GPIOD_CLK_ENABLE();
	__HAL_RCC_GPIOB_CLK_ENABLE();

	/*Configure GPIO pin Output Level */
	HAL_GPIO_WritePin(this->Gpio, this->pin, GPIO_PIN_RESET);

	/*Configure GPIO pins */
	GPIO_InitStruct.Pin = this->pin;
	GPIO_InitStruct.Mode = GPIO_MODE_OUTPUT_PP;
	GPIO_InitStruct.Pull = GPIO_NOPULL;
	GPIO_InitStruct.Speed = GPIO_SPEED_FREQ_LOW;
	HAL_GPIO_Init(this->Gpio, &GPIO_InitStruct);
}

// Controlador de leds
void LED_controller_init(LED_Controller_t *this, GPIO_TypeDef *GPIOX, uint16_t GPIO_PIN){
	// Se guardan las variables
	this->pin = GPIO_PIN;
	this->Gpio = GPIOX;
	
	// Inicialización Hardware
	_init_LED(this);
}

// Función que activa el LED
void encender_led(LED_Controller_t *this){
	HAL_GPIO_WritePin(this->Gpio, this->pin, GPIO_PIN_SET);
}

// Función que descativa el LED
void apagar_led(LED_Controller_t *this){
	HAL_GPIO_WritePin(this->Gpio, this->pin, GPIO_PIN_RESET);
}

// Función que modifica el estado del LED
void toggle_led(LED_Controller_t *this){
	HAL_GPIO_TogglePin(this->Gpio, this->pin);
}

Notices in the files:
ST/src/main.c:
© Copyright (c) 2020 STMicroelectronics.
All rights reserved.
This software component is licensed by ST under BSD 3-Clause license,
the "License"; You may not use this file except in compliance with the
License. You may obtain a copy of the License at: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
